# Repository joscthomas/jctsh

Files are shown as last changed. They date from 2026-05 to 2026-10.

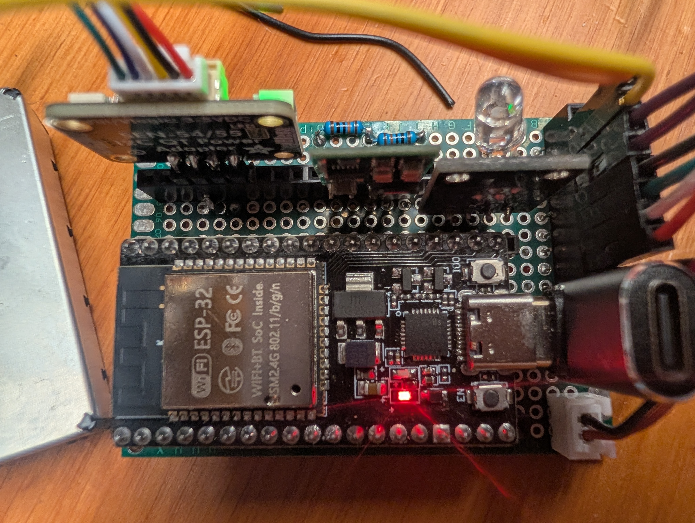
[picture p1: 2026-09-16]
components/air-quality-monitor/perfboard_3.jpg

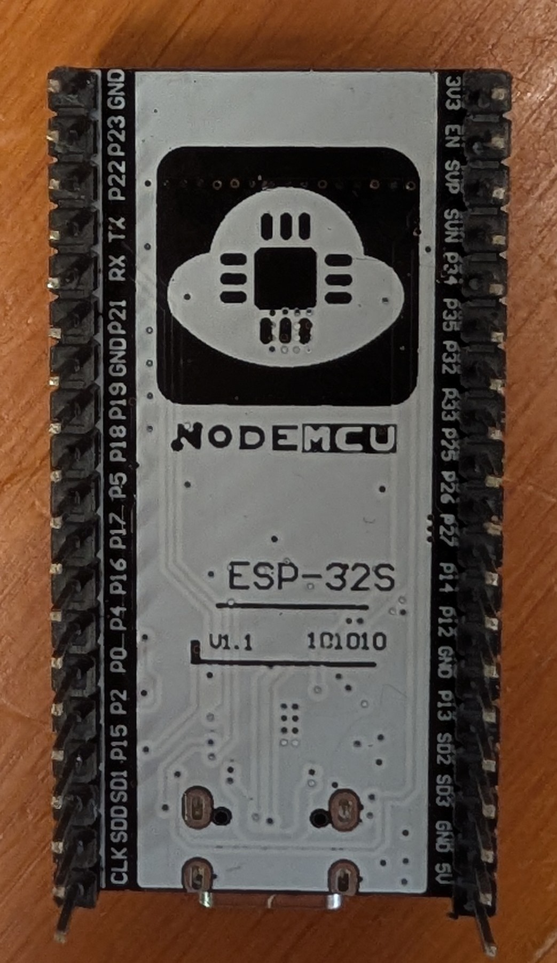
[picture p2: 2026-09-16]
components/back-patio-temp-sensor/esp32-pins-photo.jpg

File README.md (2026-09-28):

# JCTsh — Smart Home Automation
Joseph C Thomas | Tucson, AZ

DIY smart home automation system built on Raspberry Pi, MQTT, Node-RED, and Home
Assistant — connecting ESP32 sensors, garage automation, an RV coach interface, and
environmental monitoring into a single integrated ecosystem.

---

## System Status

| Component | What it does | Status |
|---|---|---|
| [salt-sensor](components/salt-sensor/) | Water softener salt level monitor with SmartThings alerts | Production |
| [garage-radar](components/garage-radar/) | 24GHz mmWave workbench presence sensor | Production |
| [garage-presence](components/garage-presence/) | Garage presence countdown timer and lights automation | Production |
| [traveling](components/traveling/) | Randomized occupancy-simulation lighting + unexpected-TV-activity alert while traveling | Production |
| [outdoor-presence-detection](components/outdoor-presence-detection/) | Ring motion voice announcement (doorbell live video deactivated 2026-08-21, CARD-0187 on hold) | Production |
| [automatic-garage-door-opener-closer](components/automatic-garage-door-opener-closer/) | Voice and auto-close control for LiftMaster opener | Production |
| [equip-shelf](components/equip-shelf/) | Physical shelf housing the Pi, M8, SmartThings hub, garage relay, router, and cooling fans | Production |
| [front-porch-temp-sensor](components/front-porch-temp-sensor/) | Front porch temperature, pressure, and light with push notifications | Production |
| [p-w-firefly](components/p-w-firefly/) | Firefly Integrations RV-C coach interface for Pleasure-Way Lexor FL | Production |
| [photo-server](components/photo-server/) | Self-hosted Immich photo/video library, runs on the M8 (`hosts/m8/`) | Production |
| [photo-quality-review](components/photo-quality-review/) | Finds duplicate/blurry/broken images across Immich libraries, review UI to confirm deletions | Production |
| [photo-tv-display](components/photo-tv-display/) | Ambient photo slideshow + phone controller for Google TV, backed by m8 | In Progress |
| [netalertx](components/netalertx/) | Translates NetAlertX's MQTT firehose into JCTsh-shaped log events + heartbeat | Production |
| [jctsh-menu](components/jctsh-menu/) | Tasker menu task routing to any component's webhook by name, not a running service | Production |
| [hiking-monitor](components/hiking-monitor/) | Portable environmental sensor — logs to flash during hikes, syncs on return | Production |
| [hike-izer](components/hike-izer/) | Turns raw hiking-monitor data into a narrative HTML hike summary | Production |
| [hike-izer-orchestrator](components/hike-izer-orchestrator/) | Webhook receiver/generator that triggers Hike-izer automatically | Production |
| [hike-izer-web](components/hike-izer-web/) | Publishes Hike-izer's generated summaries at `hikes.jctnet.com` | Production |
| [weather-station](components/weather-station/) | Outdoor DIY weather station posting to Weather Underground and Google Sheets | Planned |
| [air-quality-monitor](components/air-quality-monitor/) | Portable PM/VOC/NOx sensor carried on hikes alongside the hiking monitor | In Progress |
| [van-sensors](components/van-sensors/) | Indoor and outdoor environmental nodes for the Pleasure-Way ProMaster van | Planned |
| [remote-temp-sensor-01](components/remote-temp-sensor-01/) | Solar/battery-powered backyard temp, humidity, pressure, light, and UV sensor | Planned |
| [bedside-clock](components/bedside-clock/) | Battery-powered, tap-to-wake bedside clock for the camper van, DS3231-timed with occasional WiFi/NTP timezone correction | Planned |

---

## What It Is

JCTsh is a personal smart home automation system for a single-family home in Tucson,
Arizona, built entirely from off-the-shelf hardware and open-source software. It has no
cloud dependencies except Home Assistant Cloud (Nabu Casa) and SmartThings for phone and
voice integration.

Each component is a self-contained unit with its own firmware, Node-RED flow, and
documentation. All components share a common infrastructure layer — a Raspberry Pi running
Mosquitto, Node-RED, Home Assistant, and a Python log server.

---

## Quick Start — Accessing the System

All services run on the home Raspberry Pi. On the home network:

| Service | URL | Notes |
|---|---|---|
| Log dashboard | http://pi1.local/ | Basic Auth — user: `jctsh` |
| Node-RED | http://pi1.local:1880 | Flow editor |
| Home Assistant | http://pi1.local:8123 | |
| MQTT broker | pi1.local:1883 | Requires auth — credentials in `credentials.local.md` |

Remote access via Tailscale: replace `pi1.local` with `100.70.162.24`.

See [network/jctsh-access.md](network/jctsh-access.md) for the full access reference including RV and Tailscale setup.

---

## Architecture

Every component follows the same message flow:

```
ESP32 sensor
    │  MQTT publish
    ▼
Mosquitto broker  (Raspberry Pi)
    │
    ├──► Node-RED        — logic, thresholds, external HTTP calls
    │        │
    │        ├──► Google Sheets / Weather Underground
    │        └──► Home Assistant REST API
    │                  │
    │                  └──► SmartThings ──► Google Home / Pixel notifications
    │
    └──► Python log server  — http://pi1.local/
```

Each component produces two parallel message streams: a **data stream**
(`jctsh/<type>/<component>/data`) driving automations, and a **log stream**
(`jctsh/<type>/<component>/log`) routed to the dashboard.

For full architecture details, MQTT topic conventions, credentials structure, and
infrastructure configuration, see [CLAUDE.md](CLAUDE.md).

---

## Repository Layout

```
jctsh/
├── components/                    Individual automation components — one subdirectory each
├── core/                          Shared infrastructure running on the Raspberry Pi
├── tos/                           Team Operating System — kanban board, process definition,
│                                       and auto-PR intake/landing tooling (see tos/README.md)
├── CLAUDE.md                      Claude Code context — architecture, conventions, infrastructure
├── DEVLOG.md                      Chronological record of decisions and incidents
├── ENVIRONMENT.md                 Physical device inventory for the home
├── SOFTWARE-ENVIRONMENT.md        What is installed and running on the Pi
├── WORKSTATION-SETUP.md           What the dev/flashing workstation needs installed (Python,
│                                       ESPHome, SSH, filesystem gotchas) — CARD-0357
├── workstation-verify.ps1         Checks the workstation's actual state against
│                                       WORKSTATION-SETUP.md — verify-only — CARD-0360
├── network/jctsh-network.md       IP address and MAC table for all devices
├── network/jctsh-access.md        How to reach all services from any network
├── network/keepconnect.md         KeepConnect router rebooter — config, schedule, rationale
├── jctsh-parts-inventory.md       On-hand electronics parts
├── JCTsh-Build-Standards.md       Standards all components must follow
├── JCTsh-Component-Planning-Pattern.md  How new components are planned and built
├── JCTsh-Perfboard-Build-Template.md    Reusable section skeleton for a component's
│                                             perfboard-layout.md (breadboard → perfboard transfer)
├── core/data-pipeline/JCTsh-Environmental-Data-Architecture.md  Payload schema and pipeline
│                                             for all environmental sensors
├── JCTsh-Property-Sensor-Pattern.md         Standard pattern for all property sensors —
│                                             invariant standard, variable dimensions,
│                                             new-sensor checklist
└── house-lot-coordinates.md               Lat/lon for property corners, house footprint
                                              corners, and named points (e.g. front porch) —
                                              use these when hardcoding coordinates in firmware
```

### components/

One subdirectory per automation component. Each contains a `README.md` — see the
Status table above for the full list.

### core/

Shared infrastructure not specific to any one component.

| Directory | Contents |
|---|---|
| `core/data-pipeline/` | Environmental Data Apps Script + Node-RED flow — GPS/sensor correlation pipeline shared across hiking-monitor, air-quality-monitor, front-porch-temp-sensor, and back-patio-temp-sensor — see [core/data-pipeline/README.md](core/data-pipeline/README.md) |
| `core/homeassistant/` | HA configuration snapshot (version-controlled copy — live copy is on Pi) — see [core/homeassistant/README.md](core/homeassistant/README.md) |
| `core/logging/` | Python MQTT log server — see [core/logging/README.md](core/logging/README.md) |
| `core/mqtt/` | Mosquitto configuration (version-controlled copy) — see [core/mqtt/README.md](core/mqtt/README.md) |
| `core/node-red/` | Shared Node-RED flows and settings (version-controlled copies) |
| `core/offline-logger/` | Reusable offline flash logging template (`sensor_logger.h`) — copy and rename for each intermittently-connected sensor |
| `core/maintenance/` | Scheduled-reboot systemd units and maintenance/update-check scripts, deployed to the Pi and M8 — see [core/maintenance/README.md](core/maintenance/README.md) |
| `core/docker/` | Docker daemon config (DNS pinning, journald log driver, containerd data-root) for hosts running containers — see [core/docker/README.md](core/docker/README.md) |

---

## Document Types

| Document | Purpose | Where to find it |
|---|---|---|
| `README.md` | What a component does, how to run it, doc index | Every component directory |
| `CLAUDE.md` | Context and constraints for Claude Code sessions | Repo root + component directories |
| `kanban-board.md` | Kanban board — all planned and in-progress work | `tos/` |
| `DEVLOG.md` | Why decisions were made; significant incidents | Repo root |
| `*-phase1.md` / `*-planning.md` | Pre-build discovery — decisions, BOM, architecture choices | Component directory |
| `*-claude-code-instructions.md` | Step-by-step build instructions executed with Claude Code | Component directory |
| `JCTsh-*.md` | Monorepo-wide standards all components must conform to | Repo root |
| `wiring.md` | Pin assignments and breadboard wiring reference | Component directory |
| `ESP32-project-pins.md` | Full 38-pin assignment table for the component's ESP32 | Component directory |
| `perfboard-layout.md` | Permanent soldered build layout | Component directory |
| `flashing.md` | First flash and OTA update procedure | Component directory |
| `testing.md` / `end-to-end-test.md` | Test procedures and pass/fail criteria | Component directory |
| `integration.md` | How the component connects to HA, SmartThings, or other systems | Component directory |
| `operations.md` | Day-to-day use and troubleshooting | Component directory |
| `network/jctsh-network.md` | IP, hostname, and MAC for every device | `network/` |
| `network/jctsh-access.md` | How to reach every service from home, remote, or RV | `network/` |
| `credentials.local.md` | All generated passwords — gitignored, never committed | Repo root |

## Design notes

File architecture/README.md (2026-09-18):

# architecture/ — Cross-Cutting Architecture and Operational Decisions

Doc-only directory (no executable code) for cards that are genuinely cross-cutting —
not owned by any single component, core service, or host. Created 2026-09-18 (CARD-0294)
specifically to give the residual bucket of `[infrastructure]`-tagged cards a real home,
once host-specific and component-specific ones were retagged to `[m8]`/`[pi1]`/their
actual component.

**What belongs here:** strategy decisions spanning multiple systems (SmartThings API
strategy, MQTT security posture), standards that apply to a whole class of future
components rather than one existing directory (backyard-device power patterns, battery
build standards before they were harvested into `JCTsh-Build-Standards.md`), and
whole-repo audits (security hardening, disaster recovery, cross-host reboot behavior).

**What doesn't:** anything that fits a real `components/<name>/`, `core/<name>/`, or
`hosts/<name>/` directory once actually checked — see `JCTsh-Operating-System.md`'s
Engineering Discipline section on investigating before assuming a card can't be
reconciled.

## Files

| File | Purpose |
|---|---|
| `CLAUDE.md` | Curated context — currently a stub |
| `card-archive.md` | Archived `[architecture]`-tagged card history (created on first use by `archive_cards.py`) |

## Related

- `kanban-board.md` CARD-0294 — the tag reconciliation that created this directory.
- `JCTsh-Operating-System.md`'s Documentation Structure section — the README-vs-CLAUDE.md
  split this directory follows like any other.

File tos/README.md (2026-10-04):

# tos/ — Team Operating System

CARD-0191: this directory consolidates JCTsh's "Team Operating System" (TOS) —
the kanban board itself, the process governing how work moves through it, and
the tooling that lets ideas/findings get onto the board from outside a
Claude Code session (voice, email, automated maintenance checks). Before
this, these pieces were scattered across the repo by whichever
infrastructure happened to be convenient to host them on, not by any
conceptual grouping — see CARD-0191 on `kanban-board.md` for the full
before/after inventory.

**Start with `JCTsh-Operating-System.md` for the actual process definition**
(board columns, state-transition triggers, the Build → Done Reflection
requirement, the commit/push relationship). This file is the index of what's
here and how the pieces fit together — it doesn't repeat that content.

## What's here

| File | Role |
|---|---|
| `kanban-board.md` | The board itself — every card, its status, and its full history. |
| `kanban-archive.md` | Dated archive of Done/Defer cards moved out of `kanban-board.md` by size, when no single `components/<name>/`/`core/<name>/`/`hosts/<name>/` home fits (CARD-0193). |
| `archive_cards.py` | The archiving tool behind `kanban-archive.md` and every `card-archive.md` below — size-primary trigger, `--force`/`--apply` dry-run-by-default, provenance annotations (CARD-0193). Manual, not on a timer — see `CLAUDE.md`'s periodic Session Start reminder. |
| `CLAUDE.md` | This directory's own curated context stub — archived card history lives in `card-archive.md` instead (CARD-0290). |
| `card-archive.md` | `[tos]`-tagged cards' archived history, split out of `CLAUDE.md` (CARD-0290). On-demand only, never routine reading — same pattern every `components/<name>/`/`core/<name>/`/`hosts/<name>/` directory now follows. |
| `JCTsh-Operating-System.md` | The process definition — columns, triggers, Reflection requirement, Engineering Discipline, Documentation Structure. Read once per session (see `CLAUDE.md`'s Session Start). |
| `JCTsh-Session-Card-Selection.md` | Four ordered factors for which card a session actually picks up next, distinct from the Priority tag (CARD-0288). |
| `JCTsh-Component-Session-Start.md` | Extended startup steps for a persistent component/cluster session, on top of `CLAUDE.md`'s general Session Start (CARD-0284/CARD-0290). |
| `open_kanban_pr.py` | `open_finding_pr()` / `resolve_and_merge()` — opens a placeholder-stub PR against `kanban-board.md` for any finding/idea, and lands a reviewed PR as a real numbered card at merge time. Imported (as a sibling module) by `email-idea-check.py`, `pi-maintenance-check.py`, `maintenance-check.py`, and `hike-izer-orchestrator`'s `/webhook/idea` route. |
| `land_pr_card.py` | Interactive-only script Claude runs (never automated) to land a PR as a fully-interviewed, real card — not just a renumbered stub. See its own docstring for the distinction from `resolve_and_merge()`. |
| `pr-review-checklist.md` | Step-by-step checklist for reviewing/handling a PR from this pipeline — which merge-time path to use, the interview steps, and the confirm-before-landing step. Points at the scripts above for mechanics rather than repeating them. |
| `email-idea-check.py` + `.service`/`.timer` | Polls `joscthomas+kbc@gmail.com` every 30 min for `jctsh-idea` emails (CARD-0151), calls `open_finding_pr()` for each. Deployed to the Pi. |
| `kanban-pr-selftest.py` + `.service`/`.timer` | Daily self-test of the auto-PR intake pipeline itself (CARD-0192) — opens and closes a real PR against a test component so a broken pipeline is caught before a real finding needs it. |
| `tasker-setup.md` | The `Log Idea` Tasker build steps — home-screen voice-capture widget feeding `/webhook/idea` (CARD-0241, moved here from `hike-izer-orchestrator`'s README since it's a TOS feature, not a hiking one). |
| `Log-Idea.tsk.xml` | Exported Tasker Task backing `tasker-setup.md`, committed as diffable ground truth against the prose doc (CARD-0231). |
| `credential-registry.yaml` | Values-free inventory of every credential this project has — where it lives, tier/cadence, exposure/rotation/retirement history (CARD-0372, seeded by CARD-0334 Step 0). Never a value; schema documented at the top of the file. |
| `secret.py` | The real `secret` helper (CARD-0372/CARD-0334), M8-hosted (moved off Windows 2026-10-02) — wraps `keepassxc-cli` against `/home/jct/.jctsh-vault/jctsh-vault.kdbx`. Deployed to `/usr/local/bin/secret.py` on the M8, same convention as `maintenance-check.py`. `init`/`has`/`ls`/`fingerprint`/`new`/`copy`/`set`/`run`/`reach`, plus the rotation primitives `rotate.py` drives: `stage`/`promote`/`unpromote`/`discard-next`/`drop-previous` (a rotation keeps `<name>.next`/`<name>`/`<name>.previous` in the vault) and `envfile` (edits `KEY=VALUE` lines locally or over SSH, values on stdin only, atomic, then an optional restart). Every vault write takes an exclusive lock. |
| `secret.ps1` | Thin Windows-side SSH wrapper around `secret.py` on the M8 — every vault-touching command relays over `ssh jct@m8.local`, a value crossing back lands straight on the clipboard, never printed. `due` is the exception: a fully local, values-free scan of `credential-registry.yaml` (no M8 round-trip), meant to be run from `JCTsh-Session-Start.md`'s step 9. |
| `rotate.py` | The rotation runner (CARD-0372). Runs on the workstation next to the registry and never sees a value: vault work is `secret.py` on the M8 over SSH, and a value a person must paste goes M8 → clipboard via `secret.ps1 copy`. `plan`/`verify`/`start`/`continue`/`status`/`confirm-synced`/`finish`/`abort`. Holders with an `apply:` map are updated and checked automatically; the rest are guided steps that wait for you. Values-free state in `tos/.rotation-state/` (gitignored) lets a rotation pause and resume; writes `roboform_synced`/`last_rotated`/`rotation_requested` back to the registry. |
| `rotate.ps1` | Shim: passes its arguments to `rotate.py`. |

## The auto-PR intake pipeline

Three independent entry points all funnel into the same `open_finding_pr()`,
so a voice-captured idea, an emailed idea, and an automated maintenance
finding all produce identically-shaped placeholder PRs:

```
Tasker "Log Idea" widget ──► /webhook/idea (hike-izer-orchestrator) ──┐
joscthomas+kbc@gmail.com ──► email-idea-check.py ─────────────────────┼──► open_finding_pr()
maintenance-check.py / pi-maintenance-check.py (scheduled findings) ──┘         │
                                                                                  ▼
                                                          Real PR opened against `main`,
                                                          zero file diff (CARD-0190) —
                                                          finding text lives in the PR's
                                                          own title/body only
                                                                                  │
                                                                                  ▼
                                            Claude reviews, then runs resolve_and_merge()
                                            (auto-generated stub) or land_pr_card.py
                                            (real interviewed card) — this is the only
                                            point that actually reads/writes kanban-board.md
```

See `pr-review-checklist.md` for the step-by-step review/handling procedure.

Nothing writes to `kanban-board.md` except at merge time, and only through
one of the two merge-time functions above — see CARD-0190's card text for
why (`kanban-board.md` crossed GitHub's 1MB Contents API content-size limit
in August 2026; every read of it now uses the `application/vnd.github.raw`
media type instead of the size-limited JSON `content` field).

## Auto verify markers

A separate mechanism from the intake pipeline above — this one's about not
forgetting a follow-up on a card that's already on the board, when the thing
being waited on won't happen until later. Two flavors, one literal keyword
kept deliberately distinct per flavor so each reads naturally in its own
card's prose (CARD-0251):

| Flavor | Marker syntax | For a check that depends on... | Checked how |
|---|---|---|---|
| Date-based | `**Auto verify: <date>**` | a known future date/event (a scheduled reboot, a timer firing) | `CLAUDE.md` Session Start step 4 greps `kanban-board.md`, follows through once the date has passed |
| Event-based | `**Watch for:** <description>` | a real-world condition of unknown future timing (typically a specific log message) | `CLAUDE.md` Session Start step 5 greps `kanban-board.md`, then greps the Pi's durable log (`/mnt/jctsh-logs/jctsh.log*`, including rotated backups) for the stated pattern |

Both flavors exist because the board's own 7-day recently-updated Session
Start check (see `CLAUDE.md`) isn't enough — a card can sit untouched far
longer than that while still genuinely waiting on its marker, and would
otherwise never resurface on its own.

Implemented entirely in `core/logging/log_server.py` (not this directory) —
`_parse_kanban_board()` extracts either marker into the card dict
(`auto_verify`/`watch_for`), `cardHtml()` renders it as a badge on the
card's `/kanban` header, and `render()`'s per-column sort pushes any
marker-carrying card to the end of its column, since it's passively waiting
and doesn't need attention right now. See `kanban-board.md` CARD-0251 for
the full build history, and CARD-0249/CARD-0224 for each flavor's origin
case.

## Deploy

`open_kanban_pr.py` has **no single canonical deployed location** — it's a
plain sibling-import module, so a copy has to sit next to every script that
imports it:

| Deployed copy | Host | Alongside | Redeploy command |
|---|---|---|---|
| `/usr/local/bin/open_kanban_pr.py` | Pi | `pi-maintenance-check.py`, `email-idea-check.py` | `scp tos/open_kanban_pr.py pi@pi1.local:/usr/local/bin/` |
| `/usr/local/bin/open_kanban_pr.py` | M8 | `maintenance-check.py` | `scp tos/open_kanban_pr.py jct@m8.local:/usr/local/bin/` |
| `~/hike-izer-web-app/orchestrator/open_kanban_pr.py` | M8 (Docker) | `hike-izer-orchestrator`'s `app.py` | See `components/hike-izer-orchestrator/README.md`'s deploy section — requires a `docker compose up -d --build orchestrator`, not just an `scp`. |

**Any change to `open_kanban_pr.py` needs all three redeployed**, not just
one — CARD-0190's original fix only redeployed the Docker copy and missed
both `/usr/local/bin/` copies, which stayed broken until CARD-0191 caught it.

`land_pr_card.py` is never deployed — it's run locally from this repo
checkout by Claude. GitHub PAT: `secret.ps1 run-local -Name github-pat-maintenance
-EnvVar GITHUB_PAT -- python tos/land_pr_card.py ...` (CARD-0372, 2026-10-03) is the
preferred way to invoke it now — falls back to `credentials.local.md` (gitignored,
repo root) unchanged if `$GITHUB_PAT` isn't set.

`email-idea-check.py` deploys to the Pi as `/usr/local/bin/email-idea-check.py`,
managed by `email-idea-check.service`/`.timer` (`systemctl daemon-reload` after
changing the unit files themselves; a plain code change only needs the script
re-copied and, if `Type=oneshot`, no restart is needed — it just runs fresh on
the timer's next tick).

## Related

- `kanban-board.md` CARD-0191 — the consolidation this directory is the result of, full inventory and reasoning.
- `kanban-board.md` CARD-0190 — the 1MB Contents API bug this whole pipeline had to be redesigned around.
- `kanban-board.md` CARD-0192 — the daily self-test behind `kanban-pr-selftest.py`, built and running.
- `kanban-board.md` CARD-0193 — kanban board scaling/archival strategy, including why a database was considered and ruled out.
- `kanban-board.md` CARD-0251 — Auto verify markers (date-based + event-based), the follow-up-reminder mechanism described above.
- `kanban-board.md` CARD-0231/CARD-0241 — `Log-Idea.tsk.xml`/`tasker-setup.md`'s origin (Tasker export-as-ground-truth pattern; moving Tasker build docs to their conceptual owner, not their hosting container).
- `kanban-board.md` CARD-0284 — persistent per-cluster/component sessions, the origin of `JCTsh-Component-Session-Start.md`.
- `kanban-board.md` CARD-0288 — Session Card Selection, the origin of `JCTsh-Session-Card-Selection.md`.
- `kanban-board.md` CARD-0289 — the documentation-splitting-by-read-frequency principle this directory's own file layout follows.
- `kanban-board.md` CARD-0290 — the `CLAUDE.md`/`card-archive.md` split, applied to this directory's own `CLAUDE.md` among every other component/core/host directory.

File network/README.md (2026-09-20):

# network/ — DNS, Domains, and Network-Level Concerns

Doc-only directory (no executable code) for cards about external network/DNS concerns —
`jctnet.com`/`jctnet.net` DNS records, domain configuration — that don't belong to any
single component, core service, or host. Created 2026-09-19, alongside deprecating the
generic `[personal]` tag (`kanban-board.md` CARD-0316) — DNS cleanup work had been tagged
`[personal]` even though it's genuinely operational/network work, not personal-life
content, once actually looked at.

**What belongs here:** DNS record management, domain-level configuration, and similar
network-layer decisions that span or predate any specific host/component.

**What doesn't:** local/LAN device networking that's actually a specific host or
component's own concern (e.g. a device's own WiFi config) — that stays tagged to the
owning component/host, same as always.

## Files

| File | Purpose |
|---|---|
| `CLAUDE.md` | Curated context — currently a stub |
| `card-archive.md` | Archived `[network]`-tagged card history (created on first use by `archive_cards.py`) |

## Related

- `kanban-board.md` CARD-0316 — deprecating `[personal]`, the reason this directory exists.
- `architecture/README.md` — the same doc-only, no-component-home pattern, for the
  cross-cutting-decisions case instead of the network-specific one.

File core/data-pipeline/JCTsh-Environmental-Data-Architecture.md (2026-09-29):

# JCTsh Environmental Data Architecture
**Author:** Joseph C Thomas (JCT)
**Purpose:** Defines the architecture for JCTsh environmental sensor data — the standard message payload, TimescaleDB archive design, Node-RED data handler pattern, Weather Underground integration, and the planned environmental sensor family. All environmental sensor components must conform to this standard.
**Version:** 1.7
**Version description:** CARD-0366 (2026-09-29) — storage is now TimescaleDB, not Google Sheets (CARD-0349): the Sheets Archive section is rewritten as the Storage section, the Node-RED handler steps and gap handling updated, and the Hiking Observations / Hike Start Forecast sheet schemas marked as tables. Payload standard unchanged. Prior: CARD-0291 (fifth pass) — Sheets Structure table reconciled against `environmental-data.gs`, which it had drifted from: added `GPS Track`, `Wildlife Detections`, `Timeline`, and `Correlation Debug` (all four really written by the script, none previously listed), marked `Lightning Events` as planned/not-yet-created (no code path writes it; `weather-station` isn't built), and labeled `Timeline`/`Correlation Debug` as derived/diagnostic rather than archive sheets so neither is mistaken for a source of record. No change to the payload schema, the handler pattern, or any sheet's own column schema.
**Project:** JCTsh — Smart Home Automation
**Related files:** `README.md`, `CLAUDE.md`, `ENVIRONMENT.md`, `JCTsh-Build-Standards.md`, `JCTsh-Component-Planning-Pattern.md`

---

> **Storage status, 2026-09-29 (CARD-0349, CARD-0366).** Everything below the payload
> standard that says "Sheet" or "Apps Script" describes the retired system unless it says
> otherwise. The archive is a TimescaleDB database behind `data-pipeline-api`; **`init/schema.sql`
> is the authority on columns**, and `README.md` is the operational reference. The payload
> standard, derived fields and handler pattern are unchanged and still binding.

## Purpose and Scope

This document defines the data architecture for JCTsh environmental sensors — any sensor that measures physical conditions (temperature, humidity, pressure, wind, rain, UV, air quality, etc.) at a fixed or mobile location.

The weather station is the first component in this family. All subsequent environmental sensors (porch sensor, hiking monitor, Pleasure-Way node) must conform to the payload standard and data handler pattern defined here. This ensures a single Google Sheets archive captures all environmental data across all devices, and a single Node-RED data handler routes it correctly without per-device changes.

---

## Core Principles

**Lat/lon is a first-class field.** Every environmental data message carries `lat` and `lon` regardless of whether the device is fixed or mobile. Fixed sensors hardcode their coordinates in firmware. Mobile sensors with GPS hardware source them from the GPS module. Mobile devices without GPS hardware send JSON `null` for both fields — this is the correct value, not zero (0,0 is a real location in the Gulf of Guinea). Timestamp correlation with an external GPS track (e.g. GaiaGPS) is used instead. This makes every record self-contained and the null signals clearly that no GPS data is available for that reading.

**Node-RED owns external posting.** ESP32 devices publish to MQTT only. Node-RED handles all HTTP calls to Weather Underground, the data-pipeline gateway, and any other external service. This keeps ESP32 wake cycles fast, retry/error logic centralized, and battery life maximized.

**One archive, many sources.** The TimescaleDB environmental archive receives data from all environmental sensors via a single Node-RED wildcard subscription. Adding a new sensor requires no changes to the archive schema or handler — the `component` field identifies the source in every row.

**Rain accumulation lives in Node-RED.** Raw tip counts from rain gauges are published by ESP32. Node-RED maintains the rolling 60-minute window and daily accumulator. This is more reliable than preserving state across deep sleep cycles in ESP32 RTC memory, and keeps Weather Underground calculations in an always-on process.

**Observations are a separate stream.** Free-text voice observations from hikes are architecturally distinct from numeric sensor readings — different payload, different schema, different Sheets tab. They are correlated to the sensor data stream and GaiaGPS track by timestamp, not by being mixed into the same rows.

---

## Standard Environmental Message Payload

All environmental sensor components publish data to `jctsh/components/<name>/data` using this JSON structure. Fields that a given sensor does not measure are omitted — do not send null or zero for absent sensors. Exception: `lat` and `lon` must always be present — send JSON `null` if no GPS hardware is available.

```json
{
  "component": "weather-station",
  "ts": "2026-05-21T14:32:00Z",
  "lat": 32.2226,
  "lon": -110.9747,
  "temp_f": 98.4,
  "humidity_pct": 12.3,
  "pressure_hpa": 1005.2,
  "uv_index": 9.2,
  "irradiance_wm2": 887.0,
  "wind_speed_mph": 8.1,
  "wind_dir_deg": 225,
  "rain_tips": 3,
  "battery_v": 3.94,
  "rssi_dbm": -67
}
```

### Field Reference

| Field | Type | Unit | Required | Notes |
|---|---|---|---|---|
| `component` | string | — | ✅ Always | Matches the MQTT component name — used as `source` in the archive |
| `ts` | string | ISO 8601 UTC | ✅ Always | From DS3231 RTC or NTP-synced system clock |
| `lat` | number or null | decimal degrees | ✅ Always | Fixed constant for fixed sensors; GPS value for mobile sensors with GPS hardware; JSON `null` for mobile sensors without GPS (e.g. hiking monitor) |
| `lon` | number or null | decimal degrees | ✅ Always | Same as `lat` — never omit, never send 0 |
| `temp_f` | number | °F | if available | Primary temperature reading |
| `humidity_pct` | number | % RH | if available | Relative humidity |
| `pressure_hpa` | number | hPa | if available | Barometric pressure |
| `uv_index` | number | UVI | if available | UV index — LTR-390 sensor (UVA + UV Index); filter `lat IS NOT NULL` in queries when doing location-based analysis |
| `irradiance_wm2` | number | W/m² | if available | Solar irradiance (SI1145) |
| `wind_speed_mph` | number | mph | if available | Anemometer reading |
| `wind_dir_deg` | number | 0–359° | if available | Wind vane reading |
| `rain_tips` | integer | tips since last reading | if available | Raw tip count — Node-RED computes accumulations |
| `battery_v` | number | V | if battery-powered | LiPo voltage from ADC |
| `rssi_dbm` | integer | dBm | ✅ Always | WiFi signal strength — useful for deployment diagnostics |
| `pm1_ug_m3` | number | µg/m³ | if available | PM1.0 particulate matter — air quality monitor (SEN55) |
| `pm25_ug_m3` | number | µg/m³ | if available | PM2.5 particulate matter — air quality monitor (SEN55); primary AQI metric |
| `pm4_ug_m3` | number | µg/m³ | if available | PM4.0 particulate matter — air quality monitor (SEN55) |
| `pm10_ug_m3` | number | µg/m³ | if available | PM10 particulate matter — air quality monitor (SEN55) |
| `voc_index` | number | VOC index (1–500) | if available | VOC index — air quality monitor (SEN55); 100 = typical clean air |
| `nox_index` | number | NOx index (1–500) | if available | NOx index — air quality monitor (SEN55); 1 = typical clean air |
| `illuminance_lx` | number | lux | if available | Ambient light level — BH1750 sensor |
| `solar_v` | number | V | if solar-powered | Solar panel voltage from ADC voltage divider — combined with `battery_v`, distinguishes charging (solar_v > battery_v + ~0.3V) from draining |

### Derived Fields (computed by Node-RED, not sent by ESP32)

| Field | Computed from | Used for |
|---|---|---|
| `dew_point_f` | `temp_f` + `humidity_pct` | the archive, HA entity |
| `heat_index_f` | `temp_f` + `humidity_pct` | the archive, HA entity |
| `rainin` | rolling 60-min `rain_tips` sum | Weather Underground |
| `dailyrainin` | midnight-to-now `rain_tips` sum | Weather Underground |

---

## Storage Archive (TimescaleDB)

*Replaces the Google Sheets archive (CARD-0349, 2026-09-28/29). The workbook and
`environmental-data.gs` are retired; the old sheet design is preserved in git history and
`timescaledb-migration-plan.md`.*

### Purpose

The TimescaleDB environmental archive is the permanent, queryable record of all JCTsh
environmental sensor data. It is the authoritative data store — Weather Underground is a
display window, not an archive.

### Access

Node-RED posts to `data-pipeline-api` (`POST /environmental-data`) — a small HTTP gateway on
the M8 in front of the database. Authentication is a shared secret in the URL (`?key=`), no
OAuth. The gateway URL and key are stored in Node-RED environment variables
(`DATA_PIPELINE_URL`, `DATA_PIPELINE_KEY`), not in source control. Routes, deployment and
backup are in `README.md`.

### Tables

Defined in `init/schema.sql`. Replaces the workbook's sheets one for one, except the two
derived/diagnostic sheets:

| Table | Contents |
|---|---|
| `environmental_data` | One row per sensor reading — all environmental sensor sources. The canonical archive. Hypertable on `ts`; unique on `(ts, source)`. |
| `gps_track` | One row per GPS fix (`ts`, `lat`, `lon`, `accuracy_m`, `altitude_m`, `direction`), sent straight to the gateway by GPSLogger on the phone via `GET /gps` — never through MQTT or Node-RED. Every other table's coordinate back-fill is resolved against this one (`GET /lookup-gps`). |
| `hiking_observations` | One row per voice observation — see Hiking Observations Architecture below. |
| `hike_start_forecast` | One row per detected hike session — a live weather-forecast snapshot captured at that moment; see Hike Start Forecast Architecture below. |
| `wildlife_detections` | One row per species per hike (`ts`, `hike_file_stem`, `common_name`, `scientific_name`, `count`, `best_confidence`, `lat`, `lon`), posted by hike-izer's BirdNET pass and deduplicated on (hike, species). |
| `hike_izer_cost` | One row per hike-izer generation run — generation telemetry, not sensor data. |
| `Lightning Events` *(planned)* | One row per lightning strike event from the weather station's AS3935 detector. **Not yet created**, because `weather-station` isn't built; see MQTT Lightning Topic below. |

The workbook's `Timeline` (a derived view) and `Correlation Debug` (a diagnostic) were not
carried over: the merged timeline is a query away, and correlation diagnostics are the
gateway's own container log (`docker logs data-pipeline-api`).

### Environmental Data Schema

One table, one row per reading, all sources. The `source` column is populated from the
`component` field in the MQTT payload. (Authoritative column list: `init/schema.sql`.)

| Column | Source | Notes |
|---|---|---|
| `ts` | `ts` from payload | `timestamptz`; ISO 8601 UTC on the wire |
| `source` | `component` from payload | e.g. `weather-station`, `porch-sensor`, `hiking-monitor`, `air-quality-monitor` |
| `lat` | `lat` from payload | Decimal degrees, or null for devices without GPS |
| `lon` | `lon` from payload | Decimal degrees, or null for devices without GPS |
| `temp_f` | `temp_f` | °F |
| `humidity_pct` | `humidity_pct` | % RH |
| `pressure_hpa` | `pressure_hpa` | hPa |
| `dew_point_f` | computed by Node-RED | °F |
| `heat_index_f` | computed by Node-RED | °F |
| `uv_index` | `uv_index` | UVI |
| `irradiance_wm2` | `irradiance_wm2` | W/m² |
| `wind_speed_mph` | `wind_speed_mph` | mph |
| `wind_dir_deg` | `wind_dir_deg` | 0–359° |
| `rain_tips` | `rain_tips` | raw tip count |
| `rainin` | computed by Node-RED | inches, rolling 60 min |
| `dailyrainin` | computed by Node-RED | inches, midnight to now |
| `battery_v` | `battery_v` | V |
| `rssi_dbm` | `rssi_dbm` | dBm |
| `pm1_ug_m3` | `pm1_ug_m3` | µg/m³ — NULL for non-AQ devices |
| `pm25_ug_m3` | `pm25_ug_m3` | µg/m³ — NULL for non-AQ devices |
| `pm4_ug_m3` | `pm4_ug_m3` | µg/m³ — NULL for non-AQ devices |
| `pm10_ug_m3` | `pm10_ug_m3` | µg/m³ — NULL for non-AQ devices |
| `voc_index` | `voc_index` | VOC index — NULL for non-AQ devices |
| `nox_index` | `nox_index` | NOx index — NULL for non-AQ devices |
| `illuminance_lx` | `illuminance_lx` | lux — NULL for sensors without BH1750 |
| `solar_v` | `solar_v` | V — NULL for non-solar devices |

Columns for fields a given sensor does not provide are NULL for that row. Do not add per-device columns — all sources use the same schema. The physical range checks on `temp_f`, `humidity_pct`, `pressure_hpa` and `uv_index` are `CHECK` constraints in the database.

### Analysis Capabilities

Because every row is self-contained (timestamp + source + location + readings), plain SQL (DBeaver over an SSH tunnel to the M8, or `GET /export`) covers:

- Filter by `source` to isolate one device
- Filter by date range for seasonal or storm analysis
- Chart any field over time
- Pivot or self-join to compare sources side-by-side (e.g. porch vs. weather station temperature delta)
- Import into Google Maps or GIS tools using `lat`/`lon` columns directly — filter `lat IS NOT NULL` to exclude devices without GPS
- Join hiking monitor rows to GaiaGPS track by matching `timestamp` to GPX trackpoint timestamps
- Correlate air quality monitor PM2.5 with hiking monitor UV index and pressure to characterize hike conditions fully
- Join Environmental Data rows to Hiking Observations rows by matching `timestamp` — nearest sensor reading to any observation reveals conditions at the moment of observation

---

## Node-RED Data Handler

### Subscription

The data handler subscribes to `jctsh/components/+/data` (wildcard). Any environmental sensor publishing on this pattern is automatically captured. No per-device Node-RED changes are needed when a new sensor is added.

### Handler Responsibilities

On each received data message the handler:

1. Parses the JSON payload
2. Splits off diagnostic events (skip/reset/display-refresh) to the component's log topic; everything else is an environmental reading. (Hiking observations no longer pass through Node-RED — Tasker posts them straight to the gateway.)
3. Computes derived fields (`dew_point_f`, `heat_index_f`, `rainin`, `dailyrainin`) for environmental readings
4. Posts to the gateway (`POST /environmental-data`) through a serial queue with retry
5. Posts to Weather Underground (weather station only — filtered by `component === "weather-station"`)
6. Updates Home Assistant entities via REST API
7. Routes SmartThings-exposed values (temperature, rain active, lightning) via HA

### Rain Accumulation State

The handler maintains two in-memory accumulators per rain-gauge-equipped device:

- **Rolling 60-minute buffer** — timestamped list of tip events; sum tips within the last 60 minutes to compute `rainin`
- **Daily accumulator** — running total of tips since midnight (America/Phoenix timezone); reset at 00:00 each day

These are Node-RED flow context variables, persistent across redeploys via the Node-RED context store.

### Offline / Gap Handling

If the Node-RED handler cannot reach the gateway or Weather Underground (network issue, service outage), it logs the failure to `jctsh/core/log-server/log` and continues; gateway writes are queued in memory and retried, and discarded only after 24 hours. SD card logging on the ESP32 provides a local backup for gap recovery. WU does not support backfill — gaps in WU data are permanent. Gaps in the database can be backfilled from SD card logs or a device's own replay if needed.

---

## Hiking Observations Architecture

### Overview

Voice observations recorded during hikes using Google Recorder on the Pixel 10 Pro XL. Observations beginning with the keyword "observation" are automatically identified, transcribed, classified by category, and archived in the Hiking Observations sheet. Correlated to environmental sensor data and GaiaGPS track by timestamp.

No ESP32 or dedicated hardware required. Entirely a phone + Google Apps Script + Sheets pipeline.

### Observation Payload

Observations publish to `jctsh/components/hiking-observations/data` using this structure:

```json
{
  "component": "hiking-observations",
  "ts": "2026-05-27T09:14:33Z",
  "lat": null,
  "lon": null,
  "observation": "saw first saguaro bloom of the season, about halfway up the north slope",
  "categories": ["vegetation"],
  "source": "voice"
}
```

| Field | Notes |
|---|---|
| `component` | Always `hiking-observations` |
| `ts` | Timestamp of the recording — not the time of processing or publishing |
| `lat`, `lon` | Always null — timestamp correlation to GaiaGPS track used for position |
| `observation` | Full transcript text with keyword prefix stripped |
| `categories` | Array of matched categories — computed by Apps Script keyword scan, not entered manually |
| `source` | Always `voice` (Tasker's on-device "Get Voice" transcription); reserved for future observation types |

### Keyword Trigger

No keyword prefix required. The Tasker widget tap is the intent signal — whatever is spoken after tapping the widget is recorded as an observation. The Apps Script stores the full transcript as-is.

### Category Taxonomy

Categories are assigned automatically by keyword scan of the observation text. Multiple categories may apply. Categories are stored as a JSON array in the `categories` column.

| Category | Example keywords |
|---|---|
| `vegetation` | saguaro, bloom, cactus, tree, shrub, flower, plant, grass, palo verde, ocotillo |
| `wildlife` | bird, hawk, coyote, snake, rabbit, deer, javelina, lizard, butterfly, insect |
| `weather` | cloud, rain, wind, storm, thunder, lightning, temperature, hot, cold, warm, cool |
| `visibility` | clear, hazy, smoke, dust, fog, smoggy, murky |
| `sky` | moon, sun, stars, sunrise, sunset, rainbow, shadow |
| `air_quality` | smoky, dusty, smell, odor, particulate, ash |
| `trail` | trail, path, wash, ridge, peak, summit, canyon, rock, boulder, erosion |
| `subjective` | feels, seems, appears, noticed, unusual, different, surprising |

The taxonomy is extensible — add keywords and categories in the Apps Script processor as needed. No schema changes required to add a new category.

### Hiking Observations Sheet Schema

> *Historical — this was the Sheets column layout. It is now the `hiking_observations` table; `init/schema.sql` is authoritative.*

Separate sheet in the same Google Sheets workbook as Environmental Data.

| Column | Source | Notes |
|---|---|---|
| `timestamp` | `ts` from payload | ISO 8601 UTC — join key to Environmental Data and GaiaGPS track |
| `observation` | `observation` from payload | Full transcript text, keyword prefix stripped |
| `categories` | `categories` from payload | JSON array as string, e.g. `["vegetation","wildlife"]` |
| `source` | `source` from payload | `voice` for Google Recorder |

### Timestamp Correlation

The `timestamp` column is the join key across all three data streams:

- **Environmental Data sheet:** `=VLOOKUP(A2, 'Environmental Data'!A:B, 2, TRUE)` finds the nearest sensor reading to the observation timestamp
- **GaiaGPS track:** GPX trackpoint timestamps correlated manually or via export tool
- All three streams together give: where you were + what conditions were + what you observed

### Implementation (as actually built, CARD-0156 — corrected 2026-09-02, CARD-0225)

> *Historical as to the receiving end: since CARD-0349 the POST goes to `data-pipeline-api`'s `/hiking-observations` (not an Apps Script `doPost`), which does the same keyword scan and coordinate back-fill and writes the `hiking_observations` table. The Tasker side and the direct-HTTP reasoning are unchanged.*

The two-path Google Recorder/Drive-folder design below was the original plan; it was never built. What actually shipped is simpler and has no MQTT step at all:

1. Tap the "Log Observation" widget on the Pixel — Tasker's **Get Voice** action transcribes on-device, no manual share step, no Drive folder, no keyword prefix required (the widget tap itself is the intent signal).
2. The transcript is written to a small on-device queue file (resilient to connectivity gaps, CARD-0156) and flushed via a direct **HTTP POST** to the Apps Script endpoint (`doPost`, `component: "hiking-observations"`) — as soon as the phone is online, no polling, no scheduled trigger.
3. `doPost` itself does the keyword-taxonomy category scan, builds the row, and appends directly to the Hiking Observations sheet — there is no separate "Apps Script processor" triggered by a Drive file or an MQTT message; it's one function, one write.
4. Google Apps Script has no MQTT client capability at all (`UrlFetchApp` only, no raw sockets) — this pipeline is direct HTTP end to end, matching GPS Track's own shape. See `CLAUDE.md`'s "MQTT vs. Direct HTTP" section for why that's the correct shape, not a gap.

Full build detail — every real-device quirk, the offline-queue design, the two auto-flush triggers — is `components/hiking-monitor/observations-pipeline.md`, the authoritative current-state reference. (The original "Path A: manual Drive-folder share" / "Path B: Tasker → MQTT" two-phase plan this section used to describe was superseded before either was built — CARD-0156 built the direct-HTTP design above instead.)

---

## Hike Start Forecast Architecture

### Overview

A live snapshot of what the weather forecast *was* at the moment a hike began — captured once, server-side, then frozen. Distinct from a forecast re-checked whenever a Hike-izer summary happens to be generated later, and distinct from actual historical/observed conditions (a separate, still-undecided item — see CARD-0074). Added for CARD-0083.

### Trigger

Captured by the same Apps Script `doPost` handler that already processes every Hiking Observation (see Hiking Observations Architecture above) — no new mobile automation, no new Tasker/Node-RED work. On each incoming observation, the handler computes the Arizona-local calendar date and checks whether a forecast has already been captured for that date. If not, and if the observation resolved a GPS position via the existing `_gpsLookup` correlation, it fetches and stores a forecast. If GPS hasn't resolved yet for this particular observation, capture is skipped for it (not defaulted to a home-area location) — a later observation the same day with a resolved position will retry.

This makes the *first* Hiking Observation of a hike the de facto trigger in practice, though the actual condition checked is "not yet captured today with a resolved GPS position," not literally "observation #1."

### Provider

[Open-Meteo](https://open-meteo.com) (`api.open-meteo.com`) — free, no API key or account required. Its hourly forecast endpoint returns temperature, relative humidity, precipitation probability, wind speed, and UV index in a single call, covering the full content scope Hike-izer needs without a second provider or any credential management.

Open-Meteo has no named "nearest station" concept, unlike NWS/METAR-based sources which snap to an airport or gridpoint office — it's a gridded numerical model interpolated to the exact coordinate requested. The response's own `latitude`/`longitude` fields report the actual grid point used (can differ slightly from the input due to grid resolution); these are what's stored, not the input coordinates, so the record shows precisely what point the forecast was for.

### Hike Start Forecast Sheet Schema

> *Historical — this was the Sheets column layout. It is now the `hike_start_forecast` table; `init/schema.sql` is authoritative.*

Separate sheet in the same Google Sheets workbook as Environmental Data. Self-provisioning — the Apps Script creates the sheet with this header row on first use if it doesn't already exist, so no manual Sheets setup step is required.

| Column | Source | Notes |
|---|---|---|
| `timestamp` | Triggering observation's `ts` | ISO 8601 UTC — join key for `action=export` date-range filtering, same as the other sheets |
| `date_az` | Derived from `timestamp` | Column header name is legacy (pre-CARD-0097) — value is the hike's own local `YYYY-MM-DD` (via Open-Meteo `timezone=auto`), not necessarily Arizona's. The dedup key ("already captured today, at this location?"). Header text itself wasn't renamed since the sheet already existed when CARD-0097 shipped; matching is positional, not by header name. |
| `lat` | Open-Meteo response | The actual grid point used, not the input coordinate |
| `lon` | Open-Meteo response | Same as `lat` |
| `temp_f` | Open-Meteo `hourly.temperature_2m` | °F, nearest hour to the triggering observation |
| `precip_pct` | Open-Meteo `hourly.precipitation_probability` | % chance |
| `wind_mph` | Open-Meteo `hourly.wind_speed_10m` | mph |
| `humidity_pct` | Open-Meteo `hourly.relative_humidity_2m` | % RH |
| `uv_index` | Open-Meteo `hourly.uv_index` | UVI |
| `provider` | Constant | `open-meteo` — future-proofing if the provider ever changes |

### Consumption

`components/hike-izer/fetch_hike_data.py` reads this sheet the same way it reads Environmental Data, Hiking Observations, and GPS Track — via the generic `action=export` endpoint, filtered to the requested day's window — and includes it in its output JSON as `hike_start_forecast`. See `.claude/skills/hike-izer/SKILL.md` for how the narrative-writing step reports it (or reports its absence, never fabricating a value).

---

## Weather Underground Integration

### Account

A free PWS (Personal Weather Station) account at wunderground.com. Upload is free for PWS owners. The Station ID and Station Key are stored in Node-RED environment variables (not in source control).

### Upload Format

Node-RED posts to the WU PWS upload URL:

```
https://weatherstation.wunderground.com/weatherstation/updateweatherstation.php
  ?ID=<STATION_ID>
  &PASSWORD=<STATION_KEY>
  &dateutc=<UTC_DATETIME>
  &tempf=<temp_f>
  &humidity=<humidity_pct>
  &baromin=<pressure_inhg>
  &windspeedmph=<wind_speed_mph>
  &winddir=<wind_dir_deg>
  &rainin=<rainin>
  &dailyrainin=<dailyrainin>
  &UV=<uv_index>
  &solarradiation=<irradiance_wm2>
  &action=updateraw
```

Note: WU expects pressure in inHg (`baromin`), not hPa. Node-RED converts: `inHg = hPa / 33.8639`.

### Upload Interval

Matches the ESP32 wake cycle — one upload per data message received (approximately every 5 minutes). WU accepts updates as fast as every 2.5 seconds; 5 minutes is well within acceptable frequency.

---

## MQTT Lightning Topic

The AS3935 lightning detector publishes strike events on a separate topic to allow independent handling (SmartThings alert, Sheets log entry) without mixing strike events into the regular data stream.

```
topic:   jctsh/components/weather-station/lightning
payload: { "component": "weather-station", "distance_km": 12, "energy": 847 }
```

Node-RED subscribes separately to this topic and:
- Fires a momentary ON to the `switch.weather_station_lightning` virtual switch in HA → SmartThings
- Appends a row to a separate `lightning_events` table (not yet created)

---

## Planned Environmental Sensor Family

| Device | Type | Location | GPS source | Status |
|---|---|---|---|---|
| Weather station | Fixed | Backyard, Tucson | Hardcoded constants | In planning |
| Porch sensor | Fixed | Front porch, Tucson | Hardcoded constants | Planned — next after weather station |
| Hiking monitor | Mobile | Variable | None — `lat`/`lon` sent as null; timestamp correlation with GaiaGPS track used instead | Phase 1 complete — parts ordered — ready for Phase 2 |
| Hiking health monitor | Mobile (wrist) | Variable | None — companion to hiking monitor | Planned — deferred; see note below |
| Air quality monitor | Mobile (carried on hike) | Variable | None — `lat`/`lon` sent as null; timestamp correlation with GaiaGPS track | Planned — deferred; see note below |
| Hiking observations | Phone-based | Variable | None — `lat`/`lon` sent as null; timestamp correlation with GaiaGPS track | Planned — deferred; see Hiking Observations Architecture section |
| Pleasure-Way sensor node | Mobile (RV) | 2018 Ram ProMaster / Pleasure-Way Lexor FL | Dedicated GPS module (NEO-6M or similar) on ESP32 | Planned — deferred |

### Hiking Monitor — GPS Approach

The hiking monitor carries no GPS hardware. During Phase 1 planning the originally proposed approach (real-time GPS injection via Pixel 10 Pro XL hotspot) was replaced with timestamp correlation: the device logs sensor readings with NTP-synced timestamps; GaiaGPS on the Pixel 10 Pro XL logs the GPS track independently; the two datasets are correlated by matching timestamps after the hike. `lat` and `lon` are sent as JSON `null` in all hiking monitor payloads. The phone hotspot is not needed during the hike.

See `components/hiking-monitor/` for full Phase 1 planning document.

### Hiking Health Monitor — LilyGO T-WATCH-S3 Plus

Identified during hiking monitor Phase 1 planning (May 2026) as a natural companion device for health sensing. Health metrics (heart rate, SpO2, skin temperature, step counting/activity) require reliable wrist skin contact, which conflicts with the hiking monitor's clip-on environmental sensor form factor. A dedicated wrist-worn device is the correct solution.

**Planned platform:** LilyGO T-WATCH-S3 Plus (~$60)
- ESP32-S3 — same ecosystem as all JCTsh components
- MAX30102 heart rate and SpO2 sensor — integrated, wrist-mounted
- MPU9250 9-axis IMU — accelerometer, gyroscope, magnetometer
- Wi-Fi and Bluetooth 5.0
- 600mAh LiPo with charging controller
- AMOLED display
- Programmable via Arduino IDE / ESP-IDF

**Planned integration:** Publishes health readings to `jctsh/components/hiking-health/data` on home WiFi reconnect using the standard environmental payload pattern. Health-specific fields (`heart_rate_bpm`, `spo2_pct`, `steps`, `skin_temp_f`) to be added to this document's schema when the project begins. Google Sheets archive receives both environmental and health data streams, joinable by timestamp.

**Status:** Identified and deferred May 2026. Plan as a separate JCTsh component project using the standard planning pattern when ready. No parts ordered.

### Air Quality Monitor — Standalone Hiking Companion

Identified during hiking monitor Phase 1 planning (May 2026) as a natural companion device for particulate matter and VOC/NOx sensing. Air quality sensing was explicitly excluded from the hiking monitor to avoid enclosure size increase, battery life reduction, and airflow port complexity. A separate device carried on-pack or clipped to a strap is the correct solution.

**Recommended platform:** ESP32 (on hand) + Sensirion SEN55
- PM1.0, PM2.5, PM4.0, PM10, VOC index, NOx index — all in one I2C module (43×43×23mm)
- Native ESPHome `sen5x` platform support
- Same onboard flash logging and WiFi replay pattern as the hiking monitor
- Battery sized for higher draw — 2000–3000mAh LiPo or 18650 from inventory
- Duty-cycle the SEN55 fan via GPIO transistor to reduce average draw

**Status:** Identified and deferred May 2026. Build the hiking monitor first. Plan as a separate JCTsh component project when ready. No parts ordered.

### Pleasure-Way Sensor Node

A NEO-6M GPS module on the ESP32 provides coordinates directly. The vehicle's Firefly control network is a separate subsystem (see planned RV component) — the environmental sensor node is independent of Firefly.

### Porch Sensor

The front porch sensor is the next planned environmental component after the weather station. It will use the same ESPHome + MQTT + Node-RED pattern as the weather station with a reduced sensor set (BME280 only — temp, humidity, pressure). It will publish on `jctsh/components/porch-sensor/data` with hardcoded Tucson front-porch coordinates. Node-RED wildcard subscription catches it automatically with no handler changes.

---

## Document Update Policy

Update this document when:
- A new environmental sensor is added to the family (update the planned device table)
- The payload schema is extended (add new fields to the field reference)
- The database schema is extended (a new column needs an `ALTER TABLE` against the live database plus a matching `init/schema.sql` edit)
- The Node-RED handler logic changes materially
- A new external data destination is added
- The hiking observations category taxonomy is extended

Do not update this document for component-specific implementation details — those belong in `components/<name>/README.md`.

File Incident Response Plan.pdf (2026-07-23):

## Incident Response Plan

JCT / Robin household — digital identity incident checklist. Keep a printed copy accessible offline (safe). Work through in order.

1. From another device, use a hardware security key to sign into Google, change the password, and revoke all active sessions immediately.
2. Call carrier to lock/freeze the SIM before anything else.
3. Call banks/brokerages/credit union using the number on the card/statement — never a number that contacted you.
4. File a report at identitytheft.gov (FTC).
5. File a police report and get the report number.
6. Document everything as you go: timestamps, amounts, reference numbers, names of who you spoke to.

Source: digital-identity-protection-checklist.md, Phase 4 — JCTsh repo, generated 2026-07-22.

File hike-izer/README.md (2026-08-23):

# hike-izer/ — Generated Output Staging

This directory holds **generated output only** — not source code. The
`hike-izer` skill (`.claude/skills/hike-izer/SKILL.md`) writes here when
building a hike summary; the actual pipeline code lives separately in
`components/hike-izer/`. Kept apart deliberately: code stays under
`components/hike-izer/`, results land here.

## What's in `summaries/`

For each hike, keyed by start date:
- `<start-date>_hike-summary.html` — the rendered summary page. Tracked in git as a historical record.
- `<start-date>_hike-summary.meta.json` — metadata alongside it. Also tracked.
- `<start-date>_photos/` — processed photos for that hike. **Gitignored** (`hike-izer/summaries/*_photos/`) — bulky and regenerable, not worth tracking.

## How it's used

Per the skill's own documented flow:
1. Fetch and analyze hike data (helper scripts in `components/hike-izer/`).
2. Build the HTML summary, meta.json, and photos here, under `summaries/`.
3. Publish by `scp`-ing the HTML, meta.json, and photos folder up to the M8 (`~/hike-izer-web-app/srv/`) — that's what actually serves the public hike pages, not this directory.

This directory is a local staging area, not a deployed artifact — nothing reads from it directly except the publish step.

## Related

- `components/hike-izer/` — the actual pipeline source and its own README/CLAUDE.md.
- `.claude/skills/hike-izer/SKILL.md` — the full generation/publish workflow this directory is a byproduct of.
- `components/hike-izer-web/`, `components/hike-izer-orchestrator/` — the M8-hosted app this staging output gets published to.

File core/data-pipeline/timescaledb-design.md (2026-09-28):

# Design: Phase 1 (Environmental Data + GPS Track) -- TimescaleDB migration

**Tracking card:** CARD-0349. **Depends on:** `timescaledb-migration-plan.md` (Planning). This document
resolves that plan's "open questions for Design" and is specific enough for Build to execute against.
Scoped to Phase 1 only (Environmental Data + GPS Track) -- Phase 2 (the other three tables) gets its
own Design pass once Phase 1 is live and proven, per this project's own iterative/incremental
discipline (don't design what isn't being built next).

---

## 1. Where it runs

New Docker Compose project on the M8: `~/data-pipeline-app/`, matching the existing
`~/hike-izer-web-app/` naming convention. Two services:

```yaml
# ~/data-pipeline-app/docker-compose.yml
services:
  timescaledb:
    image: timescale/timescaledb:latest-pg16
    restart: unless-stopped
    environment:
      POSTGRES_DB: jctsh
      POSTGRES_USER: jctsh
      POSTGRES_PASSWORD_FILE: /run/secrets/pg_password   # or an env file, matching credentials.local.md's existing pattern
    volumes:
      - ./pgdata:/var/lib/postgresql/data
      - ./init:/docker-entrypoint-initdb.d:ro   # schema.sql runs once, on first container start
    # Not published to the host/LAN -- only the gateway service (below) needs to reach it,
    # over this compose project's own default Docker network, same pattern hike-izer-web-app
    # uses between `web`/`orchestrator`.

  data-pipeline-api:
    build: ./api
    restart: unless-stopped
    depends_on: [timescaledb]
    environment:
      DB_HOST: timescaledb
      DB_NAME: jctsh
      DB_USER: jctsh
      DB_PASSWORD_FILE: /run/secrets/pg_password
      API_KEY: ${API_KEY}          # same shared-secret pattern as today's Apps Script
    ports:
      - "127.0.0.1:8091:8080"      # local-only, matching hike-izer-web's own 127.0.0.1:8090 debug-port pattern
```

**Exposure:** reuse the Cloudflare Tunnel + Caddy already running for `hike-izer-web-app` rather than
provisioning a second tunnel/domain for a personal project with one public-facing host. Add one more
route to that project's existing Caddyfile (`data.jctnet.com` or a path under the existing domain --
Joseph's call in Build, matching whichever is less disruptive to GPSLogger's/Tasker's existing
saved-URL configs) pointing at `data-pipeline-api:8080` over the two compose projects' shared network
(same mechanism `hike-izer-web`'s own `orchestrator` service already uses to be reachable via Caddy's
`/webhook/*` route -- Docker Compose supports one container joining a second project's network by
name).

## 2. Schema (finalized from the Planning doc's sketch)

```sql
-- ~/data-pipeline-app/init/schema.sql -- runs once, automatically, on first container start.

CREATE EXTENSION IF NOT EXISTS timescaledb;

CREATE TABLE environmental_data (
  ts              timestamptz NOT NULL,
  source          text        NOT NULL,
  lat             double precision,
  lon             double precision,
  temp_f          double precision,
  humidity_pct    double precision,
  pressure_hpa    double precision,
  dew_point_f     double precision,
  heat_index_f    double precision,
  uv_index        double precision,
  irradiance_wm2  double precision,
  wind_speed_mph  double precision,
  wind_dir_deg    double precision,
  rain_tips       integer,
  rainin          double precision,
  dailyrainin     double precision,
  battery_v       double precision,
  rssi_dbm        integer,
  pm1_ug_m3       double precision,
  pm25_ug_m3      double precision,
  pm4_ug_m3       double precision,
  pm10_ug_m3      double precision,
  voc_index       double precision,
  nox_index       double precision,
  illuminance_lx  double precision,
  solar_v         double precision,
  PRIMARY KEY (ts, source)
);
SELECT create_hypertable('environmental_data', 'ts');
-- Added beyond the Planning sketch: an index on source alone, for queries scoped to one
-- sensor across a wide date range (e.g. "all hiking-monitor readings this month") that
-- don't want to scan every source's rows in a chunk.
CREATE INDEX idx_environmental_data_source ON environmental_data (source, ts DESC);

-- Ingest guards (CARD-0215's physical range checks), enforced by the database itself now,
-- not application code that has to remember to call them:
ALTER TABLE environmental_data ADD CONSTRAINT chk_temp_f CHECK (temp_f IS NULL OR temp_f BETWEEN -20 AND 130);
ALTER TABLE environmental_data ADD CONSTRAINT chk_humidity CHECK (humidity_pct IS NULL OR humidity_pct BETWEEN 0 AND 100);
ALTER TABLE environmental_data ADD CONSTRAINT chk_pressure CHECK (pressure_hpa IS NULL OR pressure_hpa BETWEEN 800 AND 1100);
ALTER TABLE environmental_data ADD CONSTRAINT chk_uv CHECK (uv_index IS NULL OR uv_index BETWEEN 0 AND 20);

CREATE TABLE gps_track (
  ts          timestamptz PRIMARY KEY,
  lat         double precision NOT NULL,
  lon         double precision NOT NULL,
  accuracy_m  double precision,
  altitude_m  double precision,
  bearing_deg double precision
);
SELECT create_hypertable('gps_track', 'ts');
```

**Why `PRIMARY KEY` alone replaces CARD-0215/CARD-0243's manual dedup scans:** a duplicate `INSERT`
now fails the constraint instead of needing a full-column read-and-compare first; the gateway catches
that specific error and returns the same `{"status": "duplicate"}` shape Node-RED/GPSLogger/Tasker
already expect, so their own retry-tolerant behavior needs no change.

## 3. API (replaces `environmental-data.gs` entirely)

Explicit per-purpose routes instead of one `doPost` keyed on a hidden `component` string -- the one
real redesign choice here, per Joseph's decision to redesign rather than preserve the old shape.
GPS ingest stays a `GET` with query-string parameters: GPSLogger's own "custom URL" logging feature
only supports templated `GET` URLs, a real device/app constraint, not a design choice.

| Method | Path | Replaces | Caller |
|---|---|---|---|
| `POST /environmental-data?key=` | `doPost` (default branch) | Node-RED | Body: today's same JSON payload shape (`component`, `ts`, `lat`, `lon`, sensor fields) -- kept as-is, only the URL and routing change |
| `GET /gps?key=&lat=&lon=&acc=&alt=&direction=&ts=` | `?action=gps` | GPSLogger (phone) | Same query-string shape as today, so the phone's saved custom-URL template only needs its base URL changed |
| `GET /export?key=&table=environmental_data\|gps_track&start=&end=` | `?action=export` | `fetch_hike_data.py` (rewritten in Build) | `table` names an actual table, not a spreadsheet tab; returns a native JSON array, not Sheets' string-typed cell values |
| `GET /lookup-gps?key=&ts=` | `?action=lookup` | Node-RED's GPS correlation | Server does the nearest-neighbor SQL query (section 4) instead of Node-RED throttling calls to protect a spreadsheet |
| `GET /health?key=` | `?action=health` | `sheet_health.py` (rewritten in Build) | A real `SELECT 1` against the DB -- a connection failure or query timeout is the real, meaningful signal now, not "did opening a spreadsheet document hang" |
| `GET /version?key=` | `?action=version` | Manual deploy verification | A `VERSION` constant in the gateway's own source, same fingerprint-on-deploy convention as `SCRIPT_VERSION` |

**Handler shape matches `hike-izer-orchestrator/app.py`'s existing convention** (investigate existing
patterns first, don't invent a new house style for one more Python HTTP service on the same host):
stdlib `http.server.BaseHTTPRequestHandler` / `ThreadingHTTPServer`, a shared `_authorized(parts)`
check against `?key=`, and a `_respond(status, dict)` helper returning JSON -- not a new framework
dependency (Flask/FastAPI) for a single-purpose internal service this small.

**New Python dependency, unavoidable:** `psycopg2-binary`, for Postgres connectivity -- the one real
addition to this host's existing Python stack (`anthropic`/`paho-mqtt` are already pip dependencies
for the sibling `hike-izer-orchestrator` service, so one more well-known, widely-used library matches
the existing bar, not a new category of risk).

## 4. GPS correlation

Replaces both `?action=lookup` (Node-RED's per-reading call) and the derived-field back-fill:

```sql
SELECT lat, lon, accuracy_m
FROM gps_track
ORDER BY abs(extract(epoch from (ts - %(target_ts)s)))
LIMIT 1;
```

The hypertable's own time-partitioned index keeps this fast without the throttling Node-RED currently
needs (CARD-0279) to protect a spreadsheet from bursty replay traffic -- a real Postgres query under
concurrent load doesn't have Apps Script's per-call ceiling. Node-RED's existing throttle node can
likely be removed in Build once this is confirmed live; not assumed here.

## 5. Migration / backfill script

A one-time Python script (`core/data-pipeline/migrate_to_timescale.py`, run by hand during Build, not
part of the deployed gateway):

1. Calls the **current, still-live** `?action=export&full=1` for `Environmental Data` and `GPS Track`.
2. Transforms each row: Sheets' timestamp strings -> `timestamptz`, blank cells -> `NULL`.
3. Bulk-loads via `psycopg2`'s `execute_values` (or `COPY FROM STDIN` if row count makes that
   meaningfully faster -- decide in Build against the real ~33k-row count at migration time).
4. Verification step, mandatory before cutover (Note on Build, `JCTsh-Operating-System.md`: live
   verification beats inferred confidence): row counts match source; a real recent hike's
   `fetch_hike_data.py` output (rewritten against the new `/export`) reproduces the same
   stats/coverage numbers as its current Sheets-backed output for the same date range -- same
   before/after comparison pattern CARD-0311/CARD-0348 already used successfully.

## 6. Cutover sequence (one producer at a time, per the Plan's own decision)

1. Deploy `timescaledb` + `data-pipeline-api` on the M8; run the migration script; verify (section 5).
   No live traffic yet -- old spreadsheet and Apps Script keep running unchanged.
2. Point Node-RED's `environmental-data.flow.json` at the new `/environmental-data` and `/lookup-gps`
   routes. Verify a real sensor's next reading lands correctly (check via `/export` or a direct
   `psql` query), then verify the old Sheet has stopped receiving new rows from this source.
3. Point GPSLogger's custom-URL template at `/gps` on the new host. Verify on the next real hike
   (or a manual test fix) before relying on it for a real hike.
4. Point `fetch_hike_data.py` (both the interactive Skill's manual flow and
   `hike-izer-orchestrator`'s `generate()`) at the new `/export`. Verify against a real hike, same
   before/after comparison as step 1's migration check.
5. Point `sheet_health.py`/`run_daily_refresh_and_log()`'s pre-flight check at `/health`.
6. Once all of the above are live and stable for a real stretch of use (Joseph's own call on how
   long is enough -- not fixed here), retire the old spreadsheet and Apps Script deployment per the
   Plan's "retire once verified" decision. Not deleted immediately on the day everything's pointed at
   the new system.

## 7. Backup

The M8 has no existing general backup story to extend cleanly (photo-server's own backup drives are
specific to Immich's asset library, not a host-wide pattern). For Phase 1: a `pg_dump` to a local
file on a schedule, via a systemd timer matching the existing `hike-izer-daily-refresh.timer`
pattern already proven on this host -- daily, retaining some number of recent dumps (exact retention
a Build detail, not fixed here). **Explicitly an accepted limitation for Phase 1, not a gap silently
left unaddressed:** this covers "the container/data directory got corrupted," not "the M8 itself is
lost" -- true off-host backup (an equivalent to photo-server's own external-drive mirrors) is real
future work, not blocking Phase 1's own goals (this migration's whole point is fixing a
document-level Google-side failure mode, which a local dump already fully addresses).

## 8. `Correlation Debug`

Dropped, not carried forward as a stored table. Its diagnostic value (how closely a reading matched
a GPS fix) is fully covered by the gateway's own container logs (`docker logs data-pipeline-api`) --
one more log line per correlation, same visibility, no extra table to maintain.

## 9. Related

`timescaledb-migration-plan.md` (Planning, the document this resolves), CARD-0349 (tracking card),
`components/hike-izer-orchestrator/app.py` (the HTTP-handler convention this matches),
`core/data-pipeline/environmental-data.gs`/`environmental-data.flow.json` (what's being replaced).

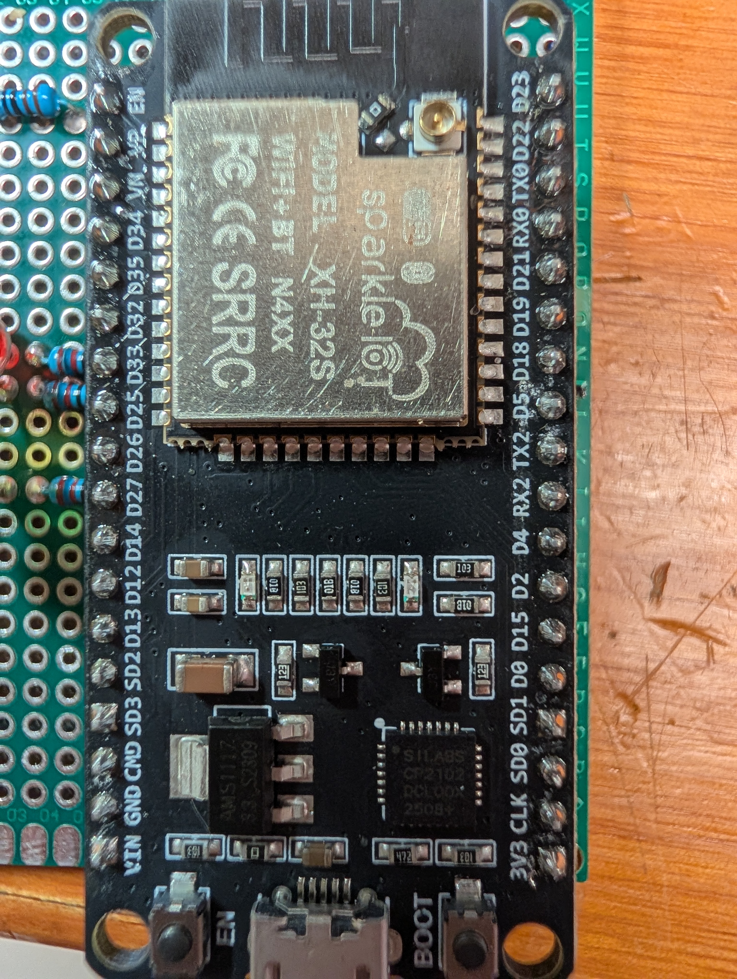
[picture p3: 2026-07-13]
components/salt-sensor/sparkleiot-xh-32s-pinout-photo.jpg

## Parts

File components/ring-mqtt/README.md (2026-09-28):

# ring-mqtt — Ring Doorbell/Camera MQTT + RTSP Gateway

Runs on the M8 (`hosts/m8/`). Bridges Ring devices to Home Assistant via MQTT discovery
and provides an RTSP gateway for live view (`camera.play_stream` / Generic Camera in HA,
CARD-0146).

**Status:** Production.

Pinned to an explicit version (`5.9.3`, CARD-0344) rather than `:latest`, matching this
repo's standing pin-don't-float convention (CARD-0352 did the same for cloudflared) —
now covered by `hosts/m8/container-update-check.py`'s `SERVICES` list like every other
pinned M8 container.

## Deploy

```bash
scp components/ring-mqtt/docker-compose.yml jct@m8.local:/home/jct/ring-mqtt/docker-compose.yml
ssh jct@m8.local "cd /home/jct/ring-mqtt && docker compose up -d"
```

`./config` (device pairing state, tokens) and MQTT credentials are host-local, not
repo-tracked.

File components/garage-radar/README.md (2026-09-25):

# Garage Radar

24GHz mmWave presence sensor for the garage workbench — detects still presence that
PIR-based sensors cannot, feeding into the garage presence automation to prevent the
door closing on someone sitting motionless at the workbench.

**Status:** Production — mounted in garage, running in production (June 2026)
**Hardware:** ESP32 + HLK-LD2412 mmWave radar

---

## What It Solves

PIR sensors detect heat movement — they miss someone sitting still. Arizona summer heat
also causes PIR sensors to stick `on`, making them unreliable as a primary presence
signal. The LD2412 mmWave radar detects both moving and still targets regardless of
ambient temperature, making it the primary input to the garage presence timer and the
safety interlock that prevents the auto-close routine from closing the door with someone
inside.

---

## Hardware

| Component | Details |
|---|---|
| Radar sensor | HLK-LD2412, 24GHz mmWave, UART interface |
| Microcontroller | ESP32 DevKitC-32, 38-pin, CP2102 USB-C |
| Green LED | GPIO33, 330Ω — presence detected |
| Yellow LED | GPIO32, 330Ω — garage lights on (mirrors vswitch) |
| Power | USB-C from garage outlet |
| Firmware | ESPHome ≥ 2025.8.0 (first version with native `ld2412` support) |

See [wiring.md](wiring.md) for full wiring checklist and
[ESP32-project-pins.md](ESP32-project-pins.md) for the complete pin table.

---

## Architecture

```
HLK-LD2412 radar
      │  UART (GPIO16 RX2 / GPIO17 TX2)
      ▼
ESP32 / ESPHome
      │  MQTT: jctsh/components/garage-radar/...
      ▼
Mosquitto broker (Raspberry Pi)
      │
      ├──► Home Assistant
      │      binary_sensor.garage_radar_presence
      │      ├── Garage Presence - Restart timer on activity
      │      ├── Garage Presence - Radar keepalive (every 5 min while present)
      │      └── timer.garage_presence_timer
      │               │ on expire
      │               ▼
      │      switch.garage_presence_vswitch ──► SmartThings ──► lights off / door close
      │
      └──► Log dashboard
```

---

## Quick Start

1. Copy `secrets.yaml.template` → `secrets.yaml` and fill in credentials from
   `credentials.local.md`
2. See [flashing.md](flashing.md) for first flash — note the Windows path requirement
3. See [integration.md](integration.md) for HA automation setup
4. See [end-to-end-test.md](end-to-end-test.md) for full system validation

---

## Configuration

| Setting | Where | Notes |
|---|---|---|
| WiFi / MQTT credentials | `secrets.yaml` | Template: `secrets.yaml.template` |
| Presence timer duration | `input_number.garage_timer_duration` | Set in HA Helpers — 15 min as of 2026-09-25 (helper default 20) |

---

## How It Works

### Presence Detection

The LD2412 reports `has_target` (true when any target — still or moving — is in range).
ESPHome applies a `delayed_off: 30s` filter so momentary detection gaps don't flicker
the state. This drives `binary_sensor.garage_radar_presence` in HA.

### LEDs

The **green LED** mirrors the presence state using a 30-second manual holdoff driven by
`detection_distance` rather than `id(presence).state` — necessary because nested ld2412
binary sensors return unreliable state values in ESPHome 2026.x.

The **yellow LED** mirrors `switch.garage_presence_vswitch` via MQTT subscription to
`jctsh/components/garage-presence-vswitch/state`. On = garage lights on.

### HA Automations

| Automation | Trigger | Action |
|---|---|---|
| Restart timer on activity | `garage_radar_presence` off→on | Start timer (`input_number.garage_timer_duration`, 15 min as of 2026-09-25); turn on vswitch |
| Radar keepalive | Every 5 min while presence on | Restart timer; confirm vswitch on |
| Timer expired | `timer.garage_presence_timer` finished | Turn off vswitch → lights off |

The keepalive prevents timer expiry during extended still presence — the `off→on`
trigger won't re-fire if someone stays motionless for longer than the timer duration.

### Timeouts

| Timeout | Location | Purpose |
|---|---|---|
| 30 seconds | ESPHome `delayed_off` | Smooths momentary detection gaps |
| 5 minutes | HA keepalive | Resets timer during continuous still presence |
| 15 minutes | HA timer (`input_number.garage_timer_duration`, as of 2026-09-25) | Presence decision; turns off vswitch on expiry |

### Heartbeat

Every 30 minutes the device publishes to `.../log` (uptime, RSSI, presence state) and
`.../heartbeat` (JSON). The Node-RED watchdog alerts via push notification if silent for
more than 35 minutes.

---

## MQTT Topics

**Published** (prefix: `jctsh/components/garage-radar`):

| Topic suffix | Payload |
|---|---|
| `.../binary_sensor/presence/state` | `ON` / `OFF` — primary presence signal |
| `.../binary_sensor/moving_target/state` | `ON` / `OFF` |
| `.../binary_sensor/still_target/state` | `ON` / `OFF` |
| `.../sensor/detection_distance/state` | cm |
| `.../log` | JSON log messages |
| `.../heartbeat` | JSON heartbeat |

**Subscribed:** `jctsh/components/garage-presence-vswitch/state` — drives yellow LED.

---

## HA Entities

| Entity | Type | Purpose |
|---|---|---|
| `binary_sensor.garage_radar_presence` | Binary sensor | Primary presence signal |
| `sensor.garage_radar_detection_distance` | Sensor | Detection distance in cm |
| `input_number.garage_timer_duration` | Helper | Timer duration in minutes |
| `timer.garage_presence_timer` | Timer | Countdown timer |
| `switch.garage_presence_vswitch` | Switch | Controls lights via SmartThings |

---

## Known Behaviors and Limitations

- **Door false positive:** Closing the garage door sweeps through the radar cone,
  triggering a brief presence detection. Harmless — the presence timer (15 min as of 2026-09-25) absorbs it.
- **ESPHome 2026.x nested binary sensor:** `id(presence).state` returns unreliable
  values for binary sensors inside the `ld2412:` component. Green LED uses
  `detection_distance` + manual holdoff as a workaround.
- **HA distance display:** HA shows distance in imperial (inches) due to system unit
  settings — values from ESPHome are in cm. Presence detection is unaffected.
- **Antenna orientation:** The LD2412 antenna face is the blank side (no components).
  It must face the detection zone.

---

## Files

| File | Purpose |
|---|---|
| `garage-radar.yaml` | ESPHome firmware config |
| `secrets.yaml` | Credentials — gitignored, never commit |
| `secrets.yaml.template` | Credential template |
| `wiring.md` | Breadboard wiring checklist |
| `ESP32-project-pins.md` | Full 38-pin assignment table |
| `perfboard-layout.md` | Permanent soldered build layout |
| `flashing.md` | First flash and OTA procedure |
| `integration.md` | HA automation setup |
| `integration-notes.md` | HA integration investigation findings |
| `smartthings-integration.md` | SmartThings integration notes |
| `testing.md` | Sensor validation procedure |
| `end-to-end-test.md` | Full system validation test suite |
| `CLAUDE.md` | Claude Code context — constraints and gotchas |
| `jctsh-garage-radar-claude-code-instructions.md` | Full build instructions |

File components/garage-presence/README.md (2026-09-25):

# Garage Presence

HA-only component that tracks presence in the garage using a countdown timer, and
exposes the result to SmartThings to drive lights-off and door-close routines.

**Status:** Production
**Hardware:** None — Home Assistant automations only

---

## What It Solves

PIR and camera motion sensors are unreliable for extended garage presence — they can't
detect someone sitting still at a workbench, and Arizona summer heat causes PIR sensors
to stick `on`. A timer-based approach solves both problems: any garage activity resets a
countdown, and when the countdown expires without new activity, presence is declared over.
The presence signal is decoupled from what it triggers, so the garage door and lights are
controlled by SmartThings independently of this component.

---

## Architecture

```
SmartThings sensors (motion, door, camera)
  binary_sensor.garage_motion_motion
  binary_sensor.back_door_door
  binary_sensor.garage_cam_motion
  binary_sensor.garage_radar_presence  ← primary signal (garage-radar component)
          │
          ▼
  Home Assistant automations
  ├── Restart timer on activity
  ├── Radar keepalive (every 5 min while radar is on)
  ├── Sync timer to vswitch (HA restart recovery)
  └── Timer expired
          │
          ▼
  timer.garage_presence_timer (countdown)
          │ on expire
          ▼
  switch.garage_presence_vswitch
          │
          ▼
  SmartThings
  ├── Lights off
  └── Close garage door (automatic-garage-door-opener-closer component)
```

---

## HA Helpers

Both created via HA UI: Settings → Devices & Services → Helpers.

| Helper | Entity ID | Purpose |
|---|---|---|
| Garage Presence Timer | `timer.garage_presence_timer` | Countdown timer |
| Garage Timer Duration | `input_number.garage_timer_duration` | Duration in minutes (default 20) |

---

## How It Works

Radar presence restarts the countdown timer. The legacy motion, door, camera and acceleration
sensors still trigger the same automation, but a template condition blocks them unless the radar
is `unavailable`/`unknown` — they are a fallback, not peers. The timer duration is read from
`input_number.garage_timer_duration` at the moment each trigger fires. When the timer
expires without a new trigger, `switch.garage_presence_vswitch` is turned off, which
fires a SmartThings routine that turns off the garage lights and closes the door.

The **radar keepalive** automation fires every 5 minutes while
`binary_sensor.garage_radar_presence` is `on`, restarting the timer. This prevents
expiry during extended still presence at the workbench — the `off→on` trigger alone
would not re-fire if the radar stayed continuously on for longer than the timer duration.

### Adjusting the Timer Duration

Change `input_number.garage_timer_duration` in HA: Settings → Devices & Services →
Helpers. Takes effect on the next trigger. To affect a currently running timer: cancel
it first (Developer Tools → Actions → `timer.cancel`), then re-trigger a sensor.

### SmartThings Sensors

| Sensor | Entity ID | Notes |
|---|---|---|
| Garage motion | `binary_sensor.garage_motion_motion` | PIR — may stick `on` in Arizona summer heat |
| Back door | `binary_sensor.back_door_door` | SmartThings → HA sync can be slow |
| Garage camera | `binary_sensor.garage_cam_motion` | PIR — same heat caveat as motion sensor |
| Garage radar | `binary_sensor.garage_radar_presence` | Primary signal — mmWave, unaffected by heat |

---

## Files

| File | Purpose |
|---|---|
| `CLAUDE.md` | Full automation YAML, HA entity details, architecture decisions |

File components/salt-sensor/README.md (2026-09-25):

# Salt Sensor

ESP32-based ultrasonic salt level monitor for a residential water softener — measures
salt percentage and raises low/critical alerts through Home Assistant (alert switches
voice-exposed to Google Assistant).

**Status:** Production
**Hardware:** ESP32 + JSN-SR04T waterproof ultrasonic sensor + three status LEDs

---

## What It Solves

A water softener runs out of salt silently — there's no indicator until the water stops
being softened. This sensor measures the salt level every 12 hours and raises alerts
before the tank runs out, giving time to refill without service interruption.
Calibration is done in Home Assistant with no reflash required.

---

## Hardware

| Component | Details |
|---|---|
| Microcontroller | ESP32 Dev Module |
| Sensor | JSN-SR04T waterproof ultrasonic — mounts at top of salt tank facing down |
| Red LED | GPIO32, 220Ω — critical level |
| Yellow LED | GPIO33, 220Ω — low level |
| Green LED | GPIO27, 220Ω — good level |
| Power | 5V USB wall charger |

### Wiring

| Connection | Notes |
|---|---|
| JSN-SR04T VCC → ESP32 VIN (5V) | Sensor requires 5V |
| JSN-SR04T Trig → GPIO5 | |
| JSN-SR04T Echo → 1kΩ → GPIO18 → 2kΩ → GND | Voltage divider required — sensor outputs 5V, ESP32 GPIO is 3.3V only |
| LEDs → GPIO32/33/27 (red/yellow/green) via 220Ω → GND | |

See [ESP32-project-pins.md](ESP32-project-pins.md) for the full pin table.

---

## Architecture

```
JSN-SR04T ultrasonic sensor
      │  (GPIO5 trig / GPIO18 echo)
      ▼
ESP32 (ESPHome)
      │  MQTT: jctsh/sensors/salt-sensor/...
      ▼
Mosquitto broker (Raspberry Pi)
      │
      ├──► Node-RED
      │      ├── Reads calibration from HA input_number helpers
      │      ├── Calculates salt percentage
      │      ├── Applies alert thresholds
      │      ├── Controls HA-native alert switches → Google Assistant
      │      └── Publishes status back to ESP32 → drives LEDs
      │
      └──► Log dashboard
```

---

## Quick Start

1. Create `secrets.yaml` in this folder — see Configuration below
2. Copy `salt-sensor.yaml` and `secrets.yaml` to `C:\esphome\salt-sensor\` (compiling from
   the repo path breaks — see Known Behaviors and Limitations)
3. Flash via USB (first time): `cd C:\esphome\salt-sensor && esphome run salt-sensor.yaml`
4. All subsequent updates: same command, over OTA once the device is on the network
5. Import `salt-sensor.flow.json` into Node-RED (import `core.flow.json` first)
6. Make sure `HA_TOKEN` is set in `/home/pi/.node-red/environment` on the Pi (systemd-level, CARD-0280) —
   not as a tab-scoped Node-RED Environment Variable
7. Create HA helpers and virtual switches — see Configuration below

---

## Configuration

### Credentials (`secrets.yaml`)

Create `secrets.yaml` in this folder — gitignored, never commit:

```yaml
wifi_ssid: "JCTnet1"
wifi_password: "..."
ap_password: "..."

mqtt_broker: "pi1.local"
mqtt_username: "salt-sensor"
mqtt_password: "..."

ota_password: "..."
```

All values are in `credentials.local.md`.

### Calibration (HA Helpers)

Create via Settings → Helpers → + Create Helper → Number:

| Helper entity | Default | Meaning |
|---|---|---|
| `input_number.salt_full_distance_cm` | 20.4 | Sensor-to-salt distance when tank is 100% full |
| `input_number.salt_empty_distance_cm` | 43.0 | Sensor-to-salt distance when tank is 0% empty |

Changes take effect within 60 seconds — no reflash needed.

To calibrate: mount the sensor at the top of the tank facing down. Fill to normal maximum
and note the distance in the log dashboard. Measure from sensor face to tank floor for
the empty value.

### HA-Native Switches (CARD-0261, 2026-09-12 — replaced SmartThings-synced virtual switches)

Four HA-native Template Switch helpers (backed by hidden `input_boolean` helpers for
persistence), each exposed to Google Assistant via HA's own native integration except
`salt_test_mode` (deliberately HA-only — a diagnostic action, not something Robin needs;
see `JCTsh-Build-Standards.md` §6.5's exposure test).

| Entity | Purpose | Exposed to Google Home? |
|---|---|---|
| `switch.salt_low_alert` | ON at warning level (< 33%) | Yes |
| `switch.salt_critical_alert` | ON at critical level (< 15%) | Yes |
| `switch.salt_test_mode` | Turn ON in HA to run test sequence | No — HA-only |
| `switch.salt_full_reset` | Turn ON after refilling to clear alerts | Yes |

### Live Salt Level (percent), added 2026-09-12

Two entities, since Google Assistant can't voice-expose an arbitrary numeric percent:

| Entity | Purpose |
|---|---|
| `input_number.salt_level_percent` | Written by Node-RED every reading — the real value, HA-only, not exposed |
| `sensor.softener_salt_level` | Template Sensor mirroring the above, `device_class: humidity` set deliberately (the closest Google-supported class) purely to make it voice-exposable — genuinely mislabeled, not a real humidity reading |

Google's Smart Home API only supports voice-query for a fixed list of sensor `device_class`es
(temperature, humidity, CO2, AQI, PM2.5, VOCs) — a generic percent has no supported class,
so this mislabel is the only way to get the live value voice-accessible at all. Ask
"what's the humidity of Softener Salt Level" to hear it.

**A single combined voice answer ("salt is 26%, no alert") is not achievable** — Google
Home's automation builder cannot insert a live sensor value into a spoken "Assistant says"
response (confirmed 2026-09-12, current platform limitation), and there's no supported way
to route a Google Home speaker's voice query into HA's own Assist pipeline (which *can* do
this natively via a templated custom-sentence response, but only through the HA Companion
app/voice hardware, not a Google Home speaker). Practical options: ask the humidity-labeled
sensor for the percent and a separate custom Google Home automation for alert status
(static text per branch), or use HA Assist for the full combined sentence via the phone app.

### Alert Thresholds

Set in the Node-RED `fn_threshold` function node:

```js
const WARNING_PERCENT  = 33.0;
const CRITICAL_PERCENT = 15.0;
```

---

## How It Works

### LED States

| LED state | Meaning |
|---|---|
| Green solid | Salt level good (> 33%) |
| Yellow blinking | Low (15–33%) — warning alert active |
| Red blinking | Critical (< 15%) — critical alert active |
| All three × 3 rapid flashes | Normal boot |
| All three blinking together | Sensor hardware error |

### Test Mode

Turn ON `switch.salt_test_mode` in Home Assistant. Node-RED simulates two readings:
- Step 1: ~27% — yellow LED, `switch.salt_low_alert` on
- Step 2: 0% — red LED, `switch.salt_critical_alert` on

Turn OFF the switch to clear all alerts and return to `ok`.

### Reset After Refilling

Turn ON `switch.salt_full_reset` (HA, or by voice via Google Home). Node-RED clears both alert switches, publishes
`ok` to the ESP32 (green LED goes solid), and turns the reset switch back OFF
automatically.

### OTA Updates

After first USB flash, use OTA — same command as the initial flash:
```
cd C:\esphome\salt-sensor
esphome run salt-sensor.yaml
```
ESPHome auto-detects the device on the network and offers OTA as an upload option.
Three rapid LED flashes at boot confirm a successful reboot.

---

## MQTT Topics

| Topic | Direction | Payload |
|---|---|---|
| `jctsh/sensors/salt-sensor/data` | ESP32 → Node-RED | `{"distance_cm":25.3}` retained |
| `jctsh/sensors/salt-sensor/status` | Node-RED → ESP32 | `ok` / `warning` / `critical` / `error` |
| `jctsh/sensors/salt-sensor/log` | both → log server | Standard JSON log message |
| `jctsh/sensors/salt-sensor/heartbeat` | ESP32 → watchdog | JSON heartbeat, every 30 min |

---

## Files

| File | Purpose |
|---|---|
| `salt-sensor.yaml` | ESPHome configuration — firmware source of truth |
| `secrets.yaml` | Credentials — gitignored, never commit |
| `salt-sensor.flow.json` | Node-RED flow |
| `ESP32-project-pins.md` | Full pin assignment table for the actual board in hand (SparkleIoT XH-32S), organized by printed label — corrected 2026-07-13, see file header |
| `sparkleiot-xh-32s-pinout-photo.jpg` | Reference photo of the actual board's silkscreen (SparkleIoT XH-32S) — ground truth for pin labels, since `ESP32-project-pins.md`'s position numbering doesn't match this board |
| `perfboard-layout.md` | Permanent build layout, bus planning, assembly sequence, pre-power checks, power-cycle verification (CARD-0049) |
| `CLAUDE.md` | Claude Code context — constraints and gotchas |
| `archive/salt-sensor-v3-arduino/` | Previous Arduino C++ firmware (reference only — do not use) |
| `archive/water_softener_salt_sensor_v2.ino` | Older version using direct SmartThings API (reference only — do not use) |

---

## Known Behaviors and Limitations

- **GPIO5 (ultrasonic Trig) is a strapping pin:** ESPHome logs a boot-time warning about
  it, but the device boots and runs correctly. The LEDs were moved off the GPIO2/GPIO15
  strapping pins onto GPIO32/33/27 for the perfboard build (CARD-0049).
- **Compile from `C:\esphome\salt-sensor\`, not the repo path:** spaces in
  `JCT Documents` break the ESP-IDF compiler. Copy `salt-sensor.yaml` and `secrets.yaml`
  there after any edit.

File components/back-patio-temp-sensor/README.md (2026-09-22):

# Back Patio Temp Sensor

ESP32 environmental sensor for the back patio — monitors temperature, pressure, and
light level. Duplicate of `front-porch-temp-sensor`'s design (CARD-0219), same hardware
and firmware pattern, different location.

**Status:** Build — perfboard assembled, bench-tested, and flashed (2026-09-21). WiFi, MQTT, and the BH1750 (light sensor) all confirmed live. Blocked on one part: the installed BME280 is a counterfeit BMP280 and is rejected by the firmware; genuine replacement ordered, swap is drop-in.
**Hardware:** ESP32 + BME280 + BH1750

---

## What It Solves

Same purpose as front-porch-temp-sensor: Tucson summers are dangerously hot, and this
sensor gives visibility into back patio conditions. Custom automation (e.g. door
open/close notifications) is deliberately undecided for now — see `integration.md`.

---

## Hardware

| Component | Details |
|---|---|
| Microcontroller | ESP32 DevKitC-32, 38-pin, CP2102, USB-C — silkscreened `NODEMCU` / `ESP-32S` / `V1.1` on the underside (same board batch as air-quality-monitor's). All 38 silkscreen labels verified against `ESP32-project-pins.md` on 2026-09-21 — **against a photo of a same-batch board, not this unit's own** (corrected 2026-09-22: `esp32-pins-photo.jpg` is byte-identical to `air-quality-monitor/esp32_pins.jpg` and originates from CARD-0012). Valid for the batch; this specific board's silkscreen has not been photographed. See that file's pin 18 note for the one conflict found, unused by this build. |
| Temp / humidity / pressure | BME280 (genuine GY-BME280), I2C at GPIO21/22 |
| Light | BH1750 (GY-302), I2C at GPIO21/22, ADDR pin → GND (address 0x23) |
| Power | USB-C from back patio outlet |
| Firmware | ESPHome |

Both sensors share the I2C bus. See [wiring.md](wiring.md) for full wiring checklist
and [ESP32-project-pins.md](ESP32-project-pins.md) for the complete pin table.

---

## Architecture

```
BME280 (temp/humidity/pressure)  +  BH1750 (light)
                  │  I2C
                  ▼
        ESP32 / ESPHome
                  │  MQTT: jctsh/components/back-patio-temp-sensor/...
                  ▼
        Mosquitto broker (Raspberry Pi)
                  │
          ┌───────┼───────────────┐
          ▼       ▼               ▼
   Home      Node-RED          Node-RED
   Assistant log router +      env data handler
   sensor    watchdog          (wildcard .../data)
   entities                         │
                               Google Sheets
                               (Environmental Data)
```

**Location:** Back patio, at the outlet mount point — point P2 in
[house-lot-coordinates.md](../../house-lot-coordinates.md) (32.4614183, -111.1184405).

---

## Quick Start

1. Copy `secrets.yaml.template` → `secrets.yaml` and fill in credentials from
   `credentials.local.md` (after `mqtt-account-setup.md`'s account is created)
2. See [flashing.md](flashing.md) for flash procedure
3. See [integration.md](integration.md) for HA entity setup
4. See [testing.md](testing.md) to verify end-to-end operation

---

## How It Works

Temperature, pressure, and illuminance are published to MQTT every 60 seconds.
HA auto-discovers all entities via MQTT discovery.

Every 5 minutes the device publishes a JSON payload to
`jctsh/components/back-patio-temp-sensor/data`. The Node-RED environmental data handler
(wildcard `jctsh/components/+/data`) routes this to Google Sheets via Apps Script —
no Node-RED changes needed.

Every 30 minutes the device publishes a heartbeat to
`jctsh/components/back-patio-temp-sensor/heartbeat`. The Node-RED watchdog monitors
this and sends a push notification if silent for more than 35 minutes.

No custom threshold/notification automation exists yet — deliberately deferred, see
`integration.md`.

---

## Files

| File | Purpose |
|---|---|
| `back-patio-temp-sensor.yaml` | ESPHome firmware config |
| `parts-list.md` | Consolidated bill of materials |
| `secrets.yaml` | Credentials — gitignored, never commit |
| `secrets.yaml.template` | Credential template |
| `wiring.md` | Perfboard wiring checklist |
| `ESP32-project-pins.md` | Full 38-pin assignment table |
| `ESP32pins.png` | Generic 38-pin ESP32 reference pinout — **top view**, the orientation every pin number in this component is stated in |
| `esp32-pins-photo.jpg` | Board silkscreen photo, **underside** (so left/right are mirrored against the table and reference above). **A same-batch board, not this unit's own** — byte-identical copy of `air-quality-monitor/esp32_pins.jpg`. |
| `perfboard-layout.md` | Perfboard build layout |
| `flashing.md` | Flash procedure |
| `integration.md` | HA entity setup; custom automation deferral notes |
| `bench-test-plan.md` | Pre-flash bench worksheet — continuity, isolation, and power-on smoke test, derived from `wiring.md` |
| `testing.md` | End-to-end test procedure (post-flash) |
| `mounting.md` | Physical mounting instructions |
| `mqtt-account-setup.md` | Dedicated Mosquitto account creation |
| `CLAUDE.md` | Claude Code context — constraints and gotchas |

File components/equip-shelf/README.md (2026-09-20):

# Equipment Shelf

Physical shelf housing the home's core networking and automation infrastructure hardware.

**Status:** Production
**Hardware:** No microcontroller, no firmware — a physical mounting/organization location plus 3D-printed cooling-fan brackets.

---

## What It Houses

| Item | Role |
|---|---|
| Raspberry Pi (`pi1`) | Runs Mosquitto, Node-RED, the Python log server, Home Assistant (Docker) — see root `CLAUDE.md` |
| M8 | Docker host for hike-izer-orchestrator, NetAlertX, Immich, photo-server, and other containerized apps |
| Samsung SmartThings hub | SmartThings integration bridge (see root `CLAUDE.md`'s SmartThings Integration section) |
| Garage door relay switch / opener hardware | See `components/automatic-garage-door-opener-closer/` |
| Router | Home network (JCTnet1) |
| Router power reset device | Remote power-cycle capability for the router |
| Cooling fan(s) | Active cooling for the shelf's equipment — see Cooling below |

This directory documents the shelf itself and its cooling hardware; each hosted device/service has its own component directory or root-level doc for its actual function.

---

## Cooling

Two fan-bracket designs live in this directory's STL files:

| File | Notes |
|---|---|
| `fan_bracket_ACInfinity_S7.stl` | Original bracket, for an AC Infinity S7 fan |
| `Fan bracket.stl` | Newer bracket design, added 2026-09-16 |

No further build documentation exists yet for these — added here as a real, if minimal, home for a component that previously had STL files in the repo with no README at all.

---

## Related

`automatic-garage-door-opener-closer` (the garage relay hardware hosted here), root `CLAUDE.md` (Pi/M8 infrastructure and services), `network/jctsh-network.md` (network topology).

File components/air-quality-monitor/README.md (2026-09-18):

# Air Quality Monitor

Portable clip-mounted sensor measuring PM1.0, PM2.5, PM4.0, PM10, VOC index,
and NOx index — carried on hikes alongside the hiking monitor to capture personal air
quality exposure on the trail.

**Status:** Bench phase complete (CARD-0291 audit found this line stale — see [air-quality-monitor-claude-code-instructions.md](air-quality-monitor-claude-code-instructions.md)'s "Bench Phase Complete" section for full step tracking). Perfboard-built and wired (SEN55/adapter, power-gate transistor, RGB LED, both dividers), validated on USB and battery power, running field-mode duty-cycle logging and home-mode WiFi replay, integrated with the log dashboard/watchdog/Sheets. Install phase (enclosure/carry-case) not yet started.

---

## What It Solves

Fixed AQI stations miles away don't capture actual trail exposure to wildfire smoke,
haboobs, trail dust (silica), and summer ozone in the Tucson area. This device provides
a timestamped personal exposure record for every hike, correlated to GPS track and
hiking monitor environmental data in Google Sheets for post-hike analysis. A single RGB
LED gives immediate field awareness of PM2.5 level without a display.

---

## Planning

Phase 1 (discovery and feature decisions) is complete. Sensor selection, power system,
carry/enclosure approach, firmware pattern (follows hiking monitor exactly — do not
re-derive), and JCTsh integration are all decided. SEN55, Adafruit #5964 adapter, and
JST GH cable are all received and confirmed on hand.

See [JCTsh-air-quality-monitor-phase1.md](JCTsh-air-quality-monitor-phase1.md) for the
full Phase 1 planning document.

Build begins after the hiking monitor is complete.

---

## Planned Hardware

| Component | Details |
|---|---|
| Microcontroller | ESP32 DevKitC-32 (on hand) |
| Air quality | Sensirion SEN55 (PM1.0/2.5/4.0/10, VOC, NOx) via Adafruit #5964 adapter |
| Field indicator | RGB LED — see [LED Status Guide](#led-status-guide) below |
| Battery | EEMB LiPo pouch 603449, 1100mAh (on hand) |
| Power module | TP4056 + boost combined module (on hand) |
| Enclosure | 3D-printed with air intake/exhaust ports for SEN55 fan |

---

## LED Status Guide

The single RGB LED (GPIO18/19/23) communicates device state through color and blink
pattern, not just a static PM2.5 color. On power-up it runs a fixed self-test sequence,
then hands off to an ongoing operational pattern:

| Phase | Behavior | Meaning |
|---|---|---|
| 1. Self-test | Two blinks each, in order: **Blue → Red → Yellow → Green** (300ms on/off) | Confirms all three color channels (and their combinations) drive correctly — a bad solder joint or dead channel shows up here as a missing color |
| 2. Waiting for data | **Green blinks** steadily, 400ms on/off, **no timeout** | SEN55 hasn't produced a valid PM2.5 reading yet. Deliberately unbounded — a "looks connected" wiring fault can silently produce zero valid readings for minutes (seen during Step 4 bench debugging), so a timeout here would let the device falsely claim "all is well" while actually broken. If this runs more than ~30s, suspect a physical connection issue (see `wiring.md`'s SEN55 wiring section — the SEN55 power-gate transistor was dropped in Step 6, so this is no longer a gate-circuit issue, just the direct GND/VIN/I2C wiring). |
| 3. Ready | **Solid green, 2 seconds**, then off | One-time confirmation: boot finished, first valid reading received, handing off to normal operation |
| 4. Threshold-color check | **Solid Yellow (3s), then solid Red (3s)** | Confirms the Yellow and Red threshold colors themselves display correctly, on every boot — not just Green, and without needing a real particulate source in range. Permanent, not a one-off test. |
| 5. Operational (ongoing) | Brief ~1s flash on every new reading (~every 10s): **Green** (<12 µg/m³, Good), **Yellow** (12–35, Moderate), **Red** (>35, Unhealthy) | Current air quality. Flashes rather than stays lit to save power on battery — same information, most of the continuous-LED power draw eliminated |

**Design note:** this color/blink vocabulary (self-test sequence, unbounded "still waiting" blink vs. bounded confirmation, brief operational flash) is generic enough to reuse for other status conditions if this device or a future one needs to communicate more than PM2.5 alone — e.g. low battery, WiFi/MQTT connection trouble. Not implemented yet; noted here as a pattern worth extending rather than re-deriving if that need comes up.

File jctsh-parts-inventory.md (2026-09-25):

# JCTsh Parts Inventory
**Author:** Joseph C Thomas (JCT)
**Purpose:** On-hand parts inventory for JCTsh smart home component projects. Update quantities after each project build.
**Version:** 2.39
**Version description:** 503450 1000mAh LiPo swap plan dropped 2026-09-25 — hiking-monitor and air-quality-monitor stay on the EEMB 603449; the 503450s are unassigned stock.
**Project:** JCTsh — Smart Home Automation
**Related files:** README.md, JCTsh-Component-Planning-Pattern.md

---

## Location Key

| Location | Description |
|---|---|
| Box Label | Plastic storage box with a label (like "Arduino") — houses Pi Zero W kit, other computing devices, and associated accessories |
| Bag N | Numbered zip-lock or parts bag; label bag with number to match this inventory |
| Shelf | Workshop shelf — larger or allocated items not yet deployed |
| Bench | Primary work surface / soldering station area |
| Music Response bin | Plastic storage bin labeled "Music Response" — houses discrete components and supplies for the music response project |
| Deployed | Installed in a live JCTsh component; not on hand |
| Soldering Tools | Container/kit labeled "Soldering Tools" — houses soldering iron tips, heat-set insert tooling, and related accessories |
| Bin [A-D][1-6] | Plastic bin storage box, organized as a grid — rows A-D, columns 1-6 (e.g., Bin A1) — added 2026-08-20 as select bags are consolidated out of individual numbered zip-lock bags |

---

## Enclosure Convention

Open standoff mount is the default first option for ESP32 and small PCB projects. No enclosure panels. The perfboard (or dev board) is mounted vertically using M3 brass male-female standoffs, which space the board away from the mounting surface for cable clearance and serve as the attachment points. This approach suits the workshop environment, is inexpensive, reusable across projects, and keeps components accessible.

An acrylic lid panel (cut to perfboard footprint, held by the same standoffs) may be added as a future enhancement if dust accumulation becomes an issue. A full enclosure box (e.g., project box) is reserved for components that require weather resistance or a finished appearance outside the workshop.

---

## Servers & Mini PCs

| Component | Description | Qty | Location | Notes |
|---|---|---|---|---|
| GMKtec NucBox M8 | AMD Ryzen 5 PRO 6650H (6C/12T, 4.5GHz), 16GB LPDDR5, Netac 512GB NVMe SSD, dual Realtek 2.5GbE, RZ616 Wi-Fi 6E, USB4, OCuLink. Model: M8-5-33S. Serial: MB261801199. Windows 11 Pro OEM (BIOS-embedded key: QXNC8-CBB7V-2FMDW-FVXX7-XD8GG). Purchased 2026-07 Amazon Prime Day. | 1 | Deployed | Deployed as photo-server. OS replaced with Ubuntu 26.04 LTS (Windows 11 no longer running). |

---

## Storage

| Component | Description | Qty | Location | Notes |
|---|---|---|---|---|
| Seagate Backup Plus 1TB | USB HDD, P/N 1KAAP1-501, bus-powered, ext4 | 1 | Deployed | Deployed as photo-server primary Immich library (`/mnt/photo-library`) |
| Seagate Momentus 640GB | In Insignia enclosure, P/N 9RN134-030, bus-powered, ext4 | 1 | Deployed | Deployed as photo-server local backup (`/mnt/photo-library-backup`) |
| Seagate 1TB | USB HDD, model `ST31000528AS`, serial `5VP1HJ2P`, requires external power (this is the drive previously listed as "Seagate Expansion 1TB, P/N 9SF2A4-500" — confirmed identity via `lsblk` 2026-07-10, not blank when connected, had a leftover vfat+ext3+swap partition layout, reformatted ext4) | 1 | Deployed | Deployed 2026-07-10 as photo-server's dedicated backup drive for Joseph's account (`/mnt/photo-library-backup-joseph`) — Momentus alone could no longer hold the full primary library. See `components/m8/backup.md`. |
| WD 750GB | USB HDD, P/N WD7500H1U-00, model WDC WD7500AAVS-00D7B0, serial WD-WCAU41533297 (confirmed via `lsblk` 2026-07-10) | 1 | Shelf | Spare — too small to replace either deployed drive. **Not blank** — has existing partitions (698.4G vfat + 117.7M ext3 + 117.7M swap, suggesting a prior Linux system/boot disk use). Do not format without first checking what's on it. Mistakenly connected to photo-server 2026-07-10 in place of the intended Seagate Expansion 1TB — the two spares look similar enough to grab the wrong one; check the P/N label before connecting either. |

---

## Microcontrollers

| Component | Description | Qty | Location | Notes |
|---|---|-----|---|---|
| ESP32 DevKitC-32 | hiBCTR 6-pack, 38-pin, CP2102 USB-C, WiFi+BT; supplemented with a second 6-pack (ESP-32D, CP2102, 38-pin, STA/AP/STA+AP, WiFi+BT dual-core, Type-C), ASIN B0DSZBH9N9. https://www.amazon.com/dp/B0DSZBH9N9 | 7 | Bag 1 | 1 used: garage radar. 1 used: front-porch-temp-sensor. 1 used: hiking-monitor. 6 received 2026-07-13 (second 6-pack, merged into this row). **1 discarded 2026-07-14 (CARD-0026)** — confirmed defective, bad flash chip communication (`esptool`: "Failed to communicate with the flash chip"), ruled out as a cable/port/bootloader-entry issue by successfully flashing a second spare board on the same setup; thrown away rather than returned to stock. Qty 8 → 7. 1 currently allocated: CARD-0026 sleep-current test rig (temporary, not a permanent deployment). 1 allocated: back-patio-temp-sensor (CARD-0219). |
| ESP32 (salt sensor) | Separate board, not from 6-pack | 1 | Deployed | Deployed on salt sensor project. |

---

## Single-Board Computers

| Component | Description | Qty | Location | Notes |
|---|---|---|---|---|
| Raspberry Pi 3B+ |  | 1 | Shelf | Allocated as home based server for MQTT, Node-RED, and other JCTsh software components. |
| Raspberry Pi 3B+ | Element14 | 1 | Shelf | Allocated to upcoming RV project. |
| Raspberry Pi Zero W | Vilros Basic Starter Kit, ASIN B0748MPQT4. BCM2835, single-core 1GHz, 512MB RAM, 802.11b/g/n WiFi, BT 4.1, CSI camera connector. Kit includes: board, 2.5A PSU w/ inline switch, black case (3 covers), mini-HDMI adapter, micro-USB OTG adapter, 40-pin header (unsoldered), heatsink, camera module adapter cable. No SD card. | 1 | Arduino box | No project assigned. Suitable for: sensor logging (MQTT/Python), Pi-hole, lightweight single-purpose Linux tasks. Not suitable for: OpenCV/camera processing, Node-RED as primary host. Header requires soldering before GPIO use. Included PSU reported unreliable — use a known-good 5V/2.5A supply if instability occurs. |

---

## Sensors

| Component | Description | Qty | Location | Notes |
|---|---|---|---|---|
| HLK-LD2412 | EC Buying, 24GHz mmWave radar, UART, ±75°, 9m range | 0 | Discarded | 1 used: garage radar project. Bag 18 confirmed empty and discarded during the 2026-08-20 bag-to-bin reorg. |
| BH1750 (GY-302) | hiBCTR 3-pack, illumination/light sensor, I2C. https://www.amazon.com/dp/B0FDLDG2TD | 5 | Bin C3 (was Bag 19) | 1 used: front-porch-temp-sensor. 1 allocated: back-patio-temp-sensor (CARD-0219). |
| BMP280 (sold as BME280) | Podazz 3-pack, counterfeit — pressure/temp only, no humidity, I2C, 5V. **Do not reorder — this listing is what shipped the counterfeits.** https://www.amazon.com/dp/B0DCFXRZ1F | 2 | Bin B3 (was Bag 2) | 3 returned 2026-05-26. 2 spares removed from front-porch-temp-sensor. |
| BME280 (GY-BME280) | 2PCS packs, genuine — temp/humidity/pressure, I2C/SPI, 5V breakout. **No purchase link on file** — the only sensor row still missing one (2026-09-21). | ? ⚠️ | **Bag 3 — NOT FOUND 2026-09-21** | 1 deployed: front-porch-temp-sensor (2026-05-26). 1 used: hiking-monitor. 2 spares. 1 allocated: back-patio-temp-sensor (CARD-0219). **⚠️ Bag 3 could not be located, 2026-09-21 (Joseph, looking for the part for CARD-0219) — quantity now genuinely unknown, not merely unreconciled.** He installed a counterfeit from Bin B3 instead, which the firmware caught, and has ordered replacements. Until Bag 3 turns up, treat on-hand genuine stock as **0**. The Update Log's own arithmetic gives **2** on hand (×4 received 2026-05-26, ×1 deployed to front-porch same day, ×1 used by hiking-monitor 2026-06-04), and this row's own "2 spares" agrees — but the Qty cell says 3, and `components/weather-station/jctsh-weather-station-planning.md`'s Phase 3 notes claim ×6. Four sources, three different numbers. Whichever is right, 1 of them is allocated to back-patio-temp-sensor. |
| BME280 (GY-BME280, 4-pack) | 4 PCS, 3.3V, temp/humidity/barometric pressure, I2C/SPI breakout. https://www.amazon.com/dp/B0F6L8G7G3 | 4 | Bin A6 | No project assigned. Genuineness not yet verified — the Podazz BMP280-as-BME280 counterfeits (see row above) passed as this same part name, so check the chip ID on first boot (ESPHome's `bme280_i2c` rejects a BMP280). Separate purchase from the Bag 3 row. |
| LTR390 UV Light Sensor | Adafruit #4831, STEMMA QT / Qwiic I2C, UV and ambient light, 3.3V/5V. https://www.amazon.com/dp/B0BPR31P59 | 1 | Bin B2 (was Bag 22) | 1 used: hiking-monitor. 1 spare. |
| SparkFun SEN-23715 | Sensirion **SEN55** (corrected 2026-07-09 — was mislabeled SEN54; part number SEN-23715 is the genuine SEN55 per SparkFun's own product listing), particle (PM1/2.5/4/10), VOC, NOx, humidity, temperature, I2C/UART. | 1 | Plastic Box | Allocated: air-quality-monitor project. Matches the air-quality-monitor plan's SEN55 requirement (NOx included) — no substitution occurred. **Caveat:** this correction trusts that the physical item on hand actually carries part number SEN-23715, which hasn't been checked against the item's own label/silkscreen — worth a quick physical glance next time the box is open. |
| Adafruit SEN54/SEN55 Adapter Breakout | STEMMA QT / Qwiic, I2C adapter breakout for Sensirion SEN54/SEN55. | 1 | Bag 25 | Allocated: air-quality-monitor project. |
| DS3231 RTC Module | HiLetgo 5pcs, high precision real time clock, I2C, 3.3V/5V, CR2032 battery backup. https://www.amazon.com/dp/B01N1LZSK3 | 5 | Bin A5 (was Bag 28) | 1 allocated: bedside-clock. |
| JSN-SR04T-V3.0 | 2pcs, waterproof ultrasonic distance measuring sensor transducer module, integrated. https://www.amazon.com/dp/B0CP5YQF43 | 2 | Bag 30 | No project assigned. |
| DS18B20 Waterproof Temperature Probe | BOJACK, 1M cable, stainless steel probe, digital 1-Wire. https://www.amazon.com/dp/B09NVFJYPS | 2 | Bag 37 | No project assigned. |
| Greekcreit Sensor Module Kit for Arduino | Kit of 37 modules including: active/passive buzzer, LED modules (common cathode red/green, two-color, RGB, colorful auto flash), knock/shock/tilt/magnet-ring/hall/analogy hall/magnetic spring sensors, photo resistor, push button, infrared TX/RX, rotate encoder, light break sensor, finger pulse sensor, obstacle avoidance, tracking, microphone, laser TX, relay, analog/digital/18b20 temperature, flame, voice, humidity, joystick PS2, touch sensor | — | Plastic Box | |

---

## Power Components

| Component | Description | Qty | Location | Notes |
|---|---|---|---|---|
| 18650 Battery Charger Module + Holder | AEDIKO 5-pack (charger + holder pairs), fast charge boost, PCB protection | 10 | Bag 4 | No project assigned. |
| EVE INR18650/33V Cell | 18650BatteryStore.com, standard Li-ion (INR/NMC chemistry, corrected 2026-09-09 — was mislabeled "3.3V", confirmed via manufacturer specs 3.6V nominal/4.2V peak, not LiFePO4; "33V" is a model-code suffix, not the actual voltage), 3200mAh, 10A, flat top. https://www.18650batterystore.com/products/eve-18650-33v | 5 | Bag 5 | No project assigned. Candidate cell for CARD-0256 (robust solar+swappable-battery pattern) — standard TP4056 charging applies, no LiFePO4-specific charger needed. |
| Mini Solar Panel | SUNYIMA, 5.5V 80mA, 2.36"×2.36", DIY photovoltaic | 10 | Bag 6 | No project assigned. |
| LI-ION Polymer Battery | EEMB, 3.7V 1100mAh 603449, JST connector. https://www.amazon.com/dp/B08VRYS8FT — confirm polarity before use. | 3 | Bag 7 | 1 in service: hiking-monitor. Hiking-monitor's original cell failed in the field (2026-07-03) and was replaced from this stock — physical recount confirmed 2 still remaining in Bag 7 afterward; trust this physical count over prior used/remaining math. |
| LiPo Battery 503035 | AKZYTUE, 3.7V 500mAh 503035, JST PH2.0mm 2-pin connector, PCM-protected. https://www.amazon.com/dp/B07S84SBV3 — confirm polarity before use. | 1 | Unknown | Allocated: shower-temp-sensor (CARD-0188, decided 2026-08-20). Never entered in this inventory until backfilled 2026-09-25; location not yet given. |
| LiPo Battery 503450 | 3.7V 1000mAh 503450, JST PH2.0mm 2-pin connector. https://www.amazon.com/dp/B0GHR5J34D — confirm polarity before use. | 2 | Not yet located | No project assigned. Bought 2026-09-25 as a possible replacement for the EEMB 1100mAh 603449 cells in hiking-monitor/air-quality-monitor; that swap was dropped the same day (these are 1000mAh, lower than the 1100mAh they'd replace, and a different package). |
| TP4056 Battery Charger Modules | USB TP4056, 3.7V–4.2V to 9V/5V, 2A, charge/discharge integrated step-up. https://www.amazon.com/dp/B098989NRZ | 5 | Bin A4 (was Bag 8) | 1 used: hiking-monitor. |
| DC Buck Converter 12V→5V 3A | 2pcs, 15W, USB-C output, compatible with Raspberry Pi 4. https://www.amazon.com/dp/B0CMZWN7WS | 2 | Bag 21 | No project assigned. |
| Power Supply Module 3.3V/5V | HiLetgo, dual output 3.3V and 5V, breadboard-compatible. | 5 | Music Response bin | No project assigned. |
| 9V Battery Clips I-Type DC Plug | HiLetgo, I-type DC barrel connector. | 10 | Music Response bin | No project assigned. |
| LiPo Fireproof Charging Bag | Silicone-coated fiberglass, for safe LiPo charging/storage per JCTsh-Build-Standards.md §2.14. | 1 | Bench | Required practice for all LiPo charging going forward — not project-specific. Received 2026-07-09. |

---
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

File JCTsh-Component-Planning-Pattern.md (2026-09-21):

# JCT Smart Home (JCTsh) Component Planning Pattern
**Author:** Joseph C Thomas (JCT)
**Purpose:** Defines the five-phase process for planning and building JCTsh smart home components, from discovery through execution.
**Version:** 2.5
**Version description:** Added "Cloning an Existing Component — Planning Shortcut" section (CARD-0219) — for a component that duplicates an already-built design, create its directory and write findings straight into real docs during Planning, rather than accumulating everything in the kanban card and migrating later.

---

## Core Principle

Preliminary thinking happens in Claude chat, informally — feasibility questions, initial ideas, whether to build something at all. This stage produces no planning documents. Once that thinking is done and there's a decision to build, move to Claude Code: create a card (per `JCTsh-Operating-System.md`) and work Phases 1–5 there, start to finish. Chat doesn't re-enter the process once the card exists — research, planning, design, and execution all happen in the same continuous Claude Code session (or a resumed one), not split across tools.

---

## Context Files — Phased Loading

Files are loaded when they become necessary, not all at once before anything begins. Loading files before they are needed adds friction without adding value. The tables below define what is needed at each phase and why.

### Phase 1 — Load before beginning Phase 1

Phase 1 is about feasibility and approach. Only two files are needed: the planning pattern itself (this document) and the environmental architecture doc. The environmental architecture doc is required early because it defines the payload schema and data pipeline that all environmental sensor components must conform to — these constraints shape the feasibility discussion from the start.

| File | Location | Purpose |
|---|---|---|
| `JCTsh-Component-Planning-Pattern.md` | repo root | This document — the planning process itself |
| `core/data-pipeline/JCTsh-Environmental-Data-Architecture.md` | core/data-pipeline/ | Standard environmental sensor payload schema, Google Sheets archive design, Node-RED wildcard handler pattern, Weather Underground integration, and the planned environmental sensor family. Shapes feasibility and approach from the start — all environmental sensor components must conform to decisions already made here. |
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

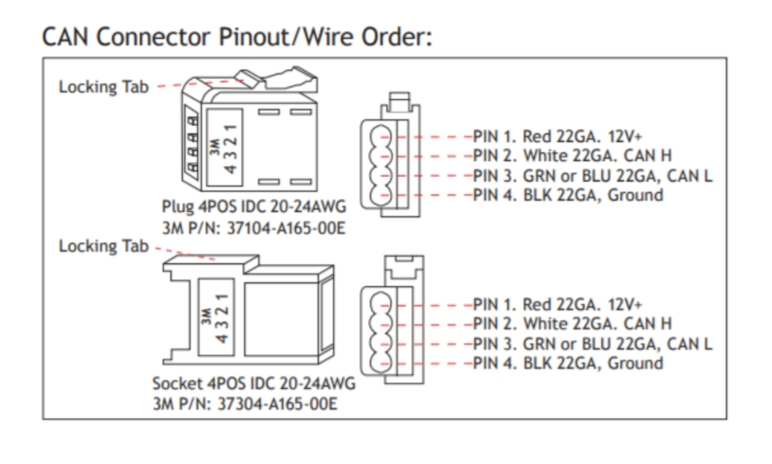
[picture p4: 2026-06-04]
components/p-w-firefly/CAN Connector Pin Out.png

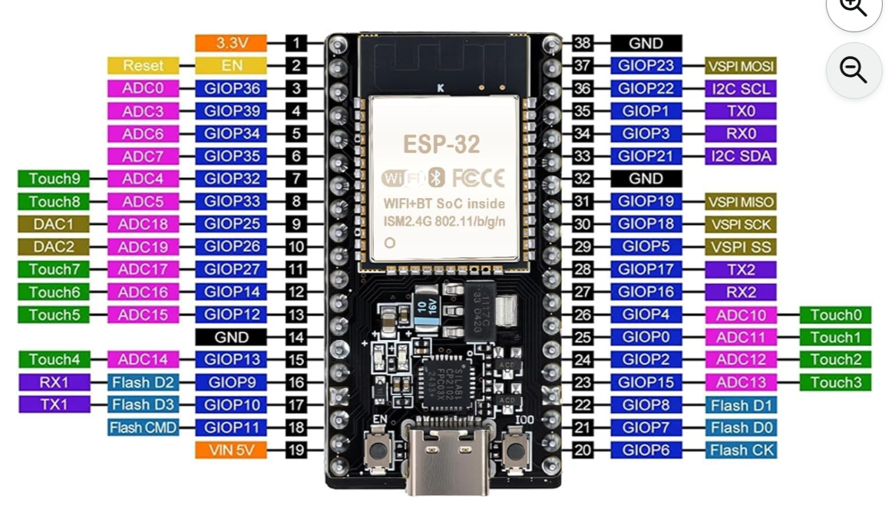
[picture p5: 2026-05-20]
components/back-patio-temp-sensor/ESP32pins.png

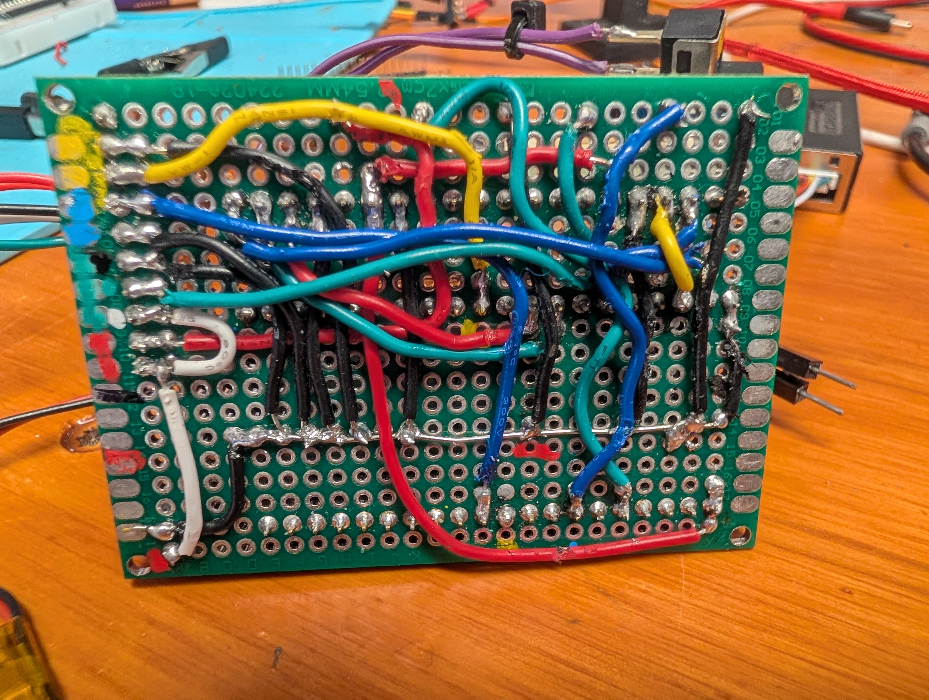
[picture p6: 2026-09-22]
components/air-quality-monitor/perfboard_4.jpg

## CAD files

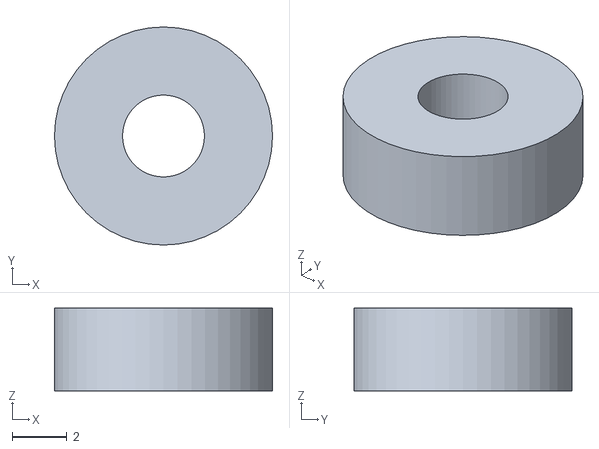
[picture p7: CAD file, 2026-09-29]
components/air-quality-monitor/enclosure/aqm spacer.stl
8.00 x 8.00 x 3.03

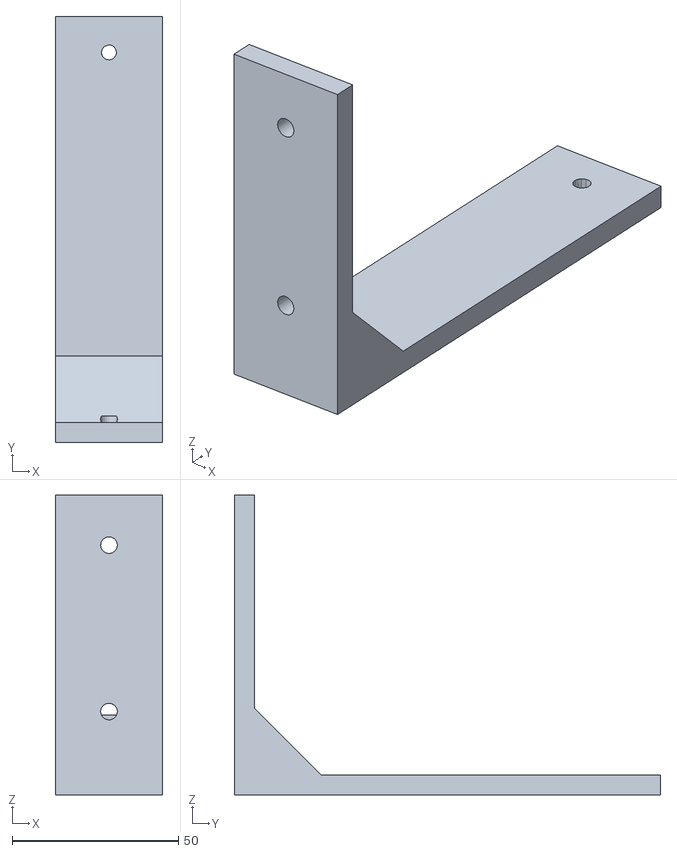
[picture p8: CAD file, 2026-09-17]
components/equip-shelf/Fan bracket.stl
32.0 x 128.0 x 90.0

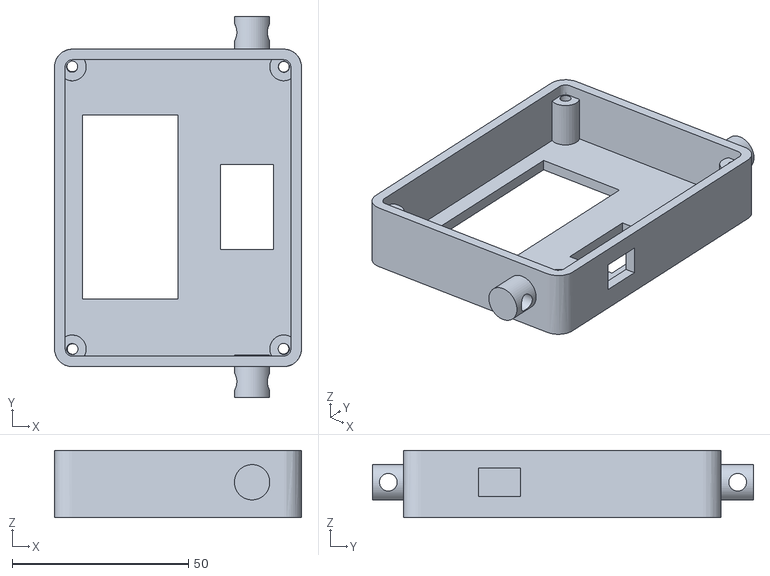
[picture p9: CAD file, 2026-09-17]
components/hiking-monitor/enclosure/hiking-monitor upper shell 3.stl
70.0 x 108.0 x 19.0

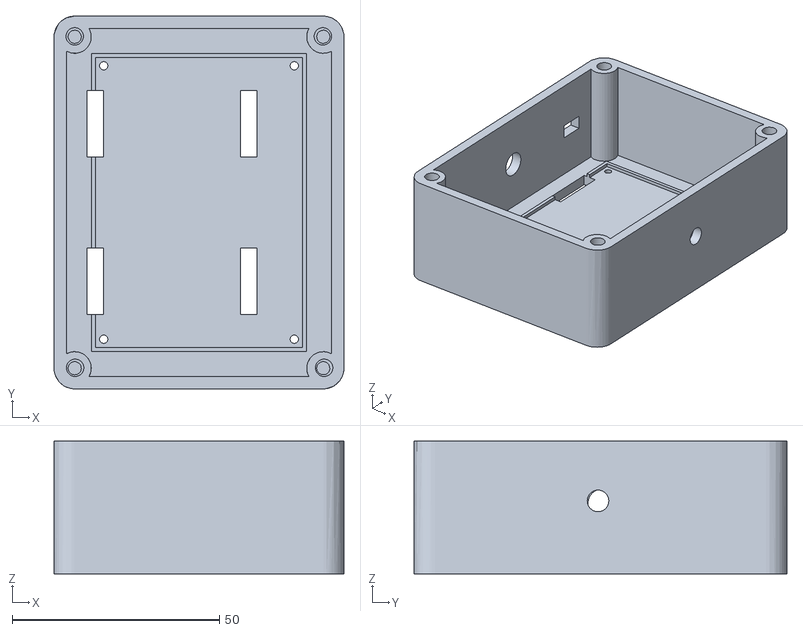
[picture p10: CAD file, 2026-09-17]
components/air-quality-monitor/enclosure/air quality monitor bottom shell.stl
70.0 x 90.0 x 32.0

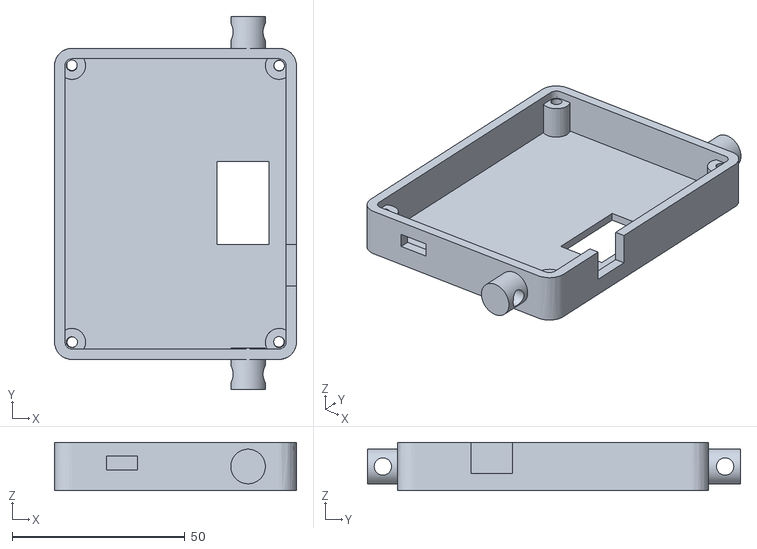
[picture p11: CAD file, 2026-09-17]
components/air-quality-monitor/enclosure/air quality monitor upper shell.stl
70.0 x 108.0 x 14.0

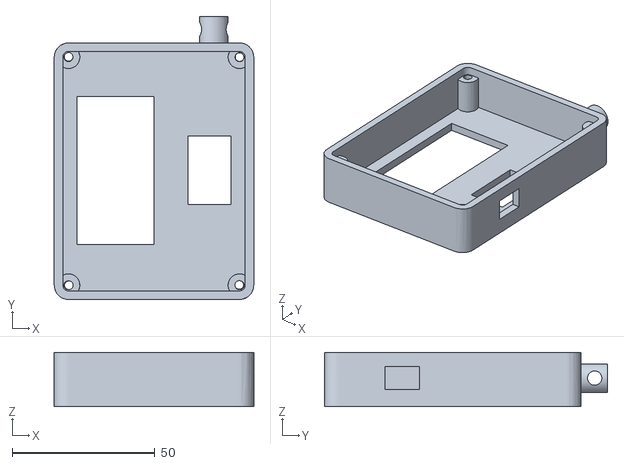
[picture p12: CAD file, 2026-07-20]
components/hiking-monitor/enclosure/upper-shell-2-final.stl
70.0 x 99.3 x 19.0

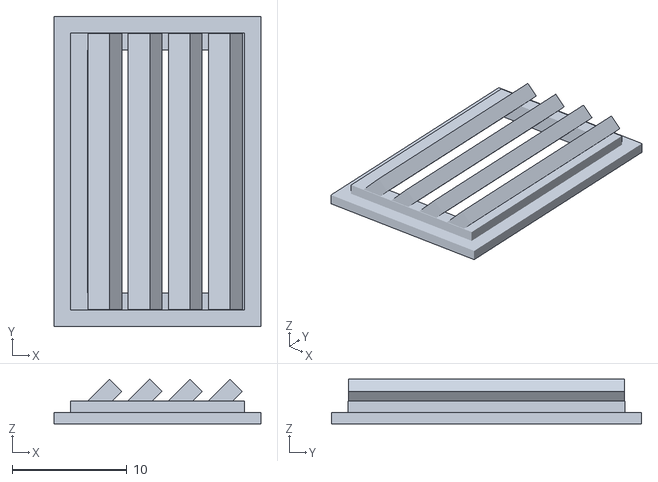
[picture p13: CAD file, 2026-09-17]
components/air-quality-monitor/enclosure/vent insert (1).stl
18.0 x 27.0 x 3.89

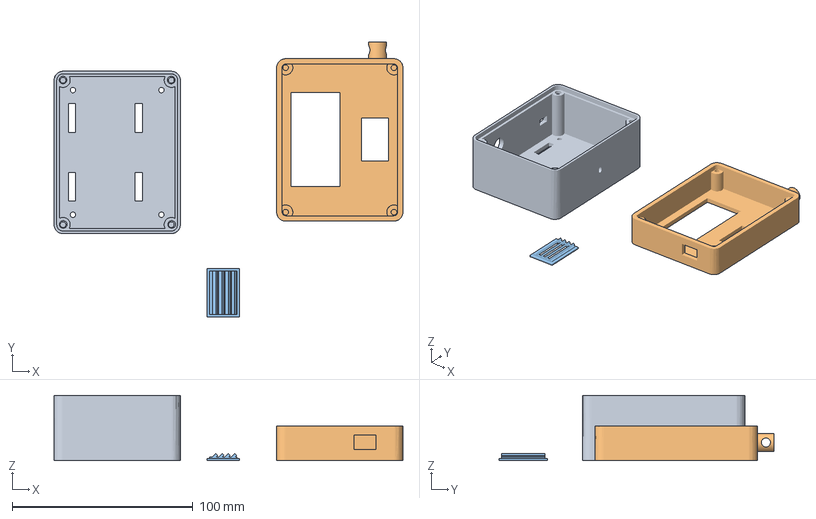
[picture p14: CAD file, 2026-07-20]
components/hiking-monitor/enclosure/all sensors-11.3mf
193.3 x 152.4 x 36.0 mm
bottom shell.stl
hiking-monitor upper shell.stl
vent insert.stl

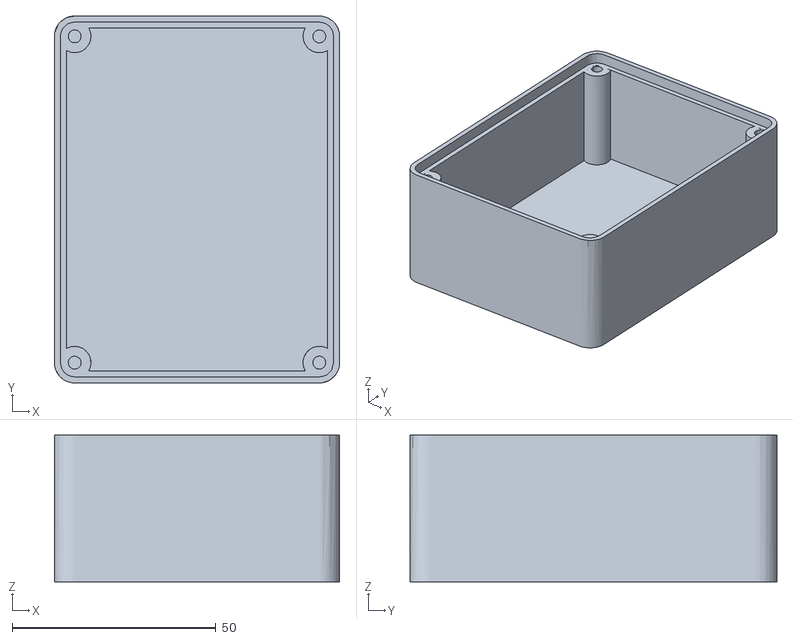
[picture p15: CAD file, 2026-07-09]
components/hiking-monitor/enclosure/bottom-shell-final.stl
70.0 x 90.0 x 36.0

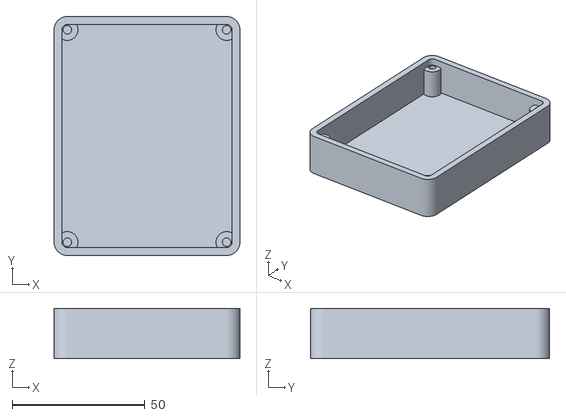
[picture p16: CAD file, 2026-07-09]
components/hiking-monitor/enclosure/top-shell-raw.stl
70.0 x 90.0 x 19.0

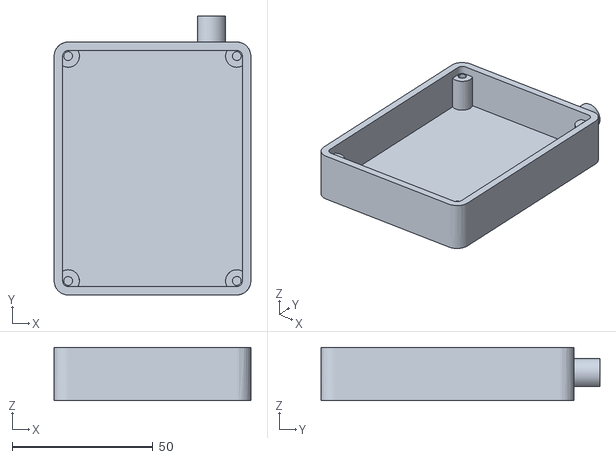
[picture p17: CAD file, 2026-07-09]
components/hiking-monitor/enclosure/top-shell-final.stl
70.0 x 99.3 x 19.0

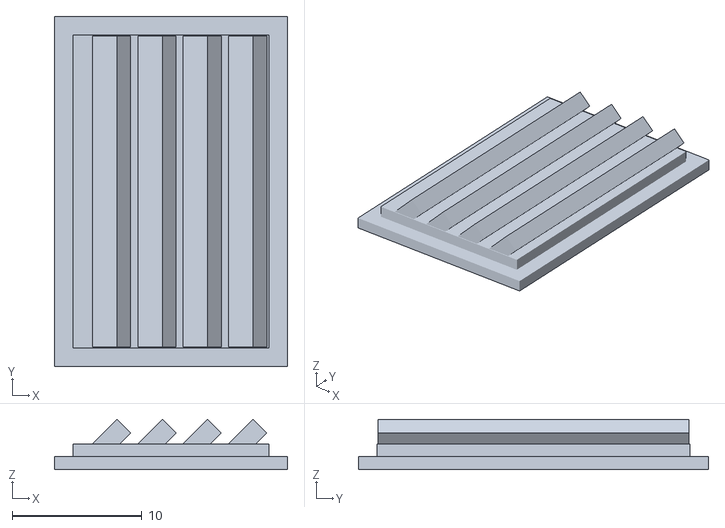
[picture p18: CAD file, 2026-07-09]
components/hiking-monitor/enclosure/vent-insert-final.stl
18.0 x 27.0 x 3.89

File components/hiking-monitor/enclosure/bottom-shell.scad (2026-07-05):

/*******************************************************************************
TITLE:
Easy box for electronic projects by pbtec

LICENSE:
Licensed under the Creative Commons - Attribution - Non-Commercial - Share Alike

DESCRIPTION:
Use Openscad customizer (Menu Window/unselect "hide customizer") to customize this box
I am aware that sometimes, when using too big or too small parameters, there are some rendering issues.
To prevent such issues, change only one parameter at once and check the result.

Customize:
- Use the first 4 modules to add objects or to cut out holes (there are already a few examples, uncomment them to use)
- Export the stl file from Openscad (F6 then F7). Then Import the stl file into your best known 3d program to make holes.
- You can also make the holes afterwards with the drilling machine.

Hope you can use it for you projects
Let me see your prints, and remakes and pls do not forget to press the like button

use https://paypal.me/pbtec if you want to spend me a coold beer. Thanks in advance :-)

AUTHOR:
pbtec / pb-tec.ch

VERSION:
V   KZZ DATE     COMMENT
1.0 pb  31.08.22 First Version to share
2.0 pb  08.07.23 Optimized Version with more customizations
2.1 pb  11.12.23 Some updates
2.2 pb  27.04.24 Final Version to share
2.3 pb  10.06.24 Size more granular possible
2.4 pb  01.07.25 Removed Array for size and for NormalScrewhead
                 and add a variable for each array element instead,
                 to make it more user friendly
*******************************************************************************/

/* [View settings] */
// Quality variable (40 fast / 150 for creating printable stl files)
$fn                       =            100 ; // [10:1:400]
// Quality variable interior parts (due to performance matter I would not go over 50)
$fnInterior               =            100 ; // [10:1:200]
Show                      =              1 ; // [0:Body and lid, 1:Body only, 2:lid only]
// Distance between Body and lid 10mm or more
Dist                      =             10 ;
// unselected=Body centered, selected=lid centered
Position                  =          false ;
/* [Box size settings] */
// Depth
SizeX                     = 70;
// Width
SizeY                     = 90;
// Height
SizeZ                     = 36;
// Corner rounding --> !!! Rounding must be same or bigger than WallThick, and not bigger than the half of the smaler side -1. Otherwise there are some rendering issues
Rounding                  =            5.0 ; //[1:1:100]
// Wall and bottom thickness
WallThick                 =            3.0 ; //[1:0.1:10]
// Lid thickness (only lid)
LidThick                  =            3.0 ; //[1:0.1:10]
// Gap between base and lid to make the lid a bit smaler to fit better (depends on your 3d printer quality) default 0.2mm
Gap                       =            0.2 ; //[0.01:0.01:1]
// Hole diameter in lid for Screw
/* [Screw / hot melt copper nut settings] */
// Size for the hole in the lid
HoleDiaLid                =            3.2 ; //[1:0.1:10]
// Hole diameter for thread or hot melt copper nut (thread 2.2 for 2.9mm / 2.8 for 3.5mm / 3.2 for 3.9mm Screw)
HoleDiaThread             =            4.2 ; //[1:0.1:10]
// Screw or hot melt nut Hole deepness (deepness in the Body/Cylinder). If too big, through hole possible
HoleDeepness              =           12.0 ; //[1:0.1:200]
// Cylinder dia for the Screw
ScrewCylinderDia          =           8.0 ; //[4:0.1:20]
// Add additional holes on x side
AddXScrew                 =           false ;
// Add additional holes on y side
AddYScrew                 =           false ;
// For stability you can connect the cylinder to the wall
ConnectCylinder           =           true ;
// Add chamfer to the bottom of the cylinder (depends on the HoleDeepness parameter). Use only when the cylinder is connected with the wall or when ConnectCylinder is activated
AddChamfer                =           false ;
//  Chamfer cut angle. Default 22. I would not go bigger than 45 to prevent printing issues, besides you use support
ChamferAngle              =             35 ;
// Select the using screw head
HoleType                  =              1 ; // [0:Hole only, 1:Countersink, 2:Normal screw head]
// CounterSink screw head diameter (use measured value) --> 5.5 for M3
CSHeadDia                 =            5.5 ; //[1:0.1:20]
// NormalScrew: Head diameter (The hole will be the size you enter)
NSHeadSizeHeadDia         = 6 ; //[1:0.1:20]
// NormalScrew: Screw head high (The hole will be the size you enter)
NSHeadSizeHeadHigh        = 2.5; //[1:0.1:10]
// Side hole distance from the outside of the body. Check the holes position on the lid
HolePos                   =            5.0 ; //[3:0.1:20]
/* [PCB body mounting cylinders 1] */
// Activate PCB mount cylinders on body
PCB_BodyMountCylActive    =          false ;
// Cylinder high
PCB_BodyCylHigh           =           14.0 ;  //[1:0.1:30]
// Cylinder diameter
PCB_BodyCylDia            =           12.0 ;  //[1:1:20]
// Cylinder thread hole (for screws or hot melt copper nut)
PCB_BodyCylHoleDia        =            3.8 ; //[1:0.1:15]
// X distance beteween the holes
PCB_BodyX_Dist            =           30.0 ;  //[1:0.1:1000]
// Y distance beteween the holes
PCB_BodyY_Dist            =           50.0 ;  //[1:0.1:1000]
// PCB X direction offset (+/-)
PCB_BodyX_offset          =          -30.0 ;  //[-1000:0.1:1000]
// PCB Y direction offset (+/-)
PCB_BodyY_offset          =            0.0 ;  //[-1000:0.1:1000]

/* [PCB body mounting cylinders 2] */
// Activate PCB mount cylinders on body
PCB_Body2MountCylActive   =          false ;
// Cylinder high
PCB_Body2CylHigh          =            8.0 ;  //[1:0.1:30]
// Cylinder diameter
PCB_Body2CylDia           =            8.0 ;  //[1:1:20]
// Cylinder thread hole (for screws or hot melt copper nut)
PCB_Body2CylHoleDia       =            3.8 ; //[1:0.1:15]

// X distance beteween the holes
PCB_Body2X_Dist           =           25.0 ; //[1:0.1:1000]
// Y distance beteween the holes
PCB_Body2Y_Dist           =           30.0 ; //[1:0.1:1000]
// PCB X direction offset (+/-)
PCB_Body2X_offset         =           30.0 ; //[-1000:0.1:1000]
// PCB Y direction offset (+/-)
PCB_Body2Y_offset         =           18.0 ; //[-1000:0.1:1000]

/* [PCB Lid mounting cylinders 1. Turn object upside down to see it ;-)] */
// Activate PCB mount cylinders on Lid
PCB_LidMountCylActive     =          false ;
// Cylinder high
PCB_LidCylHigh            =            8.0 ;  //[1:0.1:30]
// Cylinder diameter
PCB_LidCylDia             =            7.0 ;  //[1:1:20]
// Cylinder thread hole (for screws or hot melt copper nut)
PCB_LidCylHoleDia         =            3.8 ; //[1:0.1:15]

// X distance beteween the holes
PCB_LidX_Dist             =           30.0 ; //[1:0.1:1000]
// Y distance beteween the holes
PCB_LidY_Dist             =           50.0 ; //[1:0.1:1000]
// PCB X direction offset (+/-)
PCB_LidX_offset           =           30.0 ; //[-1000:0.1:1000]
// PCB Y direction offset (+/-)
PCB_LidY_offset           =            0.0 ; //[-1000:0.1:1000]

/* [PCB Lid mounting cylinders 2. Turn object upside down to see it ;-)] */
// Activate PCB mount cylinders on Lid
PCB_Lid2MountCylActive     =         false ;
// Cylinder high
PCB_Lid2CylHigh            =          12.0 ;  //[1:0.1:30]
// Cylinder diameter
PCB_Lid2CylDia             =          10.0 ;  //[1:1:20]
// Cylinder thread hole (for screws or hot melt copper nut)
PCB_Lid2CylHoleDia         =           4.6 ; //[1:0.1:15]

// X distance beteween the holes
PCB_Lid2X_Dist             =          40.0 ; //[1:0.1:1000]
// Y distance beteween the holes
PCB_Lid2Y_Dist             =          30.0 ; //[1:0.1:1000]
// PCB X direction offset (+/-)
PCB_Lid2X_offset           =         -30.0 ; //[-1000:0.1:1000]
// PCB Y direction offset (+/-)
PCB_Lid2Y_offset           =          20.0 ; //[-1000:0.1:1000]

/* [Control cuts] */
HorizontalCut             =          false ;
VerticalCut               =          false ;
DiagonalCut               =          false ;

/* [Project] */
Buy_PBTEC_a_Beer          =          false ;
// M A I N

if (Buy_PBTEC_a_Beer) {color("gold") translate([0,-SizeY/2,SizeZ*2+35]) rotate([90,0,90]) linear_extrude(10) text(str("Thanks, highly appreciated!"),halign = "center", size= 22,font="Liberation Sans:style=Bold");
color("gold") translate([0,-SizeY/2,SizeZ*2]) rotate([90,0,90]) linear_extrude(10) text(str("paypal.me/pbtec"),halign = "center", size= 22,font="Liberation Sans:style=Bold");}
//paypal.me/pbtec  Thanks!
color("SkyBlue") EasyProjectBox ();
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

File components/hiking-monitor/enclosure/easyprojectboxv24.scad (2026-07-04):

/*******************************************************************************
TITLE:
Easy box for electronic projects by pbtec

LICENSE:
Licensed under the Creative Commons - Attribution - Non-Commercial - Share Alike

DESCRIPTION:
Use Openscad customizer (Menu Window/unselect "hide customizer") to customize this box
I am aware that sometimes, when using too big or too small parameters, there are some rendering issues.
To prevent such issues, change only one parameter at once and check the result.

Customize:
- Use the first 4 modules to add objects or to cut out holes (there are already a few examples, uncomment them to use)
- Export the stl file from Openscad (F6 then F7). Then Import the stl file into your best known 3d program to make holes.
- You can also make the holes afterwards with the drilling machine.

Hope you can use it for you projects
Let me see your prints, and remakes and pls do not forget to press the like button

use https://paypal.me/pbtec if you want to spend me a coold beer. Thanks in advance :-)

AUTHOR:
pbtec / pb-tec.ch

VERSION:
V   KZZ DATE     COMMENT
1.0 pb  31.08.22 First Version to share
2.0 pb  08.07.23 Optimized Version with more customizations
2.1 pb  11.12.23 Some updates
2.2 pb  27.04.24 Final Version to share
2.3 pb  10.06.24 Size more granular possible
2.4 pb  01.07.25 Removed Array for size and for NormalScrewhead
                 and add a variable for each array element instead,
                 to make it more user friendly
*******************************************************************************/

/* [View settings] */
// Quality variable (40 fast / 150 for creating printable stl files)
$fn                       =            100 ; // [10:1:400]
// Quality variable interior parts (due to performance matter I would not go over 50)
$fnInterior               =            100 ; // [10:1:200]
Show                      =              0 ; // [0:Body and lid, 1:Body only, 2:lid only]
// Distance between Body and lid 10mm or more
Dist                      =             10 ;
// unselected=Body centered, selected=lid centered
Position                  =          false ;
/* [Box size settings] */
// Depth
SizeX                     = 140;
// Width
SizeY                     = 110;
// Height
SizeZ                     = 45;
// Corner rounding --> !!! Rounding must be same or bigger than WallThick, and not bigger than the half of the smaler side -1. Otherwise there are some rendering issues
Rounding                  =            5.0 ; //[1:1:100]
// Wall and bottom thickness
WallThick                 =            3.0 ; //[1:0.1:10]
// Lid thickness (only lid)
LidThick                  =            3.0 ; //[1:0.1:10]
// Gap between base and lid to make the lid a bit smaler to fit better (depends on your 3d printer quality) default 0.2mm
Gap                       =            0.2 ; //[0.01:0.01:1]
// Hole diameter in lid for Screw
/* [Screw / hot melt copper nut settings] */
// Size for the hole in the lid
HoleDiaLid                =            3.2 ; //[1:0.1:10]
// Hole diameter for thread or hot melt copper nut (thread 2.2 for 2.9mm / 2.8 for 3.5mm / 3.2 for 3.9mm Screw)
HoleDiaThread             =            3.2 ; //[1:0.1:10]
// Screw or hot melt nut Hole deepness (deepness in the Body/Cylinder). If too big, through hole possible
HoleDeepness              =           12.0 ; //[1:0.1:200]
// Cylinder dia for the Screw
ScrewCylinderDia          =           12.0 ; //[4:0.1:20]
// Add additional holes on x side
AddXScrew                 =           true ;
// Add additional holes on y side
AddYScrew                 =           true ;
// For stability you can connect the cylinder to the wall
ConnectCylinder           =           true ;
// Add chamfer to the bottom of the cylinder (depends on the HoleDeepness parameter). Use only when the cylinder is connected with the wall or when ConnectCylinder is activated
AddChamfer                =           true ;
//  Chamfer cut angle. Default 22. I would not go bigger than 45 to prevent printing issues, besides you use support
ChamferAngle              =             35 ;
// Select the using screw head
HoleType                  =              1 ; // [0:Hole only, 1:Countersink, 2:Normal screw head]
// CounterSink screw head diameter (use measured value) --> 5.5 for M3
CSHeadDia                 =            5.5 ; //[1:0.1:20]
// NormalScrew: Head diameter (The hole will be the size you enter)
NSHeadSizeHeadDia         = 6 ; //[1:0.1:20]
// NormalScrew: Screw head high (The hole will be the size you enter)
NSHeadSizeHeadHigh        = 2.5; //[1:0.1:10]
// Side hole distance from the outside of the body. Check the holes position on the lid
HolePos                   =            7.0 ; //[3:0.1:20]
/* [PCB body mounting cylinders 1] */
// Activate PCB mount cylinders on body
PCB_BodyMountCylActive    =          false ;
// Cylinder high
PCB_BodyCylHigh           =           14.0 ;  //[1:0.1:30]
// Cylinder diameter
PCB_BodyCylDia            =           12.0 ;  //[1:1:20]
// Cylinder thread hole (for screws or hot melt copper nut)
PCB_BodyCylHoleDia        =            3.8 ; //[1:0.1:15]
// X distance beteween the holes
PCB_BodyX_Dist            =           30.0 ;  //[1:0.1:1000]
// Y distance beteween the holes
PCB_BodyY_Dist            =           50.0 ;  //[1:0.1:1000]
// PCB X direction offset (+/-)
PCB_BodyX_offset          =          -30.0 ;  //[-1000:0.1:1000]
// PCB Y direction offset (+/-)
PCB_BodyY_offset          =            0.0 ;  //[-1000:0.1:1000]

/* [PCB body mounting cylinders 2] */
// Activate PCB mount cylinders on body
PCB_Body2MountCylActive   =          false ;
// Cylinder high
PCB_Body2CylHigh          =            8.0 ;  //[1:0.1:30]
// Cylinder diameter
PCB_Body2CylDia           =            8.0 ;  //[1:1:20]
// Cylinder thread hole (for screws or hot melt copper nut)
PCB_Body2CylHoleDia       =            3.8 ; //[1:0.1:15]

// X distance beteween the holes
PCB_Body2X_Dist           =           25.0 ; //[1:0.1:1000]
// Y distance beteween the holes
PCB_Body2Y_Dist           =           30.0 ; //[1:0.1:1000]
// PCB X direction offset (+/-)
PCB_Body2X_offset         =           30.0 ; //[-1000:0.1:1000]
// PCB Y direction offset (+/-)
PCB_Body2Y_offset         =           18.0 ; //[-1000:0.1:1000]

/* [PCB Lid mounting cylinders 1. Turn object upside down to see it ;-)] */
// Activate PCB mount cylinders on Lid
PCB_LidMountCylActive     =          false ;
// Cylinder high
PCB_LidCylHigh            =            8.0 ;  //[1:0.1:30]
// Cylinder diameter
PCB_LidCylDia             =            7.0 ;  //[1:1:20]
// Cylinder thread hole (for screws or hot melt copper nut)
PCB_LidCylHoleDia         =            3.8 ; //[1:0.1:15]

// X distance beteween the holes
PCB_LidX_Dist             =           30.0 ; //[1:0.1:1000]
// Y distance beteween the holes
PCB_LidY_Dist             =           50.0 ; //[1:0.1:1000]
// PCB X direction offset (+/-)
PCB_LidX_offset           =           30.0 ; //[-1000:0.1:1000]
// PCB Y direction offset (+/-)
PCB_LidY_offset           =            0.0 ; //[-1000:0.1:1000]

/* [PCB Lid mounting cylinders 2. Turn object upside down to see it ;-)] */
// Activate PCB mount cylinders on Lid
PCB_Lid2MountCylActive     =         false ;
// Cylinder high
PCB_Lid2CylHigh            =          12.0 ;  //[1:0.1:30]
// Cylinder diameter
PCB_Lid2CylDia             =          10.0 ;  //[1:1:20]
// Cylinder thread hole (for screws or hot melt copper nut)
PCB_Lid2CylHoleDia         =           4.6 ; //[1:0.1:15]

// X distance beteween the holes
PCB_Lid2X_Dist             =          40.0 ; //[1:0.1:1000]
// Y distance beteween the holes
PCB_Lid2Y_Dist             =          30.0 ; //[1:0.1:1000]
// PCB X direction offset (+/-)
PCB_Lid2X_offset           =         -30.0 ; //[-1000:0.1:1000]
// PCB Y direction offset (+/-)
PCB_Lid2Y_offset           =          20.0 ; //[-1000:0.1:1000]

/* [Control cuts] */
HorizontalCut             =          false ;
VerticalCut               =          false ;
DiagonalCut               =          false ;

/* [Project] */
Buy_PBTEC_a_Beer          =          false ;
// M A I N

if (Buy_PBTEC_a_Beer) {color("gold") translate([0,-SizeY/2,SizeZ*2+35]) rotate([90,0,90]) linear_extrude(10) text(str("Thanks, highly appreciated!"),halign = "center", size= 22,font="Liberation Sans:style=Bold");
color("gold") translate([0,-SizeY/2,SizeZ*2]) rotate([90,0,90]) linear_extrude(10) text(str("paypal.me/pbtec"),halign = "center", size= 22,font="Liberation Sans:style=Bold");}
//paypal.me/pbtec  Thanks!
color("SkyBlue") EasyProjectBox ();
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

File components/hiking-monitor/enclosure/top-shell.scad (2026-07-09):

/*******************************************************************************
TITLE:
Easy box for electronic projects by pbtec

LICENSE:
Licensed under the Creative Commons - Attribution - Non-Commercial - Share Alike

DESCRIPTION:
Use Openscad customizer (Menu Window/unselect "hide customizer") to customize this box
I am aware that sometimes, when using too big or too small parameters, there are some rendering issues.
To prevent such issues, change only one parameter at once and check the result.

Customize:
- Use the first 4 modules to add objects or to cut out holes (there are already a few examples, uncomment them to use)
- Export the stl file from Openscad (F6 then F7). Then Import the stl file into your best known 3d program to make holes.
- You can also make the holes afterwards with the drilling machine.

Hope you can use it for you projects
Let me see your prints, and remakes and pls do not forget to press the like button

use https://paypal.me/pbtec if you want to spend me a coold beer. Thanks in advance :-)

AUTHOR:
pbtec / pb-tec.ch

VERSION:
V   KZZ DATE     COMMENT
1.0 pb  31.08.22 First Version to share
2.0 pb  08.07.23 Optimized Version with more customizations
2.1 pb  11.12.23 Some updates
2.2 pb  27.04.24 Final Version to share
2.3 pb  10.06.24 Size more granular possible
2.4 pb  01.07.25 Removed Array for size and for NormalScrewhead
                 and add a variable for each array element instead,
                 to make it more user friendly
*******************************************************************************/

/* [View settings] */
// Quality variable (40 fast / 150 for creating printable stl files)
$fn                       =            100 ; // [10:1:400]
// Quality variable interior parts (due to performance matter I would not go over 50)
$fnInterior               =            100 ; // [10:1:200]
Show                      =              1 ; // [0:Body and lid, 1:Body only, 2:lid only]
// Distance between Body and lid 10mm or more
Dist                      =             10 ;
// unselected=Body centered, selected=lid centered
Position                  =          false ;
/* [Box size settings] */
// Depth
SizeX                     = 70;
// Width
SizeY                     = 90;
// Height
SizeZ                     = 19;
// Corner rounding --> !!! Rounding must be same or bigger than WallThick, and not bigger than the half of the smaler side -1. Otherwise there are some rendering issues
Rounding                  =            5.0 ; //[1:1:100]
// Wall and bottom thickness
WallThick                 =            3.0 ; //[1:0.1:10]
// Lid thickness (only lid)
LidThick                  =            3.0 ; //[1:0.1:10]
// Gap between base and lid to make the lid a bit smaler to fit better (depends on your 3d printer quality) default 0.2mm
Gap                       =            0.2 ; //[0.01:0.01:1]
// Hole diameter in lid for Screw
/* [Screw / hot melt copper nut settings] */
// Size for the hole in the lid
HoleDiaLid                =            3.2 ; //[1:0.1:10]
// Hole diameter for thread or hot melt copper nut (thread 2.2 for 2.9mm / 2.8 for 3.5mm / 3.2 for 3.9mm Screw)
HoleDiaThread             =            3.2 ; //[1:0.1:10]
// Screw or hot melt nut Hole deepness (deepness in the Body/Cylinder). If too big, through hole possible
HoleDeepness              =           12.0 ; //[1:0.1:200]
// Cylinder dia for the Screw
ScrewCylinderDia          =           8.0 ; //[4:0.1:20]
// Add additional holes on x side
AddXScrew                 =           false ;
// Add additional holes on y side
AddYScrew                 =           false ;
// For stability you can connect the cylinder to the wall
ConnectCylinder           =           true ;
// Add chamfer to the bottom of the cylinder (depends on the HoleDeepness parameter). Use only when the cylinder is connected with the wall or when ConnectCylinder is activated
AddChamfer                =           false ;
//  Chamfer cut angle. Default 22. I would not go bigger than 45 to prevent printing issues, besides you use support
ChamferAngle              =             35 ;
// Select the using screw head
HoleType                  =              1 ; // [0:Hole only, 1:Countersink, 2:Normal screw head]
// CounterSink screw head diameter (use measured value) --> 5.5 for M3
CSHeadDia                 =            5.5 ; //[1:0.1:20]
// NormalScrew: Head diameter (The hole will be the size you enter)
NSHeadSizeHeadDia         = 6 ; //[1:0.1:20]
// NormalScrew: Screw head high (The hole will be the size you enter)
NSHeadSizeHeadHigh        = 2.5; //[1:0.1:10]
// Side hole distance from the outside of the body. Check the holes position on the lid
HolePos                   =            5.0 ; //[3:0.1:20]
/* [PCB body mounting cylinders 1] */
// Activate PCB mount cylinders on body
PCB_BodyMountCylActive    =          false ;
// Cylinder high
PCB_BodyCylHigh           =           14.0 ;  //[1:0.1:30]
// Cylinder diameter
PCB_BodyCylDia            =           12.0 ;  //[1:1:20]
// Cylinder thread hole (for screws or hot melt copper nut)
PCB_BodyCylHoleDia        =            3.8 ; //[1:0.1:15]
// X distance beteween the holes
PCB_BodyX_Dist            =           30.0 ;  //[1:0.1:1000]
// Y distance beteween the holes
PCB_BodyY_Dist            =           50.0 ;  //[1:0.1:1000]
// PCB X direction offset (+/-)
PCB_BodyX_offset          =          -30.0 ;  //[-1000:0.1:1000]
// PCB Y direction offset (+/-)
PCB_BodyY_offset          =            0.0 ;  //[-1000:0.1:1000]
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

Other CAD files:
components/equip-shelf/fan_bracket_ACInfinity_S7.stl
components/hiking-monitor/enclosure/hiking-monitor bottom shell 2.stl
components/hiking-monitor/enclosure/bottom-shell-2-final.stl
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

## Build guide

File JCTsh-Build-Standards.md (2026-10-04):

# JCTsh Build Standards
**Author:** Joseph C Thomas (JCT)
**Purpose:** Defines the required build, integration, and documentation standards for all JCTsh smart home components. Claude Code consults this file before beginning any component build.
**Version:** 1.41
**Version description:** CARD-0335 — §4.1's boot-time heartbeat rule now states its applicability instead of saying "every component": the false watchdog alert needs the worst-case gap (2 × the heartbeat interval plus the reboot's downtime) to exceed the 35-minute timeout, i.e. an interval above roughly 15 minutes. 30-minute heartbeats must send a boot heartbeat; the 5-minute heartbeats (`hiking-monitor`, `air-quality-monitor`) cannot hit it and are exempt; systemd-timer heartbeats already do it with `OnBootSec=2min` (`photo-server`, `p-w-firefly`).
**Version history:** `JCTsh-Build-Standards-History.md`
**Project:** JCTsh — Smart Home Automation
**Related files:** README.md, CLAUDE.md, JCTsh-Component-Planning-Pattern.md, JCTsh-Parts-Inventory.md, `JCTsh-Build-Standards-History.md` (full version-change history), `tos/JCTsh-Operating-System.md` (process/policy/workflow — see the reconciliation note below for how the two relate)

---

## How to Use This Document

These standards apply to every JCTsh component build. Claude Code must read this file at the start of every project and apply all relevant standards before producing any documentation, configuration, or code. Standards are not optional and are not subject to deferral unless explicitly overridden by the Claude Code instruction set for a specific project.

When a standard says "examine the existing pattern," Claude Code must locate and read the relevant existing component files before writing anything. Never invent a new convention when an existing one can be matched.

**Scope boundary, reconciled with `tos/JCTsh-Operating-System.md`:** this document is technology/build conventions — how to wire, name, and configure things. Process, policy, and workflow — how work moves through the board, how a session decides what to pick up, documentation-structure principles — live in `tos/JCTsh-Operating-System.md` instead. A standard that would still make sense in a repo with no hardware or code at all belongs there, not here.

---

## 1. Physical Build Standards

### 1.1 Enclosure Convention

Open standoff mount is the **default first option** for ESP32 and small PCB projects. No enclosure panels. The perfboard is mounted using M3 brass male-female standoffs that space the board away from the mounting surface for cable clearance and serve as the attachment points.

Escalate to a more enclosed option only when:
- The component is installed outdoors or in a weather-exposed location → use a weatherproof project box
- The component requires a finished appearance outside the workshop → use a project box
- Dust accumulation becomes a documented problem → add an acrylic lid panel (cut to perfboard footprint, held by the same standoffs)

Never purchase or specify an enclosure without first confirming the open standoff mount is unsuitable for the specific installation context.

**Any component moving to an enclosed option (project box or 3D-printed enclosure) must satisfy §1.7 (Accessible Power Control for Enclosed Devices) as part of the design, before the enclosure is finalized/sealed in assembly** — not discovered afterward. See §1.7 for what "satisfy" requires and why it has to be decided this early.

### 1.2 Breadboard vs. Perfboard

- **Breadboard:** prototyping and validation only. Never the final install.
- **Perfboard:** all permanent builds. Validate the full circuit on the breadboard before transferring to perfboard. Nothing gets soldered until breadboard validation is complete.
- **Perfboard size:** 5×7cm Chanzon FR4 boards are the standard for ESP32 DevKit projects.
- **Component socketing:** ESP32 DevKit plugs into two 19-pin female header strips soldered to the perfboard — not soldered directly. This keeps the ESP32 removable for replacement or reuse. Other modules use female header strips sized to their pin count.
- **Identify pins by their printed silkscreen label, not a documented reference table's position numbers.** Different ESP32 board brands/clones (e.g. a generic "38-pin ESP32 DevKitC-32" vs. a SparkleIoT XH-32S) can have completely different physical pin *order* despite the same GPIO count and nominal form factor. A documented per-component pin table (like an `ESP32-project-pins.md`) is only as good as the specific physical board it was written against — verify against the actual board's printed labels before soldering or probing, every time, even if a table already exists. Established after `salt-sensor`'s CARD-0049 perfboard build found its documented pin table didn't match the actual board in hand.
- **Add isolation checks between visually-adjacent pin labels to Pre-Power Checks**, not just intentional-net continuity checks. Dense silkscreens put unrelated pins (e.g. `D5`/`TX2`/`RX2`) right next to each other, and it's easy to solder to the wrong one while reading quickly — this is exactly what happened on `salt-sensor`'s build (Trig landed on `RX2` instead of `D5`), caught only because Pre-Power Checks were done by reading labels rather than trusting the (wrong) documented position. For any pin sitting near a similarly-named or visually-adjacent label, add an explicit "should be OL/open, not beep" check between the two, alongside the normal intended-net checks.
- **Use `JCTsh-Perfboard-Build-Template.md`** (repo root) as the section skeleton for a new component's `perfboard-layout.md` — Board Note, Bus Planning, Assembly Sequence, Pre-Power Checks, and Reboot/Power-Cycle Verification are all proven-out structure, not a from-scratch design each time.

### 1.3 Standoffs

M3 brass male-female standoffs are the standard mounting hardware. Check JCTsh-Parts-Inventory.md for available sizes before specifying. Default length: 10mm for perfboard-to-surface clearance.

### 1.4 Parts Inventory

Consult JCTsh-Parts-Inventory.md before adding any item to the BOM. Use on-hand parts before purchasing. Update the inventory update log at the end of every project.

### 1.5 3D-Printed Enclosure Build Pattern

A further escalation beyond §1.1's project-box option, for components needing integrated apertures, mounting features, or a cavity shape no off-the-shelf box provides. Use `JCTsh-3D-Enclosure-Instructions-Template.md` (repo root) as the instruction-set skeleton for any new printed-enclosure build — generalized from the hiking-monitor enclosure build (CARD-0009), the first component to go through this process end-to-end.

- **Two-tool workflow:** OpenSCAD generates the parametric two-piece shell (a downloaded parametric template, not built from scratch); Tinkercad adds all cutouts, apertures, and mounting features on top of the OpenSCAD export.
- **File naming:** `-raw` = initial OpenSCAD export, before any Tinkercad edits; `-final` = after Tinkercad finalizes cutouts/features. Applies to every shell/insert STL in a component's `enclosure/` folder.
- **Print orientation:** shells print open-face down on the bed — clean result, no supports needed.
- **Test print before final print, always:** validate fit and dimensions in a cheap material (PLA) first; never print the final material on the first attempt. Iterate print → real-hardware test-fit → Tinkercad correction until every fit check passes, before scheduling the final-material print session.
- **Fastening:** hex-nut capture in printed corner bosses (pressed in with needle-nose pliers) is the preferred first-choice method — no extra tooling beyond what's already on hand, unlike heat-set threaded inserts.
- **Final material:** ASA by default for any outdoor/sun-exposed install; PETG as the fallback if ASA isn't available. If falling back, confirm the actual printer/bed can reach the fallback material's required temps — don't assume a backup printer can substitute without checking (see hiking-monitor's Elegoo Centauri Carbon vs. PLA-only-backup situation).
- **Press-fit insert tolerance:** size the insert 0.2mm tighter than its cutout, on both width and height, for a snug press fit without forcing.
- **Slot sizing patterns:** strap slot = strap width + 1mm wide (established at 4mm tall); connector slot (e.g. USB-C) = socket width/height + 0.5mm each dimension.
- **Bail/loop sizing:** a carabiner or similar loop feature's inner diameter = the mating hardware's spine/body thickness + 3mm minimum clearance.
- **Design-record discipline:** live Tinkercad edits made during a physical test-fit session are easy to make and easy to forget to record. If the plan doc reserves a section for reproducing the design (exact dimensions, hole positions), update it in the same session the edit happens — not as a deferred cleanup step. A plan doc that drifts out of sync with the live Tinkercad project can only be caught by re-opening Tinkercad or re-measuring by hand; treat that drift as a real, observed risk on this build type, not a hypothetical one.
- **Run the pattern-harvest step for real.** It's easy to consider a build "done" once the hardware works and skip reviewing it for new reusable patterns — the harvest is what makes the next enclosure build faster than the last. Confirm explicitly, every time, whether anything new applies to this section.

### 1.6 Sensor Cable Relocation for Mounting-Orientation Flexibility

When a sensor is rigid-socket-mounted (soldered pin headers) directly to the main perfboard, but final assembly needs it to face a different direction than the board's own orientation dictates (e.g. a sky-facing UV/light sensor on a board that mounts flat), replace the rigid header connection with a flexible cable between the sensor and the board — STEMMA QT/Qwiic for I2C sensors that support it, or extended Dupont leads otherwise — so the sensor can be positioned and oriented independently of the main board inside the enclosure.

- **Verify pinout empirically, don't assume color-to-color continuity from breadboard jumpers.** Cable color conventions can differ between a breadboard prototype and a purpose-made cable — STEMMA QT cables are SDA/SCL-swapped from typical breadboard jumper coloring. Confirm against the sensor's datasheet, not by matching wire colors to the old breadboard wiring.
- **Document the change with a dated addendum, not an overwrite.** Update the wiring and perfboard-layout docs to reflect the new cable/pinout, but keep the original build history intact rather than rewriting over it — the original prototype wiring remains useful reference even after the change.
- Only the sensor-side segment changes; traces from the main board to the microcontroller stay as they were.

### 1.7 Accessible Power Control for Enclosed Devices

**Any component going into a project box or 3D-printed enclosure must have both of the following reachable from outside the sealed enclosure, without disassembly:**

1. **A true hard power-off** — a mechanism that actually breaks the power path from the battery/power source to the rest of the circuit, reducing draw to zero (or as close as the hardware allows).
2. **A reboot/reset trigger** — a way to force the device to restart without opening the enclosure, either physically (an exposed reset button) or remotely (a software-triggered restart reachable over the network/MQTT/HA).

**This must be decided and designed in before the enclosure is finalized and sealed in final assembly — not discovered afterward.** Once a device is sealed into its permanent enclosure, adding either of these requires full disassembly, which defeats the purpose. Include this explicitly in the enclosure planning doc's design checklist, alongside apertures and mounting features.

**The concrete failure this standard exists to prevent:** hiking-monitor's final assembly (CARD-0009) surfaced both gaps only after the enclosure was already sealed — CARD-0181 (no accessible true off-state; the only hard-off is unplugging the LiPo's internal JST connector, unreachable once assembled) and CARD-0180 (no reboot mechanism, physical or remote). A contributing root cause worth calling out on its own: the device's slide switch *looks* like a power switch (an externally accessible toggle on the case) but isn't one — it only sets a GPIO-read mode flag; the actual power path (`VOUT+` → ESP32 `VIN`) runs through it untouched, so flipping it doesn't cut power at all, only changes firmware behavior. **Don't assume an externally accessible switch satisfies this standard just because it looks like a power switch — verify it actually sits in the power path, not just a GPIO input,** before relying on it to meet requirement 1 above.

Acceptable approaches for requirement 1 include (not exhaustive): an inline switch wired directly into the battery path (not a mode-select switch tapped off a GPIO) with its actuator reachable through the enclosure wall; or a battery connector (e.g. JST) pigtailed out to an externally accessible cutout so it can be unplugged without opening the case. For requirement 2: a firmware-level restart routine triggered over MQTT/HA (see `JCTsh-Build-Standards.md` §3 for the MQTT conventions this would use) is generally preferable to a physical reset button on a battery-powered field device, since it doesn't need an extra enclosure penetration — but either satisfies the standard.

---

## 2. ESP32 / ESPHome Standards

### 2.1 Platform

ESPHome is the required platform for all new ESP32 components. Arduino C++ is not used for new builds. Existing components built in Arduino C++ (e.g. salt sensor) are not required to migrate.

### 2.2 ESPHome Version

Verify ESPHome version before flashing. The native LD2412 component requires 2025.8.0 or later. Document the minimum required version in the component instruction set when a version dependency exists.

### 2.3 UART

Hardware UART only. Never use software UART (SoftwareSerial). On ESP32 DevKitC-32:
- UART0 (GPIO1/GPIO3) — used for USB, do not use for peripherals
- UART1 — may conflict with flash on some boards, avoid unless confirmed safe
- UART2 (GPIO16 RX / GPIO17 TX) — recommended for peripheral use

**Design provision for a secondary debug UART, required for any component that will lose convenient use of its onboard USB-C port for live debugging once built/deployed.** The onboard port stops being a reliable debug console whenever any of the following holds, not just the battery case:
- **Battery-powered with a separate regulator** — USB and the battery/regulator path can't safely be powered simultaneously (backfeed risk between the two regulators), so the onboard port can only show logs while running on USB power, never on the actual battery path a real boot-time or field issue happens on.
- **Going into an enclosure** — once sealed, the onboard port is no longer conveniently reachable without disassembly, regardless of power source.
- **Deployed somewhere physically inconvenient** — mounted, outdoor, or otherwise not sitting on a bench next to a PC when the behavior worth watching actually happens.
- **Debugging a WiFi/MQTT problem specifically** — OTA-based log visibility depends on the very transport that may be what's failing, so it can't be trusted as the only debug channel for that class of issue.

Reserve GPIO17 (UART2 TX) for this at design time on any component meeting one or more of the above — free of other duty, not claimed by a sensor or switch — so a debug adapter can be added later with a two-wire jumper addition, not a rework. TX-only is sufficient (`logger:` only ever transmits); RX/GPIO16 doesn't need to be reserved.

**A real ESPHome gap, not a wiring mistake, if UART2 produces zero bytes despite correct wiring:** `logger: hardware_uart: UART2` configures and starts the peripheral but never calls `uart_set_pin()` to actually route it through the GPIO matrix to GPIO17 — confirmed directly in ESPHome's own `logger_esp32.cpp`. Fix with a manual call in `esphome.on_boot`, as early as possible so it captures as much of the boot sequence as it can:
```yaml
- lambda: |-
    uart_set_pin(UART_NUM_2, GPIO_NUM_17, UART_PIN_NO_CHANGE, UART_PIN_NO_CHANGE, UART_PIN_NO_CHANGE);
```

**Adapter wiring:** `GPIO17 → adapter RXD`, `ESP32 GND → adapter GND` only. Leave the adapter's own VCC/3V3 output disconnected — connecting it would introduce a second, unisolated power source onto the board at the exact moment the whole point is testing the board's real battery/regulator path in isolation.

**The single most time-consuming failure mode: a disconnected GND wire produces total silence, not an error.** No garbled bytes, no exception, nothing — UART has no way to decode a signal with no shared ground reference, so it just looks identical to "nothing is being sent." This is a genuine, silent single point of failure on any breadboard build using a jumper for this connection — worth a continuity check first, before assuming a firmware regression, any time capture that previously worked suddenly stops.

**Isolation order when troubleshooting a non-working capture**, cheapest and most conclusive first:
1. **Loopback the adapter to itself** (its own TX jumpered to its own RX, disconnected from the board) and confirm known bytes sent to the COM port read back correctly — rules out the adapter, its driver, and the COM port as a group before touching the board at all.
2. **Confirm the actual GPIO is toggling** with a multimeter (a temporary plain digital-output test, since a UART pin can't share duty with `logger:` at the same time) before trusting anything about the signal's content.
3. Only then suspect the firmware/library layer itself.

### 2.4 Credentials

All WiFi credentials and MQTT broker addresses must use `!secret` references in ESPHome YAML. Never hardcode credentials. Secrets stored in `components/<name>/secrets.yaml` (gitignored).

### 2.5 Firmware Updates

First flash via USB. All subsequent updates via ESPHome OTA. Document the OTA update command in the component flashing.md.

**Do not reboot within ~60 s of an OTA flash, and verify what is actually running (CARD-0333, 2026-09-24).** ESP32 OTA has automatic rollback: if the new image reboots before it is marked valid (~60 s — the `safe_mode` log line `Boot seems successful; resetting boot loop counter`), the bootloader silently reverts to the previous firmware while every tool still reports success. A restart-button press, power cycle, or second flash inside that window undoes the update. After flashing, wait past 60 s, then confirm the device's *reported* config hash — the `sw` field of its retained discovery message (`homeassistant/sensor/<name>/<entity>/config`, e.g. `2026.4.5 (config hash 0x…)`) — equals the build's `config_hash` before concluding anything from the device's behavior. Found live: two front-porch flashes were rolled back by restart presses 12 s and 19 s after upload, and the "new" firmware was diagnosed for half an hour while the old one was running.

### 2.6 GPIO Assignment

**Reconciled 2026-09-18, CARD-0303 — this list and root `CLAUDE.md`'s separate list had genuinely diverged, not just restated each other.** `CLAUDE.md` excluded GPIO25/26 (DAC) and the strapping pins GPIO2/12/15, none of which this section mentioned; this section excluded GPIO1/3 (UART0/USB), which `CLAUDE.md` didn't mention. Someone consulting only one list had no warning from the other's findings. Merged into one complete, correct exclusion list — this section is now the single source; `CLAUDE.md` points here.

Before assigning GPIOs, exclude the following on ESP32 DevKitC-32 38-pin:
- **GPIO0, GPIO2, GPIO12, GPIO15** — strapping pins, affect boot mode if driven at reset
- **GPIO1, GPIO3** — UART0 / USB
- **GPIO6–11** — internal flash, never use
- **GPIO25, GPIO26** — DAC1/DAC2. GPIO25 confirmed broken for digital output in the ESPHome/Arduino framework (post-boot DAC init reconfigures the pin) — avoid both as a precaution.
- **GPIO34, GPIO35, GPIO36, GPIO39** — input only, cannot drive output

**Known-safe for digital output** (from real use across this project's components): GPIO18, GPIO19, GPIO21, GPIO22, GPIO23, GPIO27, GPIO32, GPIO33.

Document all GPIO assignments in the Hardware Context table of the instruction set. Note the pin label orientation issue: ESP32 DevKit pin labels face down when inserted in a breadboard. Mark key GPIO rows with masking tape before wiring. A pinout PNG should be placed in the component directory for reference.

### 2.7 ESPHome MQTT Publishing Patterns

These patterns are derived from garage-radar and front-porch-temp-sensor — the two reference implementations. Always diff one of those YAMLs before writing MQTT publish code in a new component.

**Rule: never use `id(mqtt_client).publish()` inside a raw lambda for anything other than the SPIFFS replay loop (see §2.10).** Use native `mqtt.publish` actions instead. Raw lambda publishes in `on_connect` are silently dropped before the broker session is fully ready. Native actions are queued correctly by ESPHome.

**`on_connect` pattern:**
```yaml
on_connect:
  - delay: 500ms
  - mqtt.publish:
      topic: jctsh/<type>/<component>/log
      payload: !lambda |-
        char buf[256];
        snprintf(buf, sizeof(buf),
          "{\"component\":\"<name>\",\"category\":\"System\","
          "\"message\":\"<Name> online - ESPHome " ESPHOME_VERSION ", IP: %s\"}",
          id(wifi_ip).state.c_str());
        return std::string(buf);
  - mqtt.publish:
      topic: jctsh/<type>/<component>/log
      payload: '{"component":"<name>","category":"MQTT","message":"MQTT connected"}'
```

The `delay: 500ms` gives the broker session time to fully settle before publishing. The `wifi_info` text sensor (`id: wifi_ip`, `internal: true`) must be declared for the IP lambda.

**Heartbeat pattern (home-mode-only guard):**

For components that have a field mode (no WiFi), wrap heartbeat publishes in a `condition` so they are suppressed when MQTT is not connected:
```yaml
- interval: 30min
  then:
    - if:
        condition:
          lambda: 'return id(mqtt_client).is_connected();'
        then:
          - mqtt.publish:
              topic: jctsh/<type>/<component>/log
              payload: !lambda |-
                # ... build heartbeat log message ...
                return std::string(buf);
          - mqtt.publish:
              topic: jctsh/<type>/<component>/heartbeat
              payload: !lambda |-
                # ... build heartbeat payload ...
                return std::string(buf);
```

For components that are always home (garage-radar, front-porch), the `if` guard is not needed — the interval fires without a condition check. The `mqtt_client` `id:` must be declared on the `mqtt:` component block for `is_connected()` to be callable.

**Reference implementations:** `components/garage-radar/garage-radar.yaml`, `components/front-porch-temp-sensor/front-porch-temp-sensor.yaml`

---

### 2.8 ESPHome Component Boilerplate

Every new ESPHome component uses this exact boilerplate. Do not deviate without a documented reason.

**Board and framework:**
```yaml
esp32:
  board: esp32dev
  framework:
    type: arduino
```

**Logger:** Always `INFO`. Debug and verbose levels produce excessive serial output that obscures real issues.
```yaml
logger:
  level: INFO
```

**captive_portal:** Always include. Allows browser-based recovery when WiFi credentials are wrong.
```yaml
captive_portal:
```

**Exception — deep sleep components:** Do NOT include `captive_portal:` when the component uses `deep_sleep:`. ESPHome's captive portal calls `App.prevent_deep_sleep()` internally, which permanently blocks sleep entry for the entire boot cycle. Omit `captive_portal:` and add a YAML comment documenting why:
```yaml
# captive_portal removed — calls App.prevent_deep_sleep() and blocks deep sleep entry
```

**WiFi AP fallback:** Name the fallback AP `<component-name>-fallback`. Makes it identifiable on the network if the device can't reach JCTnet1.

**Single-network (home-only components):**
```yaml
wifi:
  ssid: !secret wifi_ssid
  password: !secret wifi_password
  ap:
    ssid: "<component-name>-fallback"
    password: !secret ap_password
```

**Multi-network variant (portable components — home WiFi + cellular hotspot):** Use the `networks:` list syntax. ESPHome tries networks in list order at boot — put home WiFi first so it takes priority when at home:
```yaml
wifi:
  networks:
    - ssid: !secret wifi_ssid
      password: !secret wifi_password
    - ssid: !secret hotspot_ssid
      password: !secret hotspot_password
  ap:
    ssid: "<component-name>-fallback"
    password: !secret ap_password
```

Add `hotspot_ssid` and `hotspot_password` to `secrets.yaml` and `secrets.yaml.template` when using this variant. The hotspot SSID and password are fixed at flash time — changing them after flashing requires a re-flash.

**Hotspot SSID naming:** Use a device-independent name (e.g., `JCT Hotspot`) rather than a phone model name (e.g., `JCT Pixel 10 Pro XL`). A device-independent name means any phone can serve as the hotspot by matching the SSID and password — no re-flash needed to switch devices.

**Component naming:** The ESPHome `name:` field determines the device hostname (`<name>.local`) and the ESPHome auto-generated MQTT sub-topics. It must match the component name used in the MQTT topic prefix. All three must be consistent:
- `esphome: name: hiking-monitor` → hostname `hiking-monitor.local`
- `mqtt: topic_prefix: jctsh/components/hiking-monitor`
- Log messages: `"component": "hiking-monitor"`

**Flash path:** ESPHome must be run from `C:\esphome\<component-name>\`. Spaces in `JCT Documents` break the ESP-IDF compiler mid-build with no useful error. Copy `<name>.yaml`, `secrets.yaml`, and any custom headers to that directory before every flash. Do not run `esphome` from inside the repo path.

---

### 2.9 Sensor Coding Standards

**NaN guards:** Always check `isnan()` before using sensor values in lambdas. BME280, LTR-390, and other I2C sensors return NaN on the first read cycle while they initialize. Publishing NaN produces malformed JSON and can crash the log server parser.

```cpp
float temp = id(bme_temp).state;
if (isnan(temp)) {
  // skip or use fallback
}
```

**Standard I2C pins:** Use GPIO21 (SDA) and GPIO22 (SCL) for all I2C buses. This is the consistent choice across all JCTsh I2C components. Only deviate if a GPIO conflict forces it, and document the reason.

**Internal sensors:** Mark housekeeping sensors `internal: true` to suppress automatic MQTT publishing. These sensors are used in lambdas only — their values should not appear as independent MQTT topics.

```yaml
- platform: uptime
  id: uptime_sec
  internal: true

- platform: wifi_signal
  id: wifi_rssi
  internal: true
  update_interval: 60s

# Required for IP address in on_connect message:
text_sensor:
  - platform: wifi_info
    ip_address:
      id: wifi_ip
      internal: true
```

All three of these sensors are required in every component that publishes a heartbeat or an on_connect log message.

---

### 2.10 Onboard Flash Logging (Field Mode)

For components that log sensor readings to flash when WiFi is unavailable, use **ESP-IDF native SPIFFS VFS** (`esp_spiffs.h`), not the Arduino LittleFS library (`LittleFS.h`).

**Why SPIFFS, not LittleFS:**
- SPIFFS is bundled with the ESP-IDF — no external library declaration or download needed
- LittleFS offers better wear-leveling and directory support, but neither matters for this use case (sequential append and read of a single `.jsonl` file)
- SPIFFS mounts reliably under the ESPHome Arduino framework and supports standard POSIX file I/O (`fopen`, `fprintf`, `fgets`, `remove`)

**Implementation pattern** (`hiking_logger.h` is the reference):
```cpp
#include <esp_spiffs.h>

esp_vfs_spiffs_conf_t conf = {
  .base_path              = "/spiffs",
  .partition_label        = NULL,   // first SPIFFS partition
  .max_files              = 5,
  .format_if_mount_failed = true,   // auto-format on first use
};
esp_vfs_spiffs_register(&conf);
```

Log file path: `/spiffs/<component>_log.jsonl` (JSON Lines — one payload object per line).

**Capacity:** The default ESPHome ESP32 partition table allocates ~1.47 MB to SPIFFS. At ~200 bytes per reading and a 2-minute interval, a 6-hour hike produces ~180 readings (~36 KB) — well within limits.

**Naming:** Name the custom header and documentation files by their function, not by the library. Use `<component>_logger.h` and `<component>-logger.md`, not `littlefs_logger.h` or `spiffs_logger.h`. The library choice is an implementation detail.

**Reference implementation:** `components/hiking-monitor/hiking_logger.h` — see `components/hiking-monitor/hiking-logger.md` for a complete description of the API, operating modes, replay flow, capacity, and troubleshooting.

---

### 2.11 MQTT Account Creation

Every new ESP32 component requires its own dedicated Mosquitto account. Create it before first flash:

```bash
sudo mosquitto_passwd -b /etc/mosquitto/passwd <component-name> <password>
sudo chown root:mosquitto /etc/mosquitto/passwd
sudo systemctl restart mosquitto
```

**Critical:** `sudo mosquitto_passwd` resets `/etc/mosquitto/passwd` group to `root`. Always run the `chown` command immediately after any password change or Mosquitto will fail to read the file.

Store the password in `components/<name>/secrets.yaml` (gitignored). Add the account name to the credentials table in CLAUDE.md.

---

### 2.12 E-ink Display Pattern

For components with an e-ink display, three rules apply:

**1. Set `update_interval: never`.** E-ink full refresh takes ~2 seconds. Letting it fire on every sensor update cycle produces constant flicker and wear. Drive it explicitly instead:
```yaml
display:
  - platform: waveshare_epaper
    update_interval: never
    full_update_every: 1
```

**2. Use a `deep_sleep_pending` global to render a shutdown screen before sleep.** The display retains its last image with power off — make it show the right thing. Set the flag, update the display, then sleep:
```yaml
globals:
  - id: deep_sleep_pending
    type: bool
    restore_value: false
    initial_value: 'false'
```
Pre-sleep sequence (in `on_connect`, `on_state`, etc.):
```yaml
- lambda: 'id(deep_sleep_pending) = true;'
- component.update: <display_id>
- deep_sleep.allow: <sleep_id>
- deep_sleep.enter: <sleep_id>
```
The display lambda checks `id(deep_sleep_pending)` first and renders a shutdown layout if true.

**3. The display lambda must handle NaN during the first read cycle.** I2C sensors return NaN while they initialize. Render an "initializing" fallback rather than printing garbage or crashing:
```cpp
if (isnan(temp) || isnan(hum) || isnan(uv)) {
  it.print(5, 10, id(font_data), "<Component name>");
  it.print(5, 72, id(font_data), "initializing");
} else {
  // normal display
}
```

**Reference implementation:** `components/hiking-monitor/hiking-monitor.yaml` display block.

---

### 2.13 Multi-priority `on_boot` Sequencing

When boot requires ordered phases with dependencies, use multiple `on_boot:` blocks with different priority values. ESPHome runs higher priorities first:

| Priority | Use |
|---|---|
| `600.0` | Early hardware setup — fires before component initialization. Use for SPIFFS mount, hardware reset, or anything that must happen before sensors start. |
| `-100.0` | First sensor reads and display update — sensors are initialized and ready. |
| `-200.0` | Conditional sleep entry — must run last so all other boot actions complete first. |

```yaml
on_boot:
  - priority: 600.0
    then:
      - lambda: 'hike_log_begin();'   # SPIFFS must mount before any sensor cycle
  - priority: -100.0
    then:
      - component.update: my_sensor   # first read on boot
      - component.update: my_display
  - priority: -200.0
    then:
      - if:
          condition:
            and:
              - binary_sensor.is_off: mode_switch
              - binary_sensor.is_off: dock_detect
          then:
            - deep_sleep.allow: deep_sleep_control
            - deep_sleep.enter: deep_sleep_control
```

Negative priorities run after all components are initialized. Any `on_boot` action that reads sensor values, updates a display, or enters sleep must use a negative priority.

**Reference implementation:** `components/hiking-monitor/hiking-monitor.yaml` `on_boot:` block (priorities 600.0, -100.0, -200.0).

---

### 2.14 Battery-Powered Component Safety Standards

Required for every component powered by a rechargeable LiPo/Li-ion cell — applied during initial build, never deferred as a future enhancement. Established after the hiking-monitor's original battery failed on its first field trip (2026-07-03) with no advance warning.

**1. Cell selection — built-in PCM protection required.** Only use cells with a Protection Circuit Module (PCM) covering overcharge, over-discharge, overcurrent, and short-circuit. Confirm this from the listing/datasheet before purchase and note it in `JCTsh-Parts-Inventory.md`. Reject bare/unprotected cells. Reference: the EEMB 603449 line in stock is PCM-protected and UN 38.3 compliant — confirmed via manufacturer documentation, not assumed.

**2. Firmware low-battery cutoff required — and it must cover every high-current WiFi-burst operation, not just continuous field/logging operation.** Watch the battery voltage sensor. Below a safe threshold (3.4V for single-cell LiPo — leaves margin above the cell's own PCM trip point and above boost-converter end-of-charge instability), force deep sleep regardless of any mode switch, and render a persistent on-screen warning if a display is present (e-ink holds the frame with zero power). Also check at boot, so waking a critically-low device shows the warning and safely re-sleeps instead of attempting normal operation. This layer exists to act *before* the cell's PCM has to trip — it gives an early, visible warning instead of a silent hard stop. **A cutoff scoped only to the continuous logging/sensing loop is not sufficient** — any discrete, high-current burst operation (a buffered-data replay over MQTT, an OTA check, anything that drives WiFi TX for more than a moment) needs the same gate, checked immediately before the burst starts, not just periodically during idle operation. Found the hard way, 2026-08-25 (CARD-0211/CARD-0212): hiking-monitor's existing cutoff protected the hike-logging loop but was deliberately skipped while docked/charging (correctly, so charging isn't interrupted) — but the docked-mode data-replay burst had no gate of its own, so a device that came home from a hot, long hike already battery-warned went straight into repeatedly attempting (and brownout-resetting through) a multi-second WiFi replay burst before the battery had recovered any headroom. Reference: `components/hiking-monitor/hiking-monitor.yaml` (`low_battery_shutdown` script).

**3. Charging safety.**
- Charge inside a fireproof LiPo charging bag (silicone-coated fiberglass, ~$10-15) — required, not optional, regardless of cell quality or PCM protection.
- Set the bag on a heat-insulating, non-combustible surface — concrete/masonry floor, ceramic tile, cement board, or a metal tray lined with sand/kitty litter. Never place it on bare sheet metal on a wooden workbench: metal conducts heat rather than blocking it, and a thermal runaway event (600°C+, sustained for several minutes) will carry straight through thin metal and scorch or ignite the wood underneath.
- Never charge unattended for extended periods (e.g. leaving to charge overnight unsupervised).
- Never charge a cell that reads 0V, shows swelling/puffiness, feels hot, or has any chemical smell. Treat as damaged and retire it — do not attempt to revive it. (This is exactly what happened with the original hiking-monitor cell.)

**4. Storage.** Cells not in active use should be stored at 40–60% charge, not full or empty. Recheck/recharge to that range roughly every 3 months during long storage — fully depleted long-term storage degrades cells even with PCM protection.

**5. Disposal.** Tape over the JST terminals before discarding a retired cell (prevents short-circuit in a bin/drawer). Recycle at a battery drop-off (Home Depot, Lowe's, Batteries Plus, etc.) — never in household trash.

**6. Connector polarity.** Verify polarity with a multimeter before the first connection of any new battery/module pairing — do not assume color convention (red = positive is common but not guaranteed on every module).

**7. Power architecture — prefer direct LiPo-to-LDO over boost-then-buck (recommended default for new builds, not a retrofit requirement).** A boost converter that steps the LiPo's native 3.0–4.2V up to ~5V, followed by the microcontroller's onboard regulator stepping it back down to 3.3V, is two conversions in opposite directions — wasted efficiency, and each stage draws its own idle current even while "asleep." Since the ESP32 and most peripherals (BME280, LTR-390, e-ink, etc.) run natively on 3.3V, default new battery-powered builds to a single low-quiescent-current LDO taking the LiPo directly to 3.3V (Adafruit Feather-style), skipping the boost stage entirely. This also removes the boost converter's end-of-charge "voltage cliff" instability — a contributing factor in the hiking-monitor's original battery incident. Only use a boost converter when a specific peripheral requires 5V. Not applied retroactively to hiking-monitor's existing perfboard — apply to the next new battery-powered component.

**8. [CANDIDATE — not yet required, pending validation] GPIO-controlled power gating for I2C/SPI peripherals during sleep.** Observed 2026-07-03: ESP32 deep sleep only stops the CPU from executing — it does not cut power to anything downstream. With no gating in place, I2C/SPI peripherals (BME280, LTR-390, etc.) stay fully powered and drawing their own operating current for the entire "sleep" duration, on top of any boost-converter quiescent draw (see point 7). Confirmed visually on hiking-monitor: the ESP32's and LTR-390's power-indicator LEDs stayed lit after the device entered deep sleep. Candidate fix: a P-FET (or similar high-side load switch) in-line on the 3.3V rail between the microcontroller's own 3.3V output and the peripherals — not between the boost module and the microcontroller's `VIN`, since the microcontroller must stay powered to control the gate signal — gated by a spare GPIO, cutting peripheral power during sleep and re-enabling it on wake. **Not promoted to a required standard yet.** CARD-0070 (which absorbed CARD-0027) partially validated this on a rig prototype — the LDO half of that card is confirmed working, but the gating half hit a persistent parts-quality issue (likely-counterfeit BS250 stock) and was **deferred 2026-08-14** without full end-to-end validation or being applied to the real field device. Real, useful findings from that work either way: the correct wiring topology (P-FET between the microcontroller's own 3.3V rail and the peripherals, not between the boost/LDO output and the microcontroller itself), and a hard-learned requirement — a gate pull-up resistor, or a floating gate can stay conductive through sleep even with the GPIO correctly driven high beforehand. Revisit this entry if a future build actually completes and measures the gating half.

**9. Regulator peak-current headroom and bulk capacitance at the point of load — required, with quantified numbers, not just a qualitative preference.** Added 2026-08-25 after the same underlying physics caused two separate same-night incidents on two different devices (CARD-0198 air-quality-monitor, CARD-0211 hiking-monitor): a WiFi TX/association current spike lands on a battery+regulator chain that only has enough headroom for the *average* draw, sagging the rail below the ESP32's brownout threshold and forcing a reset — sometimes before any code has run far enough to log what happened.

- **Why this keeps happening — the actual physics, not a design mistake:** WiFi association/TX draws current in sharp, millisecond-scale spikes, not a smooth average. This project's own real measurements: hiking-monitor's active-boot/WiFi current bounced **109-154mA continuously** on the CARD-0026 test rig (never settling), consistent with the general **100-250mA burst range** that rig's brownout-reset-loop diagnosis was built on; air-quality-monitor's SEN55 sensor draws **~63mA** in active Measurement mode, on top of whatever the ESP32/WiFi radio itself needs concurrently. A battery's own internal resistance also rises as it depletes, heats up, or ages — the *identical* hardware configuration can pass repeatedly on a fresh, cool cell and fail repeatedly on a partially-depleted or hot one (hiking-monitor's CARD-0211 incident: a battery that started the day at 4.28V, after a ~6.5 hour hike in 108-111°F heat, couldn't sustain a WiFi replay burst it would normally handle fine).
- **Size the regulator for the peak coincident load, not the average.** Sum every current-hungry thing that could plausibly be active at the same moment (WiFi TX/association + any actively-powered peripheral + baseline MCU draw), then pick a regulator (LDO or switching buck/boost) rated for **at least 2-3x that sum** — not a part that's only just barely rated for the theoretical peak. air-quality-monitor's MCP1700 (250mA rated) against a WiFi spike stacked on SEN55's ~63mA is exactly the marginal case this rule is meant to prevent; a regulator with real headroom turns "sometimes works, sometimes doesn't" into "just works."
- **Bulk capacitance at the point of load is a real, required complement — not a substitute for headroom.** A capacitor can only buffer millisecond-scale transients (a 1000µF cap holding up ~100mA from 3.3V down to the ESP32's ~2.4V brownout threshold lasts under 10ms by simple C×ΔV/I math) — it cannot manufacture sustained current a regulator can't supply, and testing this project did in 2026-08-24 confirmed a bulk cap alone did not reliably fix a case where the regulator itself was genuinely undersized. But for genuinely short WiFi-TX-scale spikes, it's real and effective. Place a few hundred µF electrolytic in parallel with a small (1-10µF) ceramic directly at the microcontroller's 3.3V/GND pins — as close to the point of load as physically possible, not just somewhere on the same rail.
- **Not a substitute for point 2's low-battery cutoff.** Even a well-headroomed regulator has limits — the firmware-side cutoff (point 2, now scoped to cover WiFi-burst operations specifically) is what protects a deeply-depleted cell regardless of how generous the regulator's rating is.

**10. Sequence current-hungry startup operations in firmware — don't let them coincide.** WiFi association and a peripheral's own power-up/active-mode current are each individually manageable; stacked on top of each other during the same boot window, they're what actually blows past the regulator's peak rating. Where firmware has control over the timing (most peripheral power-up does), hold a hungry peripheral in its lowest-current state until WiFi/MQTT has actually connected (not just "probably done by now" on a fixed delay — check the real connection state, bounded by a timeout so a device with no reachable network doesn't wait forever), then bring it to full power. Reference: `components/air-quality-monitor/air-quality-monitor.yaml`'s `on_boot` sequence — SEN55 is forced into ~2.6mA Idle mode as the first `on_boot` action, before the reset-reason LED check even runs, and only resumes full ~63mA Measurement mode once `mqtt_client.is_connected()` is confirmed (bounded to 30s). This pattern alone wasn't sufficient to fully solve CARD-0198 (point 9's regulator-headroom rule is what closes the remaining gap), but it's still a real, required piece of the overall mitigation, not optional once a peripheral's active-mode draw is non-trivial.

**11. A field device that buffers data for later upload must never attempt WiFi while actively collecting — only once its own session-over signal says so, never just because a charging/dock signal went high.** Added 2026-08-27 after hiking-monitor's real reset storm (CARD-0217) and the closely-related CARD-0045 finding, both traced to the same root design mistake: nothing was ever telling the WiFi radio to stay off during field/collection mode, so it kept retrying continuously — burning current for zero benefit (nothing reachable out in the field) and, once battery voltage got low enough under heat, triggering repeated brownout resets. A charging/dock signal (`dock_detect`-style, USB or solar sharing the same pads) is **not** a valid proxy for "safe or useful to try networking now" — solar in particular is used specifically for extended time away from any network, so it correlates with *worse* connectivity, not better. The correct, simple rule: WiFi only re-enables once the device's own explicit "this collection session is over" signal fires (a mode switch turned off, an equivalent state transition) — never merely because power got connected while still actively collecting. This is deliberately simpler than an earlier-considered alternative (a bounded WiFi attempt window with periodic retry while charging) — that design still tries to guess at "maybe a network is reachable now," when the honest answer during active collection is that trying is never justified, so there's nothing to bound or retry. **Applying this to a device without a readable mode signal isn't automatic — check first, don't assume one exists.** Confirmed while checking this against air-quality-monitor's own not-yet-built Step 8 (CARD-0218): that device was deliberately designed "dock-detect-only for firmware mode-switching... no GPIO-based manual mode switch" (its inline power switch is wired directly into the battery path, unreadable by firmware) — meaning it had *no* signal to distinguish a genuine end-of-session from solar connecting mid-session. **Resolved the same day, same card** — see point 12 below for the fix (a repurposed switch now serves as a real Intent signal). Reference: `components/hiking-monitor/hiking-monitor.yaml` (`dock_detect`'s `on_state` handler, gated on `binary_sensor.is_off: slide_switch`), `components/hiking-monitor/operations.md` (the corrected operational rule), CARD-0045, CARD-0217, CARD-0218.

**12. Three independent signals are required for any battery-powered field device that collects data now and syncs later — Intent, Power Connected, Power Switch — never let one stand in for another.** Added 2026-08-27, the hardware-design framework underneath point 11's firmware rule. Defined:

- **Intent** — is the device actively collecting field data right now, or is it idle/ready-to-upload? A deliberate, user-set declaration (a physical switch position, an explicit mode command) — never inferred from anything else. Point 11's whole rule depends on this signal existing and being independently trustworthy.
- **Power Connected** — is external charging current present right now (USB or solar)? A pure power-supply fact. Says nothing about intent, and nothing about whether the device is done collecting.
- **Power Switch** — can the device reach a genuine zero-draw off state (for storage/transport/shipping), not just its lowest *operating* power mode?

These three are orthogonal by nature — real, independent facts that vary in any combination (actively collecting *and* charging via solar mid-hike; done collecting *and* not yet charging, waiting to be docked later). Conflating any two of them — using one as a stand-in for another because it usually happens to correlate — is the exact root cause behind every bug this session found: hiking-monitor's real reset storm (CARD-0217) and CARD-0045 both came from inferring "safe to try WiFi" (an Intent-gated decision) from Power Connected instead of a real Intent signal.

**A real audit of both existing field devices, 2026-08-27 — neither has all three, independently, and each is missing a different one:**
- **hiking-monitor** has Intent (slide switch, GPIO27) and Power Connected (`dock_detect`, GPIO32) cleanly separated — correctly designed, which is exactly why CARD-0045/CARD-0217's firmware fix could be applied cleanly once found. But it has **no real Power Switch** — per `operations.md`, "VOUT+ runs directly to ESP32 VIN — the switch is not in the power path"; the slide switch is pure Intent, and the only true off state is physically disconnecting the LiPo's JST connector, which requires opening the sealed enclosure. Tracked as **CARD-0181** (Defer).
- **air-quality-monitor** had a real Power Switch (an inline cutoff wired directly into the battery path — genuine true-off, unlike hiking-monitor) and Power Connected (`dock_detect`), but **no Intent signal at all** — its 2026-08-19 design decision built mode-switching entirely around `dock_detect`, conflating Power Connected with Intent from the start. Surfaced and resolved same-day, 2026-08-27 (**CARD-0218**), while correcting Step 8's design to match point 11: since this device's existing switch (Gebildet SS12D10, slide type) was already occupying the Power Switch role, the fix is the mirror image of hiking-monitor's — that switch is repurposed as the real, GPIO-readable **Intent** signal (GPIO27, same pin/pattern as hiking-monitor's own), and Power Switch gets a new, genuinely distinct part instead (a BK-1208 latching push button, the same part chosen for hiking-monitor's own CARD-0181 gap — one order covers both devices). Design decided and documented (`air-quality-monitor-claude-code-instructions.md`), not yet physically rewired on the breadboard or ordered.

**Required for every new field-and-later-upload device going forward:** design and wire all three signals independently and explicitly from the start, even when two of them seem to move together in the common case during early bring-up. The failure mode only shows up once they genuinely diverge (solar connecting mid-session, a device left disconnected a while) — easy to miss in initial testing, expensive to find later (a real multi-hour field incident, not a bench test).

**13. The complete data-flow model for a field-and-later-upload device is three distinct steps, not one — collecting, attempting, and succeeding are separate states with separate gates.** Added 2026-08-29, clarifying the full picture behind point 11's rule.

- **Step 1 — the attempt gate is an AND, not either signal alone: Intent off *and* Power Connected both required.** Power Connected is the literal trigger — nothing is attempted until it goes HIGH — but it is not *sufficient* by itself (that was the point 11 bug). Intent-off is the second, independently-required condition added on top of it. Neither replaces the other; both must hold.
- **"Power Connected" is deliberately broader than the word "docked" suggests — don't let the word narrow the mental model.** The signal is defined purely electrically (voltage present on the charging input) and fires identically whether that power came from the home charging dock, a solar panel, or a field USB power bank. This breadth is intentional, not incidental — it's what lets a device reach WiFi from a solar-charged trailside stop, not just at home. Referring to this condition as "docked" in design discussion risks quietly reintroducing the assumption it only applies at home, which is the exact class of mistake point 11 exists to prevent.
- **Step 2 — meeting the attempt gate starts a bounded attempt, not a guaranteed upload.** The device tries for a bounded window, then backs off and retries periodically for as long as both gate conditions still hold, rather than either trying indefinitely or giving up permanently on one failure. (Reference implementation: `air-quality-monitor.yaml`'s Timeout policy — ~2 minute attempt window, ~15-20 minute retry interval; treat the *pattern* as the requirement, not these exact numbers for every device.)
- **Step 3 — the actual upload/replay only begins once WiFi *and* MQTT both succeed** — a separate, later condition from "the attempt gate was met." A device can be Intent-off and Power-Connected for a long stretch with no network in range and never upload anything, which is expected, not a fault. Once connected, this is also when a periodic heartbeat (5 min, both current field devices) starts publishing alongside the actual data replay.
- **Whether field-mode logging itself keeps running while Power Connected is HIGH is a separate design choice, not dictated by this point.** hiking-monitor stops field logging the instant Power Connected goes HIGH; air-quality-monitor runs it unconditionally regardless of Power Connected state, specifically because solar/field-USB made "connected" no longer synonymous with "session is over." Either is valid — decide deliberately per device rather than copying the other's choice by default.

---

## 3. MQTT Standards

### 3.1 Topic Naming Convention

```
jctsh/<type>/<component>/<message-type>
```

Examples:
- `jctsh/components/garage-radar/state` — primary state
- `jctsh/components/garage-radar/log` — log messages (routed to Python log server by Node-RED)
- `jctsh/components/garage-radar/heartbeat` — 30-minute heartbeat (monitored by Node-RED watchdog)
- `jctsh/sensors/salt-sensor/data` — sensor readings

### 3.2 Standard Sub-Topics

For ESP32 components, the following sub-topics are standard:
- `/state` — primary on/off or presence state
- `/log` — all log messages in standard JSON format (see Section 4.2)
- `/heartbeat` — 30-minute heartbeat in standard JSON format (see Section 4.1)
- Additional sub-topics named for the specific sensor value (e.g. `/still`, `/moving`, `/distance`, `/level`)

### 3.3 Broker

Mosquitto broker on `pi1.local`, port 1883. Fixed IP: `192.168.1.117` (use if `.local` resolution fails). Tailscale IP: `100.70.162.24` (use for remote access). Reference by hostname in configuration files.

**For components that connect from outside the home network** (e.g., via a cellular hotspot): use `jctsh.duckdns.org` as `mqtt_broker` in `secrets.yaml`. `pi1.local` is mDNS link-local and unreachable from cellular; `192.168.1.117` and `100.70.162.24` are likewise unreachable from cellular. DuckDNS + router port forward (port 1883 → 192.168.1.117) is the only path. See `core/mqtt/monitoring.md` for the full infrastructure setup and layer-by-layer monitoring commands.

### 3.4 Will Message

Every ESP32 component configures an MQTT Last Will and Testament (LWT). The broker publishes it automatically when the device disconnects unexpectedly. This is how `"MQTT disconnected"` appears in the log dashboard without the device sending it.

Required pattern — no deviations:
```yaml
will_message:
  topic: jctsh/<type>/<component>/log
  payload: '{"component":"<name>","category":"MQTT","message":"MQTT disconnected"}'
  retain: false
  qos: 0
```

`retain: false` is critical. A retained will message would re-appear in the log every time a new subscriber connects to the broker, producing phantom "disconnected" entries long after the device is back online.

### 3.5 MQTT Discovery

Set `discovery:` based on whether the component has Home Assistant integration:

| HA integration? | Setting |
|---|---|
| Yes (entities visible in HA) | `discovery: true` + `discovery_prefix: homeassistant` |
| No (MQTT only, no HA entities) | `discovery: false` |

Do not leave `discovery:` at its ESPHome default (`true`) for components that have no HA integration. Auto-discovery would create unwanted HA entities for every sensor value the device publishes.

**Cross-device unique_id collisions — check this before naming any discovered entity.** ESPHome's default `discovery_unique_id_generator: legacy` derives an entity's MQTT discovery `unique_id` from its type and *display name alone* (e.g. a button named "Restart" becomes `ESPbuttonrestart` on every device that has one) — not from the device's own identity. Two devices with an identically-named entity silently collide: HA keeps whichever one registered first and drops the other with no visible error to the user (only a `logger.error` line: `"ID ... already exists - ignoring ..."`). This is exactly how hiking-monitor's, front-porch-temp-sensor's, and salt-sensor's restart buttons collided with each other (CARD-0180/CARD-0186) — salt-sensor's had never worked in HA at all, unnoticed until directly investigated.

Before adding any discovered entity, grep the other components' YAML for the same generic entity name (`"Restart"`, `"Status"`, etc.) to check for a collision. Two fix patterns, pick based on blast radius:
- **Device exposes only that one entity to HA** (everything else `internal: true`) — set `discovery_unique_id_generator: mac` on the device's `mqtt:` block. Safe because it's the only entity whose id changes.
- **Device exposes multiple live entities to HA** — do *not* flip the generator; it regenerates every entity's unique_id on that device at once, orphaning existing HA registrations (history, dashboard references, automations) for entities that were never part of the problem. Instead give just the colliding entity a device-specific `name:` so the existing legacy generator naturally produces a distinct id.

Either fix path leaves a stale retained discovery topic behind (the old topic keeps publishing the old, collided config). Clear it explicitly — `mosquitto_pub -t '<old discovery topic>' -n -r` — or HA will show a duplicate/orphaned entity alongside the fixed one. Also avoid baking the device's own name into an entity's `name:` as the "device-specific" fix (e.g. naming a button "Salt Sensor Restart" on the salt-sensor device) — HA concatenates device name + entity name for the default entity_id/friendly name, so this produces a doubled, awkward result (`button.salt_sensor_salt_sensor_restart`). Prefer a name that's distinct without repeating the device name, or accept the cosmetic duplication and rename the entity_id manually in HA afterward.

### 3.6 Field-mode Sentinel — `rssi_dbm: 0`

For portable environmental sensors that log readings to SPIFFS when WiFi is unavailable, include `rssi_dbm` in every data payload:

- When MQTT-connected: set to the actual WiFi RSSI (negative integer, e.g. `-45`)
- When logging to SPIFFS in field mode (no WiFi): set to `0`

```cpp
int rssi = id(mqtt_client).is_connected() ? (int)id(wifi_rssi).state : 0;
// include rssi in the JSON payload
```

This convention lets downstream processors distinguish reading types:
- `rssi_dbm == 0` → field-mode reading; `ts` is the actual hike timestamp
- `rssi_dbm != 0` → home-mode reading; `ts` is live capture or replay-upload time

Node-RED can detect field session boundaries using the `rssi_dbm` transition: nonzero → zero = field session started; zero → nonzero = field session ended. The `lastTs` at the transition is the precise start/end timestamp from the sensor payload.

**Reference implementation:** `components/hiking-monitor/hiking-hike-events.flow.json` (`Detect field session start / end` function node).

---

## 4. Observability Standards

Observability is **not optional**. Every ESP32 component implements message logging and heartbeat, and is registered with the Node-RED watchdog flow. These are required in the initial build — not features to be added later.

### 4.1 Heartbeat

All ESP32 components publish a heartbeat every **30 minutes** to two topics:

> **Rationale:** The Node-RED watchdog timeout is 35 minutes (30-minute interval + 5-minute buffer). 30 minutes is the standard because it is derived from the watchdog — not arbitrary. Battery-powered components may use a longer interval; document the reason and accept that the watchdog may not catch them reliably.

**Log topic** (visible in dashboard):
```
topic: jctsh/<type>/<component>/log
payload: { "component": "<name>", "category": "System", "message": "Heartbeat - uptime: Xh Xm, RSSI: -XXdBm, <state-key>: <value>" }
```

**Heartbeat topic** (monitored by Node-RED watchdog):
```
topic: jctsh/<type>/<component>/heartbeat
payload: { "component": "<name>", "uptime": "Xh Xm", "rssi": -XX, "<state-key>": "<value>" }
```

Both are published on the same 30-minute interval. The log topic entry makes the heartbeat visible in the dashboard. The heartbeat topic is what the Node-RED watchdog monitors.

**Boot-time heartbeat (required — CARD-0333, 2026-09-24).** The 30-minute interval counts from *boot*, so on its own the first heartbeat after a reboot arrives ~30 minutes after boot — up to ~60 minutes after the previous one, past the 35-minute watchdog timeout. Any reboot (OTA, power cycle, restart button) that lands more than ~5 minutes after a heartbeat therefore raises a false `silent for 35 minutes` alert, which teaches everyone that silence alerts are noise. **Applicability:** the false alert needs the worst-case gap — 2 × the heartbeat interval, plus the reboot's downtime — to exceed the 35-minute timeout, i.e. a heartbeat interval above roughly 15 minutes. Components on the standard 30-minute heartbeat therefore **also send one heartbeat shortly after each boot**. Components on a 5-minute heartbeat (`hiking-monitor`, `air-quality-monitor`) cannot hit it and are exempt; systemd-timer heartbeats already do this (`OnBootSec=2min` in `photo-server`'s and `p-w-firefly`'s timers). The boot heartbeat has three conditions:

1. **After the first valid sensor reading.** Delay at least the longest poll interval plus a margin (reference build: 90 s for 60 s polling), so the read-failed Alerts that ride on the heartbeat are meaningful instead of firing on every boot.
2. **Only once MQTT is connected** (`wait_until: mqtt.connected` after the delay). `mqtt.publish` silently drops when disconnected, and a post-boot reconnect has been observed to take ~54 s on a weak-signal device.
3. **Same guards as the regular heartbeat** — e.g. the *Heartbeat pattern (home-mode-only guard)* earlier in this document for devices with a field mode.

Implement it as **one shared script called by both the interval and the boot trigger**, so the two payloads cannot drift apart:

```yaml
esphome:
  on_boot:
    priority: -100
    then:
      - delay: 90s
      - wait_until:
          mqtt.connected:
      - script.execute: send_heartbeat

interval:
  - interval: 30min
    then:
      - script.execute: send_heartbeat

script:
  - id: send_heartbeat
    mode: single
    then:
      # the log-topic publish, the heartbeat-topic publish, and any read-failed Alerts
```

A boot loop shorter than the delay never sends one, by design. Components that deliberately use a longer interval (see the rationale above) still send the boot heartbeat. Reference implementations: `components/front-porch-temp-sensor/front-porch-temp-sensor.yaml` and `components/back-patio-temp-sensor/back-patio-temp-sensor.yaml`; retrofitting the other ESPHome components is the follow-up on CARD-0333.

> **Critical:** The log topic heartbeat message **must begin with `"Heartbeat - "`** (with a space and hyphen). The log server uses this prefix to collapse consecutive same-state heartbeats into a single dashboard row showing count and time range. Any other prefix causes each heartbeat to appear as a separate row, filling the dashboard with noise.

### 4.2 Log Message Format

All log messages are published as JSON to `jctsh/<type>/<component>/log`. Node-RED subscribes to this topic and routes messages to the Python log server at `http://pi1.local/`.

**Required format:**
```json
{ "component": "<name>", "category": "<category>", "message": "<text>" }
```

**Category guide** — each category maps to a distinct layer of the stack (merged in from root `CLAUDE.md`, CARD-0303 — the two had drifted into two separate levels of detail for the same convention):

| Category | What it covers | Examples |
|---|---|---|
| `System` | Device health and operational state | Online/boot, WiFi reconnect, heartbeat |
| `MQTT` | Transport layer — the broker connection itself | Connected, disconnected, LWT |
| `Sensor` | Physical-world data and state transitions | Presence detected/cleared, distance, salt % |
| `Alert` | Threshold crossings requiring human attention | Salt warning/critical, API failures |
| `Test` | Messages generated during test mode | Simulated readings, test mode on/off |

The dividing line between `System` and `MQTT`: if the message is about the *device* (booted, alive, WiFi), use `System`. If it's specifically about the *broker connection* (connected, disconnected, subscribed), use `MQTT`.

**Do not include timestamps** — the log server adds them on receipt.

**Event-time convention (merged in from root `CLAUDE.md`, CARD-0303 — previously only stated there, missing here entirely).** Since the log server timestamps every message by receipt time, a message describing something that happened at a *different* time than when it's posted must include that actual event time in the message text itself — otherwise the dashboard timestamp silently misrepresents when the thing actually happened. This applies any time a component relays/re-reports an event from another system's own history rather than reporting something happening live (e.g., CARD-0078's NetAlertX relay, which can post about a device's original connection time well after the fact — the relayed message must say when the device actually connected, not just rely on the post time).

### 4.3 Standard Log Events

Every ESP32 component logs the following events:

| Event | Category | Message format |
|---|---|---|
| Boot | System | `<Component name> online - ESPHome vX.X.X, IP: x.x.x.x` |
| MQTT connected | MQTT | `MQTT connected` |
| MQTT disconnected | MQTT | `MQTT disconnected` (sent by broker as LWT — not by device) |
| Primary state ON | Sensor | `<State name> detected - <key>: ON (<detail>)` |
| Primary state OFF | Sensor | `<State name> cleared - <key>: OFF, timeout elapsed` |
| Heartbeat | System | `Heartbeat - uptime: Xh Xm, RSSI: -XXdBm, <state-key>: <value>` |
| OTA started | System | Handled natively by ESPHome |
| OTA completed | System | Handled natively by ESPHome |

### 4.4 Node-RED Watchdog Flow

The JCTsh watchdog is a Node-RED flow that monitors the heartbeat topic of each registered ESP32 component. It alerts Joseph via the Home Assistant companion app on his Pixel 10 Pro if a component goes silent.

**This is a JCTsh infrastructure component**, first built as part of the garage-radar project. It lives at `core/node-red/watchdog.flow.json`.

**How it works:**
- Subscribes to `jctsh/+/+/heartbeat` (wildcard — catches all component heartbeats)
- On each received heartbeat, resets a per-component timer
- If a timer expires (no heartbeat received within 35 minutes for a 30-minute interval), fires an alert
- Alert path: Node-RED → HA REST API (port 8123) → HA companion app → Joseph's Pixel 10 Pro
- Alert message format: `JCTsh alert: <component-name> has not reported in <N> minutes`

**When adding a new component:**
- No registration step required — the wildcard subscription catches all `/heartbeat` topics automatically
- Confirm the new component's heartbeat topic matches `jctsh/<type>/<name>/heartbeat`
- Confirm the heartbeat is publishing before considering observability complete

**Salt sensor retrofit:** The salt sensor (Arduino C++) will need a heartbeat added to its sketch to benefit from the watchdog. This is a separate future task — do not block new components on it.

### 4.5 Message Logging Integration

Node-RED already subscribes to `jctsh/+/+/log` (wildcard) and routes all matching messages to the Python log server. No per-component Node-RED changes are needed for logging — publish to the `/log` topic in the correct JSON format and it appears in the dashboard automatically.

Verify logging is working by checking `http://pi1.local/` (Basic Auth, user: `jctsh`) after first flash.

### 4.6 Sensor Health Detection

ESPHome components with **I2C or SPI sensors** must publish explicit error log messages when a sensor read fails (returns NaN). This makes hardware faults visible in the dashboard instead of silently showing stale retained MQTT values in HA.

**When to apply:** Any component where a physical sensor failure would cause `sensor.state` to return NaN — typically BME280, BH1750, LTR390, and similar I2C/SPI sensor platforms.

**Pattern:** Add one `if` block per sensor at the end of the 30-minute heartbeat interval, after the heartbeat publishes:

```yaml
      - if:
          condition:
            lambda: 'return isnan(id(<sensor_id>).state);'
          then:
            - mqtt.publish:
                topic: jctsh/<type>/<component>/log
                payload: '{"component":"<name>","category":"Sensor","message":"<SensorName> read failed — check I2C wiring (SDA GPIO<X> / SCL GPIO<Y>)"}'
```

**Reference implementation:** `components/front-porch-temp-sensor/front-porch-temp-sensor.yaml` — checks `bme280_temp` and `bh1750_lux`, publishes under category `Sensor`.

**Rules:**
- One `if` block per sensor ID — do not combine into a single message
- Category must be `Sensor` (not `System`) so it appears as a distinct row type in the dashboard
- Message must name the specific sensor and the GPIO pins, not just "sensor error"
- Check is run every 5 minutes — if the sensor recovers, the error stops appearing automatically

**Backlog:** hiking-monitor has BME280 (`bme_temp`) and LTR390 (`ltr_uv_index`) — both need this pattern added. See `components/hiking-monitor/hiking-monitor-claude-code-instructions.md`.

---

## 5. SmartThings Integration Standards

**Superseded for new components by §6.4 (CARD-0164, found as a real internal contradiction during CARD-0303) — SmartThings is no longer the default destination.** This section's mechanics (device type selection, integration path) still apply *when* SmartThings is genuinely the right target per §6.4's decision order (native HA integration, then Matter, then SmartThings only if neither applies) — but this section's own opening line below ("every component... is exposed in SmartThings... not deferred") predates that policy and directly contradicts it. Treat §6.4 as authoritative on *whether* to use SmartThings; this section on *how*, once that's already decided.

~~Every JCTsh component that produces actionable state is exposed in SmartThings. Determine the SmartThings device type during Phase 3 — not deferred.~~ **(Superseded by §6.4 — kept struck through, not deleted, so the contradiction this card found stays visible rather than silently vanishing.)**

### 5.1 Device Type Selection

| Use case | SmartThings device type | Notes |
|---|---|---|
| Presence / occupancy (is someone there?) | Motion Sensor | Active/Inactive — most natural fit for room presence |
| Simple on/off state consistent with existing virtual switches | Virtual Switch | On/Off — use when consistency with existing components matters |
| Door, window, or physical open/close state | Contact Sensor | Open/Closed |
| Person associated with a location (arrival/departure) | Presence Sensor | Present/Not Present — for person-tracking, not room sensors |
| Environmental reading (temp, humidity, level) | Use appropriate SmartThings capability | Match to the sensor type |

### 5.2 Integration Path

The only integration path to SmartThings is via Home Assistant:

```
Node-RED → HA REST API (port 8123) → SmartThings integration → SmartThings device
```

There is no direct MQTT-to-SmartThings path. Do not attempt to create one.

**Pattern:**
1. Create a virtual switch (or appropriate device type) in SmartThings
2. Expose it as an HA entity — HA syncs it to SmartThings automatically
3. Control it from Node-RED via the HA REST API

**Reference implementation:** The salt sensor switches (`switch.salt_critical_alert`, `switch.salt_low_alert`, etc.) are the established pattern. Examine `components/salt-sensor/` before writing any new SmartThings integration.

### 5.3 HA REST API

Node-RED calls HA at `http://pi1.local:8123/`. The HA long-lived access token is stored in Node-RED credentials (not in source control). Do not hardcode the token.

---

## 5.4 Node-RED Flow Deployment Patterns

Lessons from the hiking-monitor environmental data pipeline (2026-06-04):

**Do not inject flows directly into `flows.json` via Python/SSH.** The correct method is Node-RED UI → Import → Clipboard. Direct injection has subtle failure modes that the UI avoids.

**Every node must have a `z` property pointing to a tab node.** Nodes without `z` are orphaned — they load silently but never execute. Always include a `type: "tab"` node in the flow JSON and set `z` on every other node to match its `id`.

**The JCTsh broker (Mosquitto 2.0.21) runs MQTT v5.** The Node-RED broker config node uses `protocolVersion: 5`. Node-RED v4 UI imports generate MQTT v5 fields (`nl`, `rap`, `respTopic`, `contentType`, etc.) — these are now correct and do not need cleanup. ESP32/ESPHome devices and HA remain on MQTT v3.1.1; Mosquitto accepts both simultaneously.

**Google Apps Script returns 405 on redirect — treat it as success.** When Node-RED POSTs to an Apps Script web app URL, Google executes the script and appends the row, then returns a 302 redirect. Node-RED follows the redirect with POST; the redirect destination returns 405 (Method Not Allowed). The row WAS appended. The check response function must treat `statusCode === 405` as success, not as an error.

**Apps Script API keys must be alphanumeric.** Special characters (`&`, `@`, `*`) in URL query parameters break parsing even with `encodeURIComponent`. Generate keys using only `[a-zA-Z0-9]`.

**Node-RED env vars via systemd EnvironmentFile.** The Node-RED service on the Pi reads `/home/pi/.node-red/environment` via `EnvironmentFile=` in the systemd unit. Add `KEY=value` lines to this file for secrets passed to function nodes via `env.get('KEY')`. Restart Node-RED after editing.

**A single-output Function node returning multiple messages needs a doubly-nested array — a flat array silently drops everything but the first message.** `return [msg1, msg2, msg3]` from a node with **one** output tells Node-RED "route `msg1` to output 1, `msg2` to output 2, `msg3` to output 3" — with only one real output wired, `msg2`/`msg3` are sent to output ports that don't exist and are silently discarded, no error anywhere. To send multiple messages out a single output, nest one more level: `return [[msg1, msg2, msg3]]`. Found in CARD-0261 (2026-09-12): `salt-sensor.flow.json`'s "Build HA poll requests" node had exactly this bug since it was originally written — only the first of its 4 polled entities (`salt_test_mode`) was ever actually checked; the other 3 (`salt_full_reset`, and the two calibration `input_number`s) were silently dropped every single poll, for the life of the component, until a live end-to-end test of the reset path finally surfaced it. Both the failure mode and its correctness are invisible from the outside — check a Function node's actual configured output count (visible on the canvas as the number of connector dots on its right edge) before writing `return [...]` with more than one message, whenever there's only one wire out.

---

### 5.5 GPS Timestamp Lookup Pattern

For body-worn environmental sensors that need GPS coordinates without GPS hardware on the ESP32: use the GPSLogger → Google Apps Script → GPS Track sheet pipeline.

**Architecture:**
```
Pixel (GPSLogger app)
    │  GET every 30 seconds while hiking
    ▼
Google Apps Script  action=gps
    │  append one row (timestamp, lat, lon, accuracy_m, altitude_m)
    ▼
"GPS Track" sheet in workbook

          ↕  (on SPIFFS replay)

Node-RED wildcard data handler
    │  GET action=lookup&ts=<sensor_ts>
    ▼
Google Apps Script  action=lookup
    │  nearest trackpoint within ±5 minutes
    ▼
lat/lon populated in Environmental Data sheet
```

**Key implementation details:**
- GPSLogger's `%TIME` placeholder is a Unix epoch integer (seconds, not milliseconds). The Apps Script converts it to ISO 8601 UTC before writing to the sheet.
- Lookup tolerance is ±5 minutes. This covers the worst case: 2-minute sensor interval with 30-second GPS interval means the nearest GPS point is always within 1 minute when hiking. The 5-minute window also tolerates brief GPS signal loss.
- Home-mode readings (rssi_dbm ≠ 0) always return `{lat: null, lon: null}` — no GPS track exists for home timestamps. This is correct behavior, not an error.
- No port forwarding needed. GPSLogger posts directly to Google over cellular — the Pi is not involved in GPS logging.

**Apps Script note:** The lookup function is in the same `doGet(e)` handler as any other GET actions. Add it alongside existing actions without replacing them.

**Reference:** `components/hiking-monitor/gps-pipeline.md`, `core/data-pipeline/environmental-data.gs`

---

### 5.6 Node-RED Per-Component Context Isolation

When a Node-RED function node handles multiple components via a wildcard subscription (e.g., `jctsh/components/+/data`), use the component name as a key suffix in `context.get/set` to prevent state from leaking between components:

```javascript
var component = msg.payload.component;

// Read per-component state (undefined on first message from this component)
var lastRssi = context.get('lastRssi_' + component);
var lastTs   = context.get('lastTs_'   + component) || '';

// Write per-component state
context.set('lastRssi_' + component, rssi);
context.set('lastTs_'   + component, ts);

// Initialize cleanly on first message — don't process a state transition yet
if (lastRssi === undefined) return null;
```

New components are picked up automatically by the wildcard subscription and get their own isolated context slots with no code changes. This pattern scales to any number of components.

**Important:** Node-RED in-memory context is cleared on service restart (`sudo systemctl restart nodered`). If you need to reset stale per-component state (e.g., after a long offline period), a restart is the cleanest method.

**Reference:** `components/hiking-monitor/hiking-hike-events.flow.json`, `Detect field session start / end` function node.

### 5.7 Exposing a Sensor (Not a Switch) to SmartThings

Merged in from root `CLAUDE.md`, CARD-0303 — previously only stated there. To expose a sensor (e.g. a motion sensor) rather than a switch, use HA's own SmartThings integration's entity-exposure feature (Settings → Devices & Services → SmartThings → Configure) to push the existing HA entity to SmartThings directly. No virtual device and no SmartThings PAT required — simpler than the virtual-switch pattern in §5.2, which is for state HA needs to *push* into SmartThings rather than an entity SmartThings can read directly.

---

## 6. Integration Standards

### 6.1 Additive First

Moved to `tos/JCTsh-Operating-System.md`'s Engineering Discipline section (CARD-0289 follow-on) — the underlying rule isn't hardware-specific. Applied here: when integrating a new component alongside existing ones, wire it in parallel — do not replace inputs, automations, or integrations without an explicit decision documented in the instruction set.

### 6.2 Timeout and Timer Logic

Document where timeout/timer logic lives for every component. The three options are:

- **ESPHome** — sensor-level smoothing (short timeouts, e.g. 30 seconds). Changes require a firmware reflash.
- **Node-RED** — flow-level logic. Changes made in Node-RED UI without reflashing.
- **Home Assistant** — automation-level logic. Changes made in HA UI without reflashing.

When both a short smoothing timeout (ESPHome) and a longer presence timeout (HA or Node-RED) exist, document both with their distinct purposes so they are not confused.

### 6.3 Existing Pattern Investigation

Moved to `tos/JCTsh-Operating-System.md`'s Engineering Discipline section (CARD-0289 follow-on) — the underlying rule isn't hardware-specific. Applied here: before writing any integration code that touches an existing process (logging, presence automation, HA-SmartThings bridge, Node-RED flows), read the relevant flow JSON, YAML, or source file first.

### 6.4 New Smart-Home Devices Default to SmartThings-Free

Decided 2026-09-11 (CARD-0164), prompted by the household's first Matter devices. A new commercial smart-home device (a light, sensor, lock, plug — anything outside this repo's own ESP32/ESPHome components) defaults to whichever of these fits, in order of preference, **never SmartThings unless none of the others apply:**

1. **A native Home Assistant integration** (Ecobee, Ring, and most established brands have one) — no intermediary platform at all.
2. **Matter, commissioned into HA first, then exposed to Google Home through HA** — most new devices ship Matter-capable. Check whether it's Matter-over-WiFi (joins the LAN directly, no extra hardware) or Matter-over-Thread (needs a Thread Border Router somewhere on the network — several existing devices, including SmartThings' own hub, can serve this role without the device itself needing to live in SmartThings). **Commission into HA before Google Home, not the reverse or both independently** — see the dedicated note below; this ordering was learned the hard way from the first real Matter devices.
3. **SmartThings, only if neither above applies** — e.g. genuine Zigbee/Z-Wave hardware with no other bridge available.

**Why:** SmartThings' developer API access ends its free tier October 2026 (CARD-0164) — every device added there is a device that would need migrating later if the API dependency is ever fully dropped. The existing Zigbee/Z-Wave hardware already paired to the SmartThings hub is deliberately *not* being migrated (real, disruptive work with no forcing deadline, since the hub/app itself stays free indefinitely) — this standard exists so that installed base stops growing, not to retroactively fix it.

**For anything that needs to reach Google Home for voice control** (the actual reason JCTsh components have historically used SmartThings virtual switches): use **HA's own native Google Assistant Smart Home integration** (via Nabu Casa, already active for other reasons) instead of a SmartThings-virtual-switch bridge. See `components/outdoor-presence-detection/CLAUDE.md` for a real, already-built precedent that chose this path over the SmartThings-virtual-switch-and-Routine pattern for exactly this reason.

**Matter device registration order, added 2026-09-12 (CARD-0262) — a real gap found, not a hypothetical.** The household's first three Matter devices (Cync under-cabinet lights) were registered directly in Google Home. Result: zero visibility from HA (`404 Entity not found` on every one, confirmed live) — Google Home doesn't sync back to HA the way SmartThings did. **Always commission a new Matter device into Home Assistant first**, then expose it to Google Home via HA's own native Google Assistant integration (§6.4 point 2 above) — never register in Google Home directly, and never commission into both independently (Matter's multi-admin support makes this technically possible, but it creates two separate registrations of the same device that can drift, rather than one source of truth with Google Home as a view into it). This mirrors the exact pattern already used for every JCTsh-custom device reaching Google Home.

**Commissioning mechanics on Android** (this household's phones): the official Home Assistant Companion app (Play Store build, not F-Droid) has an "Add Matter Device" flow that hands off to Android's own system-level Google Matter commissioning UI to do the actual pairing, then relays the result back to HA in the background — needs the Companion app's Location permission set to "Allow all the time." This is a *front-end* only — HA's own Matter integration and its backend Matter Server (`python-matter-server`) must already be configured for this to have anything to hand the device off to. On a plain Docker Container HA install (not Home Assistant OS), that backend doesn't come for free — it needs its own container, added explicitly, not just an "Add Integration" click. See CARD-0262 for the concrete setup.

**Real gotcha found during CARD-0262's build, worth checking on any future Matter device: `python-matter-server` needs `--primary-interface` pinned on a dual-homed host.** The Pi runs both `eth0` (wired, its normal primary) and `wlan0` (WiFi) — with neither pinned, the server logs `Using 'None' as primary interface (for link-local addresses)` at startup, and commissioning a WiFi-only Matter device fails with `PASESession timed out` / `Secure Pairing Failed` against the device's link-local IPv6 address, since the server doesn't know which interface to send that traffic out on. Fix: add `--primary-interface wlan0` (or whichever interface the target device actually joins) to the container's `command:` in `core/homeassistant/docker-compose.yml` — confirmed via the startup log correctly switching to `Using 'wlan0' as primary interface`, and by three subsequent commissioning attempts all succeeding with the link-local address correctly carrying the `%wlan0` zone identifier. Only relevant on a host with more than one active network interface — a single-homed HA install wouldn't hit this.

### 6.5 New Automations: HA vs. Google Home, Never a New SmartThings Routine

Decided 2026-09-11 (CARD-0164), extending §6.4 from devices to automations. Three automation engines exist in this household — Home Assistant/Node-RED, Google Home's own Routines, and SmartThings' own Routines — and the choice between the first two is a single test, with the third no longer a candidate for new work:

**The test: does Robin need to see, trigger, or adjust this herself?**
- **Yes → Google Home Routines.** She uses Google Home daily and doesn't use HA or SmartThings directly (and likely never will) — it's the only one of the three automation surfaces she can actually touch. Simple, voice-relevant automations belong here even though Google's own Routines are less capable than the other two.
- **No → Home Assistant / Node-RED.** JCTsh's own internal logic — multi-condition state machines, sensor fusion, timers, anything that should be version-controlled in this repo and observable on the log dashboard — belongs in HA/Node-RED, already the established "brain" per this project's own architecture (`CLAUDE.md`'s Component Roles table). This is the default for anything that isn't specifically Robin-facing.

**SmartThings Routines are not a destination for new automations, regardless of which side of the test above an automation falls on.** Not because they're technically deficient — they're arguably more capable than Google's own Routines — but every reason to use them evaporates once new work isn't building on SmartThings by default: Robin can't see or adjust them, they get none of JCTsh's own observability, and anything triggered from HA re-creates the exact paid-API dependency §6.4 exists to stop growing. **Existing native SmartThings Routines** (a real SmartThings device triggering another real SmartThings device, with HA never in the loop) are fine to leave running untouched — they don't depend on the deprecated developer API at all — this rule is about where *new* automation logic goes, not a mandate to migrate what already works.

**A real gotcha when moving an existing automation off a SmartThings-sourced device:** Google Home identifies a device by which partner integration supplied it. Swapping a device from SmartThings-sourced to HA-sourced — even keeping an identical entity_id inside HA — makes Google treat it as a brand-new device, not the same one. Any existing Google Home Routine referencing the old device by name will silently point at a dead device afterward; it does not auto-follow. Audit Google Home's own Routines list for references to a device before migrating it, and re-point anything found afterward — this can't be checked or fixed from outside the Google Home app itself.

---

## 7. Documentation Standards

### 7.1 Required Documents per Component

Every completed component must have the following in `components/<name>/`:

| Document | Purpose |
|---|---|
| `README.md` | Permanent component reference — what it does, hardware, wiring, MQTT topics, integration, known behaviors, tuning notes |
| `<name>.yaml` or equivalent | ESPHome YAML or source code — the actual implementation |
| `wiring.md` | Pin-by-pin wiring reference including connection table and breadboard layout |
| `flashing.md` | Flash and OTA update instructions |
| `testing.md` | Sensor validation and enhancement validation procedures |
| `perfboard-layout.md` | Permanent build layout, soldering sequence, continuity check procedure |
| `mounting.md` | Physical installation guide |
| `integration.md` | Integration instructions for Node-RED, HA, and SmartThings |
| `integration-notes.md` | Findings from investigating existing logging, watchdog, presence automation, and SmartThings bridge patterns |
| `end-to-end-test.md` | Full system validation procedure |
| Pinout PNG | ESP32 DevKit pinout reference image |

### 7.1a Required Documents for HA-Only Automation Components

**Every automation app gets a component directory — no exceptions for "it's just a couple automations in `automations.yaml`."** This applies whether the component has any dedicated hardware or not. §7.1's list above assumes an ESP32/physical build; a component that's purely HA automations (no firmware, no wiring, no enclosure) doesn't need those hardware-specific documents, but still needs a real, discoverable home in `components/<name>/` rather than living only in `automations.yaml`'s own inline `description:` comments and `kanban-board.md`'s card history.

| Document | Purpose |
|---|---|
| `README.md` | What the component does, which `automations.yaml` entries belong to it (by `id:`/`alias:`), entities involved, how to verify it's working, how to turn it on/off if applicable |
| `CLAUDE.md` | Full automation YAML (kept in sync with the deployed source) plus design rationale and revision history — mirrors the inline `description:` block already required in every automation (§2.7-adjacent convention), but as a standalone, greppable file rather than only living inside the YAML comment |

Multiple related automations belonging to one conceptual feature (e.g. a nightly randomizer automation plus its action automation) share one component directory — split into separate documented sub-features within the same README/CLAUDE.md rather than one directory per individual automation entity, if they're clearly part of the same user-facing feature.

**Reference implementations:** `components/traveling/` (Traveling Lights + Unexpected TV Activity), `components/outdoor-presence-detection/` (Ring motion announcement + doorbell live video).

### 7.2 Top-Level README

Update the top-level `README.md` Components list when a new component is completed.

### 7.3 CLAUDE.md Credentials Table

Add the new component's MQTT account to the credentials table in root `CLAUDE.md` when the account is created.

### 7.4 Parts Inventory Update

Add an entry to JCTsh-Parts-Inventory.md inventory update log when a project is completed. Record all tracked parts consumed.

### 7.5 Documentation Captures Reality

Moved to `tos/JCTsh-Operating-System.md`'s Note on Build (CARD-0289 follow-on) — pure process, no technology content, and overlapped the existing Reflection requirement there.

---

## 8. LED Indicator Standards

When LED indicators are included in a component:

- **Green LED** — primary positive state (presence detected, sensor active, connection established)
- **Yellow LED** — secondary or downstream state (virtual switch status, integration state)
- **Red LED** — fault, error, or disconnected state (reserved for future use)
- **Current-limiting resistor:** 330Ω for standard 5mm LEDs at 3.3V (~6-7mA)
- **GPIO selection:** avoid GPIO0 (boot), GPIO2 (onboard LED), and any GPIO already allocated to a peripheral

---

## 9. Non-ESP32 / Docker-Based Component Standards

Standards for components that are not ESP32/ESPHome devices — Docker-based services on dedicated Linux hosts (e.g. `photo-server`). Sections 1-8 above assume an ESP32; this section is the equivalent for a Docker/Linux host component. First established during the `photo-server` (Immich) build.

### 9.1 Docker DNS Pinning

Pin DNS in the Docker daemon config for any host running containers that need external connectivity:

```json
{
  "dns": ["8.8.8.8", "8.8.4.4"]
}
```

Applied at `/etc/docker/daemon.json`, then `sudo systemctl restart docker`. This is now twice-applied (Home Assistant's container, Immich's) — required, not optional. Root cause it prevents: a stale DHCP-assigned DNS server getting baked into a container's network config at creation time, which caused a full cloud-connectivity outage for HA in June 2026 and would otherwise repeat for any new container.

### 9.2 UUID-Based USB Storage Mounts

Any component with attached external storage mounts via UUID in `/etc/fstab` — never a raw device path (`/dev/sdX`), which can silently renumber on reconnect (confirmed happening mid-build to photo-server's own primary drive, `sda` → `sdc`, with no user action). Always add `nofail`, so a disconnected or missing drive doesn't block the host from booting:

```
UUID=<disk-uuid>  /mnt/<mount-point>  ext4  defaults,nofail  0  2
```

Prefer bus-powered 2.5" USB drives for compact installations — no separate power brick/cable to manage or fail. Note the tradeoff when sizing spares: a larger bus-powered drive may not exist, forcing a choice between capacity and the bus-powered convenience.

**Reference implementation:** `components/photo-server/backup.md`, `hosts/m8/network.md`.

### 9.3 Incremental Local Backup (rsync)

Weekly cron running `rsync -av --delete <source>/ <backup-destination>/` from primary storage to a local backup drive.

**This is incremental by design** — worth stating explicitly, since it is not obvious from a one-line script. `rsync` only transfers files that are new or changed since the last run (by size/mtime); `--delete` additionally removes anything from the destination no longer present in the source, keeping it an exact mirror rather than an ever-growing pile. A slow first run does not mean something is wrong — it means the destination is being fully reconciled for the first time (or after an unrelated change invalidated it); subsequent weekly runs should be fast, transferring only that week's actual changes.

**Reference implementation:** `components/photo-server/photo-library-backup.sh`, `components/photo-server/backup.md`.

### 9.4 Dashboard Visibility for Scheduled/Background Jobs

The non-ESP32 equivalent of §4's heartbeat/log standards. For any recurring systemd timer or cron job on a Docker/Linux host (scheduled reboots, backups, or similar), publish a matched pair of MQTT log messages to the JCTsh dashboard — one immediately before the job starts, one on completion:

```json
{"component":"<host-component-name>","category":"System","message":"<Job> starting."}
{"component":"<host-component-name>","category":"System","message":"<Job> complete."}
{"component":"<host-component-name>","category":"Alert","message":"<Job> failed (<detail>)."}
```

Reuse the host's existing MQTT account (e.g. `photo-server`, `jctsh-log-server`) via `mosquitto_pub` — do not create a new account per job. Neither message uses the `"Heartbeat - "` prefix, so each occurrence stays visible as its own dashboard row rather than collapsing, matching how ESP32 Alert-category messages behave (§4.2).

This pattern was established twice in the same build with an identical shape both times (scheduled-reboot notifications, then backup-run notifications), which is what promotes it from a one-off to a standard — the second implementation should not need to reinvent it.

**Reference implementation:** `core/maintenance/reboot-complete-pi.service` / `reboot-complete-m8.service`, `components/photo-server/photo-library-backup.sh`.

### 9.5 Scheduled Maintenance Windows — Cross-Host Coordination

Any new recurring job (cron or systemd timer) on any JCTsh host must be checked against the **Scheduled Maintenance Windows** table in `network/jctsh-network.md` before scheduling, and added to that table once deployed.

**Rule of thumb:** at least one hour of clearance from any other recurring job on any host, especially where one job's MQTT publish depends on another host being reachable — e.g. the Pi/M8 reboot stagger exists specifically because the M8's heartbeat publishes to the Pi's broker, so overlapping reboots would produce a false "down" reading for the wrong reason.

### 9.6 Detached Remote Job Execution

For any long-running remote job (data imports, backups, verification runs) that must survive the initiating SSH session ending, launch it via `nohup <command> & disown` on the remote host itself — not a local polling/monitoring loop.

**Critical:** verify actual state via `ps aux` / `systemctl status` on the remote host directly. Never assume that stopping a local monitoring tool has any effect on a detached remote process — it does not, and assuming otherwise caused a real duplicate-write race during the original `photo-server` Takeout migration (two `mv` operations racing on the same files after a local poller was stopped but the remote job kept running).

**Reference:** `components/photo-server/migration.md` ("Killed background processes didn't actually die").

### 9.7 Container-Image Update Visibility via GitHub Releases

For any Docker-based component running an open-source image (not project-specific code like Immich's own API — see below), check for updates via the image's **GitHub Releases API**, not a per-service custom integration:

1. Confirm the running container's `org.opencontainers.image.source` label points at a repo that actually publishes releases — `docker inspect <container> --format '{{index .Config.Labels "org.opencontainers.image.source"}}'`, then verify with `curl -s -o /dev/null -w '%{http_code}' https://api.github.com/repos/<owner>/<repo>/releases/latest` before trusting it. **Not guaranteed to be the right repo** — confirmed live 2026-07-31 that Caddy's own image labels point at `caddyserver/caddy-docker` (the Dockerfile-packaging repo, 404 on releases), while the real releases matching the running version live at `caddyserver/caddy`. Docker packaging repos and core-software repos are often split; check, don't assume.
2. Determine the currently-running version from `org.opencontainers.image.version` if the image sets it; if not (cloudflared doesn't), exec the binary's own version flag inside the container (`docker exec <container> <binary> --version`) and regex out the version string.
3. Normalize before comparing — different projects format release tags differently (`v2.11.4` vs. bare `26.7.1`); strip a leading `v` before the equality check.
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

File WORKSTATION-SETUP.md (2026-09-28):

# JCTsh Workstation Setup

Reference for what this repo's development/flashing workstation (Joseph's Windows machine)
needs installed and configured, and the tool-specific gotchas that aren't obvious from error
messages alone. Single-operator machine, not a fleet of contributor machines — this is the
canonical, actively-read home for these facts (CARD-0357); several were previously recorded
only in archived card history (`card-archive.md`, on-demand-only reading) or scattered across
individual component `flashing.md` files, which is how the Python-version gap below went
unnoticed for ~5 months. For the Pi/M8's own software, see `SOFTWARE-ENVIRONMENT.md`; for the
physical smart-home devices, see `ENVIRONMENT.md`.

**`workstation-verify.ps1` (repo root, CARD-0360) checks the workstation's actual state
against this doc** — Python versions via the `py` launcher, which ESPHome pip version the
live `esphome` command resolves to versus the pin documented below (parsed from this file,
not a separately hardcoded copy), and a MAX_PATH-risk proxy on the current working
directory. Verify-only — reports drift, changes nothing. Run it (native PowerShell) before
a compile/flash session, not just when something's already gone wrong; it doesn't replace
reading the gotchas below, since those explain *why* each check exists.

## Python

| Version | Purpose |
|---|---|
| 3.11.x (`C:\Users\jcthomas\AppData\Local\Programs\Python\Python311\`) | Long-standing base install — general scripting, most tooling |
| 3.12.10 (installed 2026-09-27, CARD-0357, via `winget install Python.Python.3.12`) | Required by ESPHome 2026.7.0+ (see below) — installed alongside 3.11, not replacing it |

Both are reachable via the `py` launcher: `py -3.11`, `py -3.12` (bare `py`/`python` defaults
to whichever was installed/registered first — check with `py -0` before assuming).

## ESPHome (firmware build/flash tooling)

**Currently pinned at `2026.4.5`** (`pip install esphome==2026.4.5`) — every component's
`flashing.md`/build-instructions doc should say this. The pin exists because `2026.9.0`
(current latest as of 2026-09-27) was believed to "break the compile" when first tried
around CARD-0333/CARD-0335 (2026-09-24/25) — **root-caused 2026-09-27/28, CARD-0357, and it
was never actually a YAML/config incompatibility:**

1. **ESPHome 2026.7.0 and later require Python ≥3.12** (`Requires-Python >=3.12.0,<3.15` on
   PyPI) — this workstation only had 3.11 at the time, so `pip install esphome==2026.9.0`
   couldn't even resolve a matching distribution. Fixed by installing 3.12 above.
2. **ESP-IDF's own toolchain installer refuses to run under Git Bash/MSYS** — `ERROR:
   MSys/Mingw is not supported`. This is real and applies to *any* ESPHome version doing a
   fresh ESP-IDF framework install, not just 2026.9.0 — **always compile/flash from native
   PowerShell or cmd, never Git Bash**, even though Git Bash is this repo's normal shell for
   everything else (SSH to the Pi/M8, git, etc. — see below).
3. **Windows `MAX_PATH` (260 chars) can break a DLL import inside `aioesphomeapi`** (a
   dependency ESPHome's `time:` component pulls in) with `ImportError: DLL load failed ...
   The filename or extension is too long` if the venv/install path is too deeply nested —
   confirmed live at exactly 255 characters. **This is the actual reason for the
   `C:\esphome\<name>\` flash-directory convention** (short, root-level, no spaces) already
   used for real device flashes — previously followed without the underlying reason being
   written down anywhere live.

**Confirmed 2026-09-27/28 (CARD-0357):** with Python 3.12 + native PowerShell + a
short working path, `garage-radar.yaml` compiles clean on ESPHome 2026.9.0 (exit 0, real
firmware binaries generated) — strong evidence the 5-month-old pin was never a real ESPHome
regression. **Not yet re-verified for the other 5 devices**, and the live fleet's actual pin
has deliberately **not** been bumped yet (CARD-0357's own scope decision: fix + prove the
compile, don't force a fleet-wide reflash in the same pass). Per Joseph's direction
(2026-09-28): the pin gets revisited **per device, at that device's next real flash** —
whoever next runs `esphome run <device>.yaml` should try the current latest ESPHome first
now that the workstation is actually capable of running it, rather than reflexively reusing
`2026.4.5`.

**Other real gotchas, carried forward from archived card history:**
- **Stale `.esphome` build-cache directories can cause `Access is denied` / permission
  errors** when ESPHome tries to clean them after a version or environment change (e.g. a
  Windows user-profile rename left one such cache pointing at a dead path). `.esphome/` is
  always gitignored and fully regenerable — if a compile fails while trying to *clean* the
  build directory (not while actually building), delete `.esphome/` under that component and
  retry before assuming anything else is wrong.
- **After flashing, wait past ~60s before touching the device** — ESP32 OTA has automatic
  rollback: if the new image reboots before it's marked valid, the bootloader silently
  reverts to the previous firmware, and every observation in that window is actually the
  *old* firmware running.

## SSH (Pi / M8 access)

**Use Git Bash's `ssh`, not PowerShell's native OpenSSH** — PowerShell's OpenSSH client
rejects `~/.ssh/id_ed25519` on ACL grounds where Git Bash's `ssh` (and the `Bash` tool) work
fine (found live during CARD-0328). If a `ssh`/`scp` command needs a fresh host-key prompt
answered non-interactively, use `-o StrictHostKeyChecking=accept-new` after comparing the
fingerprint against the already-trusted key — a plain shell command can't answer an
interactive host-key prompt.

## Filesystem

**`C:\Shared` is a junction, not a real directory** — the `Read`/`Write`/`Glob` tools refuse
to operate on it; PowerShell reads/writes it fine. Relevant any time a task touches something
under that path (e.g. RoboForm exports, per `digital-identity-protection-checklist.md`).

## Not covered here (CARD-0344's explicit scope boundary, unchanged)

Git, `gh`, Claude Code, and ESP-IDF's own toolchain versioning are deliberately not tracked
by any maintenance check or this doc's own currency — only ESPHome, because it's the one tool
that has actually broken a build. Revisit that boundary if a second real gap in one of those
shows up, not preemptively.

**Related:** CARD-0357 (root-caused the ESPHome pin, wrote this doc), CARD-0333/CARD-0335
(where the pin was first established), CARD-0344 (the update-check scope boundary this doc's
last section restates), CARD-0328 (found the SSH ACL gotcha).

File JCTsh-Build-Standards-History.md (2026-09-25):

# JCTsh-Build-Standards.md — Version History

Full changelog for `JCTsh-Build-Standards.md`, split out (CARD-0292) once it reached 14.6KB inside an already-121KB file — read on demand only, not part of routine reading. The live document's own header states only the current version and description.

---

## Standards Version History

| Version | Change |
|---|---|
| 1.41 | CARD-0335 — §4.1's boot-time heartbeat rule now states its applicability instead of saying "every component": the false watchdog alert needs the worst-case gap (2 × the heartbeat interval plus the reboot's downtime) to exceed the 35-minute timeout, i.e. an interval above roughly 15 minutes. 30-minute heartbeats must send a boot heartbeat; the 5-minute heartbeats (`hiking-monitor`, `air-quality-monitor`) cannot hit it and are exempt; systemd-timer heartbeats already do it with `OnBootSec=2min` (`photo-server`, `p-w-firefly`). |
| 1.40 | CARD-0333 — §4.1 gained a required boot-time heartbeat: the 30-minute interval counts from boot, so any reboot more than ~5 minutes after a heartbeat left a gap longer than the watchdog's 35-minute timeout and raised a false `silent` alert. Conditions (after the first valid reading, only once MQTT is connected, same guards as the regular heartbeat) and a reference ESPHome snippet are included. §2.5 gained the OTA-rollback gotcha: never reboot within ~60 s of a flash, and verify the device's *reported* config hash before drawing conclusions. |
| 1.39 | CARD-0303 — merged root `CLAUDE.md`'s richer content into the canonical sections it was duplicating, then trimmed `CLAUDE.md` to pointers: §4.2 gained the fuller MQTT log-category table and a new Event-time convention (missing here entirely before); §5 gained a note flagging that its own opening line contradicted §6.4's later SmartThings-Free policy (struck through, not deleted); new §5.7 for SmartThings sensor-exposure; §10.5 gained the full risk-accounting detail (mitigations, risks accepted, LAN security); §2.6's GPIO exclusion list was reconciled with `CLAUDE.md`'s separate list, which had genuinely diverged (each missing pins the other correctly excluded) — now one complete, correct list. |
| 1.38 | Split this table out of `JCTsh-Build-Standards.md` into this file (CARD-0292) — it had grown to 14.6KB inside an already-121KB file. From this version on, the live document's header holds only the current version's description; this file is the complete record. |
| 1.37 | Moved §6.1 (Additive First), §6.3 (Existing Pattern Investigation), and §7.5 (Documentation Captures Reality) to `tos/JCTsh-Operating-System.md` — pure process/policy with no technology content, found via a repo-wide review of what belongs in this doc vs. the TOS doc (CARD-0289 follow-on). Section numbers kept here as pointers. |
| 1.35 | Added §9.10, SD-Card Hosts: Route Every Write-Heavy Path Off the SD Card — harvested from CARD-0159/CARD-0006 (previously only captured in CLAUDE.md's project-specific Infrastructure section, never in this reusable standards doc). Covers Docker `data-root` + containerd `root` (two separate paths), container/native-service persistent state, and `/var/log` as a whole, plus the mount-ordering-race gotcha (`RequiresMountsFor`) hit three separate times (CARD-0032/CARD-0048/CARD-0006) before becoming a checked step. |
| 1.34 | Added §9.9, `journald` as the Docker Logging Driver — the M8-wide switch (CARD-0272), why a per-service `logging:` options block breaks under it (found live via netalertx), and why a `daemon.json` driver change needs every container recreated, not just a daemon restart. |
| 1.30 | Extended §6.4 with a Matter device registration order (HA first, then expose to Google Home through HA — never register in Google Home directly or into both independently) after the household's first 3 Matter devices were registered directly in Google Home and left HA with zero visibility (`404 Entity not found` on every one). Documents the Android HA Companion app's "Add Matter Device" commissioning flow (hands off to Android's system Google Matter UI, relays to HA) and that it still needs HA's own Matter Server backend already configured — which a Docker Container HA install (not Home Assistant OS) doesn't have by default. See CARD-0262. |
| 1.29 | Added §6.5 New Automations: HA vs. Google Home, Never a New SmartThings Routine — extends §6.4's device-level policy to automations. A single test decides between the two remaining engines (does Robin need to see/trigger/adjust it herself → Google Home Routines; otherwise → HA/Node-RED, the established brain), with SmartThings Routines no longer a destination for new automation logic either way (existing native ones, untouched by HA, stay as-is — this governs new work only). Documents the real gotcha found while scoping CARD-0260/CARD-0261: migrating a device off SmartThings makes Google treat it as a brand-new device, silently orphaning any existing Google Home Routine that referenced the old one by name. |
| 1.28 | Added §6.4 New Smart-Home Devices Default to SmartThings-Free — a preference order (native HA integration, then Matter direct to HA/Google, then SmartThings only as a last resort) for any future commercial smart-home device, plus HA's own native Google Assistant integration as the standard path to Google Home voice control rather than a SmartThings virtual-switch bridge. Harvested from CARD-0164's decided direction (drop the paid SmartThings API dependency, leave the existing Zigbee/Z-Wave hardware on the hub alone), prompted by installing the household's first Matter devices (3 Cync under-cabinet lights, confirmed Matter-over-WiFi). |
| 1.27 | Broadened v1.26's §2.3 debug-UART design provision beyond battery-powered builds — the design-time GPIO17/UART2 reservation now applies to any component that will lose convenient onboard-USB debug access: battery-powered with a separate regulator (backfeed risk), going into an enclosure, deployed somewhere physically inconvenient, or where a WiFi/MQTT problem being debugged is itself the transport OTA logging would depend on. Raised directly by Joseph questioning why the v1.26 scoping was battery-specific — correct: that was the narrowest justification, not the whole one. |
| 1.26 | Extended §2.3 UART with a secondary debug-UART standard for battery-powered builds: a design-time requirement to reserve GPIO17/UART2 for debug logging whenever the board's own onboard USB-C can't safely double as a console while running on battery; the ESPHome `uart_set_pin()` gap (`hardware_uart: UART2` starts the peripheral but never routes it through the GPIO matrix without a manual `on_boot` lambda call); the adapter-VCC-must-stay-disconnected rule (avoids a second unisolated power source); the loose-GND silent-failure gotcha (zero bytes, no error, easy to mistake for a firmware regression); and a cheapest-first troubleshooting order (loopback the adapter, then verify the raw GPIO toggle, before suspecting firmware). Harvested from air-quality-monitor's CARD-0205, whose own long troubleshooting arc hit every one of these in turn. |
| 1.25 | Added §2.14 point 13: the complete data-flow model for a field-and-later-upload device as three distinct steps — the attempt gate (Intent off AND Power Connected, both genuinely required, not either alone), a bounded attempt with periodic retry (not indefinite, not one-shot), and the actual upload only beginning once WiFi and MQTT both succeed. Also documents that "Power Connected" is deliberately broader than the word "docked" implies (fires identically for home dock, solar, or field USB), and that whether field logging itself pauses on Power Connected is a per-device design choice (hiking-monitor stops, air-quality-monitor doesn't), not dictated by this point. Prompted by a real back-and-forth where Claude initially mis-stated Power Connected as not required — corrected directly by Joseph. |
| 1.24 | Added §2.14 point 12: the three-signal hardware framework required for any field-and-later-upload device -- Intent (deliberate, user-set "am I collecting or idle" declaration), Power Connected (pure charging-current fact, USB or solar), and Power Switch (genuine zero-draw off) -- each orthogonal, never one inferred from another. A real audit of both existing field devices found neither has all three independently: hiking-monitor has Intent + Power Connected cleanly separated but no real Power Switch (the slide switch isn't in the power path; true off requires disconnecting the LiPo JST, CARD-0181, Defer); air-quality-monitor has a real Power Switch + Power Connected but no Intent signal at all (its 2026-08-19 design used dock-detect for mode-switching, conflating Power Connected with Intent from the start -- surfaced 2026-08-27, CARD-0218). Point 11 is this framework's firmware-behavior consequence. |
| 1.23 | Added §2.14 point 11: a field device that buffers data for later upload must never attempt WiFi while actively collecting, only once its own session-over signal fires -- never just because a charging/dock signal went high, since power and network availability are unrelated (solar in particular correlates with worse connectivity, not better). Harvested from hiking-monitor's real 2026-08-27 reset storm (CARD-0217) and the related CARD-0045 fix (dock_detect-triggered WiFi re-enable now also requires the field-mode switch to be off). Checking this against air-quality-monitor's own not-yet-built Step 8 duty-cycle design (CARD-0218) -- which had already planned the same bounded-retry-with-cooldown mistake this point rules out -- surfaced a real, unresolved gap: that device has no GPIO-readable mode signal at all to hook the rule to, a design question for Step 8 to actually resolve, not something this standards update settles by itself. |
| 1.22 | Added §2.14 points 9-10: quantified regulator peak-current headroom (2-3x the coincident peak load — WiFi TX/association spike + any active peripheral + baseline draw — not the average), required bulk capacitance at the point of load (a few hundred µF electrolytic + small ceramic, framed as a complement to headroom, not a substitute), and a firmware-sequencing requirement to avoid stacking WiFi association with a peripheral's own power-up. Extended point 2's low-battery cutoff to explicitly cover WiFi-burst operations (replay/upload/OTA), not just continuous logging. Harvested same-night from CARD-0198 (air-quality-monitor) and CARD-0211/CARD-0212 (hiking-monitor) hitting the identical brownout-under-WiFi-spike physics on two different devices, grounded in CARD-0026's real measured WiFi-burst current (109-154mA) on hiking-monitor's own hardware. |
| 1.20 | Added a cross-device MQTT discovery unique_id collision gotcha to §3.5 — ESPHome's default legacy id generator derives an entity's discovery id from type+name alone, so identically-named entities on different devices (e.g. two "Restart" buttons) silently collide, with the loser dropped from HA with no visible error. Two fix patterns by blast radius (mac generator if the device exposes only that one entity; device-specific name otherwise), plus the requirement to clear the stale retained discovery topic after either fix and a note on avoiding doubled device-name-in-entity-name results. Harvested from CARD-0180/CARD-0186 — salt-sensor's restart button had silently never worked in HA until this was found. |
| 1.19 | Added §1.7 Accessible Power Control for Enclosed Devices — a true hard power-off and a reboot/reset trigger, both reachable without disassembly, required for any enclosed component and decided before the enclosure is sealed. Harvested from hiking-monitor's final assembly (CARD-0009) surfacing both gaps only after sealing (CARD-0181, CARD-0180), including the gotcha that a switch can look like a power switch without sitting in the power path. |
| 1.18 | Added §1.5 3D-Printed Enclosure Build Pattern (two-tool OpenSCAD+Tinkercad workflow, `-raw`/`-final` naming, open-face-down print orientation, PLA-test-then-final-material pattern, hex-nut capture fastening, ASA/PETG material choice, press-fit/slot/bail sizing tolerances, design-record discipline for live Tinkercad edits) and §1.6 Sensor Cable Relocation for Mounting-Orientation Flexibility (STEMMA QT/Dupont relocation for rigid-socket-mounted sensors, pinout-verification-not-color-matching gotcha) — harvested from the completed hiking-monitor enclosure build (CARD-0009). |
| 1.17 | Added §9.7 Container-Image Update Visibility via GitHub Releases — harvested from CARD-0126 (NetAlertX, Caddy, cloudflared, Home Assistant). Generic pattern: check the OCI `source` label's repo for GitHub releases (verified, not assumed — Caddy's own label points at the wrong repo), determine current version from the `version` label or a binary `--version` exec, normalize tag formats before comparing, notify-only via the same throttled `System`-category convention as every other maintenance check. |
| 1.16 | §1.2 now points to `JCTsh-Perfboard-Build-Template.md` (new, repo root) — a reusable section skeleton for a component's `perfboard-layout.md`, generalized from hiking-monitor's and salt-sensor's builds now that there are two real examples to draw from. |
| 1.15 | Added §1.2 pin-verification guidance — harvested from salt-sensor's CARD-0049 perfboard build: identify pins by printed silkscreen label rather than a documented reference table's position numbers (different board brands/clones can have different physical pin order despite the same GPIO count), and add isolation checks between visually-adjacent pin labels to Pre-Power Checks, not just intentional-net continuity checks. |
| 1.14 | Added §10 Security Standards — harvested from the completed JCTsh security hardening audit (CARD-0022/CARD-0023, `jctsh-security-hardening.md`). Covers SSH key-only auth, MQTT broker auth, `secrets.yaml` gitignore requirement, Node-RED `adminAuth`, Tailscale-as-sole-remote-access-path with the accepted MQTT-port-forward exception, MFA requirement across every cloud account (including per-user HA TOTP), router UPnP/remote-management policy, router admin password/firmware currency, and Windows SSH private key permissions. |
| 1.13 | Added §9 Non-ESP32 / Docker-Based Component Standards — first section for non-ESP32/Docker host components, harvested from the `photo-server` (Immich) build. §9.1 Docker DNS pinning (twice-applied: HA, Immich). §9.2 UUID-based USB storage mounts with `nofail`, bus-powered drive preference. §9.3 incremental rsync local backup — explicit note that `rsync --delete` is incremental, not a full re-copy each run. §9.4 dashboard visibility for scheduled/background jobs — matched start/complete MQTT message pairs, the non-ESP32 equivalent of §4's heartbeat standard, established twice in one build (reboot notifications, backup notifications) with an identical shape. §9.5 cross-host schedule coordination via the `network/jctsh-network.md` Scheduled Maintenance Windows table, ≥1 hour clearance rule of thumb. §9.6 detached remote job execution (`nohup ... & disown`) with the rule to always verify via `ps aux`/`systemctl status` on the remote host, never assume a local monitor stopping affects a detached remote process. |
| 1.12 | Added §2.14 point 3 charging-surface guidance: the fireproof bag must sit on a heat-insulating, non-combustible surface (concrete/masonry, ceramic tile, cement board, or a sand/kitty-litter-lined metal tray) — never bare sheet metal on a wooden workbench, since metal conducts thermal-runaway heat straight through to the wood rather than blocking it. |
| 1.11 | Added §2.14 point 8: GPIO-controlled power gating for I2C/SPI peripherals during sleep (P-FET high-side switch on the microcontroller's 3.3V output, not the boost module's output) — flagged as a candidate pattern, not yet a required standard, pending validation via hiking-monitor CARD-0026/CARD-0027. |
| 1.10 | Added §2.14 point 7: prefer direct LiPo-to-LDO power architecture over boost-then-buck for new battery-powered builds — avoids two-stage conversion idle draw and the boost converter's end-of-charge instability. Recommended default for the *next* build, not applied retroactively to hiking-monitor. |
| 1.9 | Added §2.14 Battery-Powered Component Safety Standards: PCM-protected cells required (verify before purchase, EEMB 603449 confirmed compliant), firmware low-battery cutoff required (3.4V threshold, checked at boot and during operation, persistent e-ink warning), fireproof charging bag required, never charge a cell showing 0V/swelling/heat/smell, storage at 40-60% charge, disposal via battery recycling, connector polarity verification before first use. Established after hiking-monitor's original battery failed in the field with no advance warning (2026-07-03). |
| 1.0 | Initial release. Enclosure convention, ESP32/ESPHome standards, MQTT conventions, observability standards, SmartThings integration, LED standards, documentation standards. |
| 1.8 | Updated §5.4: broker now runs MQTT v5 (Mosquitto 2.0.21, `protocolVersion: 5` in Node-RED broker node). Removed MQTT v5 field cleanup warning — v5 fields from Node-RED v4 UI imports are now correct. ESP32/ESPHome/HA remain on v3.1.1; Mosquitto accepts both simultaneously. |
| 1.7 | Changed heartbeat standard from 5 minutes to 30 minutes throughout (§2.7, §3.2, §4.1, §4.4, §4.6). 30 min is derived from the watchdog timeout (35 min = interval + 5-min buffer), not arbitrary. Updated front-porch-temp-sensor.yaml to match. |
| 1.6 | Added §2.8 multi-network WiFi variant (networks: list) and captive_portal deep-sleep exception. Added §2.12 e-ink display pattern. Added §2.13 multi-priority on_boot sequencing. Updated §3.3 with DuckDNS broker guidance for cellular components. Added §3.6 rssi_dbm=0 field-mode sentinel. Added §5.5 GPS timestamp lookup pattern. Added §5.6 Node-RED per-component context isolation. |
| 1.5 | Added §5.4 Node-RED flow deployment patterns (MQTT v5 field issue, flows.json injection, Apps Script 405 redirect, alphanumeric API keys, env vars via EnvironmentFile), watchdog is a new Node-RED flow (not an existing process). Added SmartThings actual integration path (Node-RED → HA REST API → virtual switch). Added MQTT account creation as a required step. Added phone notification via HA companion app as watchdog alert method. |
| 1.4 | Added §2.10 onboard flash logging standard: use ESP-IDF SPIFFS not Arduino LittleFS; name files by function not library. Fixed §2.7 reference from "LittleFS replay loop" to "SPIFFS replay loop". Renumbered MQTT account creation to §2.11. |
| 1.3 | Added §2.8 ESPHome component boilerplate (board, framework, logger, captive_portal, WiFi AP fallback naming, component naming consistency, flash path). Added §2.9 sensor coding standards (NaN guards, standard I2C pins GPIO21/22, internal: true housekeeping sensors). Added §3.4 will_message pattern (retain: false critical). Added §3.5 MQTT discovery rule. Fixed §4.1 heartbeat message format and added "Heartbeat - " prefix requirement. Fixed §4.3 log event message formats (hyphen throughout, removed MQTT reconnected event, clarified LWT). |
| 1.2 | Added §2.7 ESPHome MQTT publishing patterns (on_connect and heartbeat). Fixed §4.3 online message format (hyphen not em dash). Added §4.1 note on heartbeat interval discrepancy between standard (5 min) and existing components (30 min). Renumbered MQTT account creation to §2.8/§2.10. |
| 1.1 | Corrected observability section: log format is JSON to /log topic routed by Node-RED (not a separate process to examine). Watchdog is a new Node-RED flow built as part of garage-radar project, not an existing process. Added actual SmartThings integration path (Node-RED → HA REST API → virtual switch). Added MQTT account creation procedure (Section 2.7) including Mosquitto passwd ownership gotcha. Added phone notification via HA companion app as watchdog alert method. Added CLAUDE.md credentials table update to documentation standards. |

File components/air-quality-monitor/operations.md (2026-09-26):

# Air Quality Monitor — Operations Guide

Day-to-day operation and interpretation. For build steps see
`air-quality-monitor-claude-code-instructions.md`; for physical wiring see
`wiring.md`; for the full build/debugging history see `tos/kanban-board.md`
(CARD-0012 and its related cards) and `components/air-quality-monitor/CLAUDE.md`.

## Hardware Overview

| Component | Role |
|---|---|
| ESP32 + SEN55 | Reads PM1.0/2.5/4.0/10.0, VOC Index, NOx Index, temperature, humidity every 2 minutes |
| EEMB 1100mAh LiPo + TP4056 + Pololu D24V10F3 | Power system — TP4056 charges the battery only (its boost stage is unused); the Pololu buck regulator supplies the ESP32 directly from the battery |
| BK-1208 latching push button (Power Switch) | True hard off / forced cold restart — gates the regulator's `VIN`, not TP4056's charge path |
| SS12D10 slide switch (Intent, GPIO27) | Signals "actively collecting field data" when closed |
| Dock detect (GPIO32 divider) | Detects external power (USB or solar) on TP4056's charge input |
| RGB LED (KY-016) | Boot self-test, PM2.5 threshold color, and networking-status diagnostics (Blue) |

This is a version-2 design relative to hiking-monitor — same underlying philosophy, evolved with a genuinely different signal architecture. See "The Three-Signal Model" below for the key difference.

---

## The Three-Signal Model

Unlike hiking-monitor (which conflates "docked" with "session over"), this device tracks three independent signals, per `JCTsh-Build-Standards.md` §2.14 point 12 — none ever stands in for another:

| Signal | What it means | How it's read |
|---|---|---|
| **Intent** | Are you actively collecting field data right now? | SS12D10 slide switch, GPIO27. Closed (ON) = collecting. |
| **Power Connected** | Is external power (USB or solar) present? | Dock detect, GPIO32. Says nothing about whether a session is over — solar can connect mid-hike. |
| **Power Switch** | Is the device powered at all? | BK-1208 latching button, inline in the battery path. Off = true zero-draw. |

**The key consequence:** field data collection runs whenever Intent is ON, regardless of whether power is connected — plugging in a power bank or the solar panel mid-collection does not end the session or trigger an upload. Only a WiFi/upload attempt cares about Power Connected, and only when Intent is OFF at the same time.

---

## Operating Modes

### Off (Power Switch open)
- True zero-draw — nothing runs, nothing drains.
- TP4056 still charges the battery in this state (charging is upstream of the Power Switch) — leaving it off in storage with USB connected still tops off the battery.
- Also the way to force a cold restart if the device ever hangs or loops: switch off, then on.
- **Normally leave the Power Switch ON** -- it is not part of the routine start/stop cycle (Intent is). Every power-cycle also erases the device's clock (see "The Clock" below).

### Collecting (Intent ON)
- SEN55 duty-cycles every 2 minutes: warms into full Measurement mode (~40s), takes a reading, drops back to low-power RHT/Gas-Only mode until the next cycle.
- Runs unconditionally regardless of Power Connected — collecting on battery alone, or collecting while charging via USB/solar, both work identically.
- No WiFi attempt happens while Intent is ON, full stop — same as hiking-monitor's field mode, for the same reason (no unnecessary radio current while the thing you actually care about is sensor accuracy and battery life).
- Readings buffer to flash if there's no active MQTT connection; buffered readings replay automatically once one exists (see Upload Behavior below).

### Idle / Docked (Intent OFF)
- No sensor duty-cycling.
- If Power Connected and battery is healthy (≥3.5V), the device attempts WiFi/MQTT and replays anything buffered. See Upload Behavior below for the exact gate and retry timing.
- If Power Connected but battery is still low, WiFi is deliberately not attempted — see Battery & Charging below.

---

## The Clock (no RTC) -- read this before a hike

The AQM has **no real-time-clock hardware.** Its only source of time is an SNTP sync over WiFi, and the sync only ever happens while it is docked with Intent OFF (the WiFi gate below). Consequences:

- **The time is valid only until the next power-cycle.** Any reset or a Power Switch off/on erases it; a device that boots away from WiFi has *no* valid time until it is next docked.
- **A reading taken with no clock is now kept, not thrown away** (CARD-0343, 2026-09-26). It is stored with no timestamp but with the seconds since boot and a per-boot id. When you dock it, the replay waits for the clock (usually under a minute, up to 5 minutes), then converts every reading from **the same boot** to its exact real time, and they land in the Sheet like any other reading. Before this fix the first real field run (2026-09-26) recorded nothing: the AQM was powered on at the garage, never got a clock, and all 98 cycles of the hike were skipped.
- **Readings from an earlier boot cannot be timed.** If the device was power-cycled (or reset in the field) after they were taken, they are kept but stay untimed: they are never written to the Sheet, and instead appear in the log dashboard as `Unresolved-time reading kept in log: {...}` with their uptime and boot id, so the data is not lost and can be anchored later by hand.
- **So still: don't power-cycle it before or during a hike.** Leave the Power Switch ON. The device should already be running; confirm with the `Air quality monitor online` line on the log dashboard (or the blue "connected" flash), then unplug and turn Intent ON.
- **After any power-cycle** (forced restart, storage, a dead battery), dock it with Intent OFF and wait for it to connect before the next hike.

---

## Upload Behavior (WiFi Gate)

A WiFi/MQTT attempt requires **all three** to be true simultaneously — checked fresh every 2 minutes, not just at boot:

1. Intent OFF (collecting session genuinely over)
2. Power Connected (docked/charging via USB or solar)
3. Battery ≥ 3.5V

If all three hold and there's no existing connection, the device attempts for up to **2 minutes**; if it can't connect in that window, it gives up and waits **15 minutes** before trying again — indefinitely, not a fixed number of retries. An already-established connection is only torn down by a real Intent-on or Power-disconnected event, never by a momentary voltage dip — a brief under-load sag no longer kills a working link (a real bug found and fixed 2026-09-09).

Buffered readings replay automatically once connected, and also re-check on every 2-minute tick afterward — so if a replay was deferred for low battery while docked, it doesn't need a fresh disconnect/reconnect cycle to retry once voltage recovers.

**Why 3.5V, not the regulator's 3.4V floor:** the regulator's absolute minimum input is 3.4V, confirmed by a real brownout-loop failure at exactly that voltage during battery-alone bench testing. 3.5V keeps a small margin above that catastrophic floor specifically for a weak/solar charging source that might not supply burst current as robustly as USB — not a large safety margin, a deliberate small one.

---

## Battery & Charging

| Voltage | Meaning |
|---|---|
| ~4.2V | Fully charged |
| ~3.7V | Nominal — plenty of capacity |
| 3.5V | WiFi/upload gate — below this, no networking is attempted, everything just keeps buffering to flash |
| 3.4V | Critical — Measurement-mode sampling itself is suspended (RHT/Gas-Only idle continues, voltage keeps being monitored) until it recovers |

Charging is via TP4056 (micro-USB or the SUNYIMA solar panel, both feed the same charge-input node) and is completely independent of the Power Switch position — a device left switched off in storage still charges if plugged in.

**"Replay deferred" log messages are not an error.** Seeing `Replay deferred - battery X.XXV below 3.5V upload threshold, waiting for charge` on the dashboard just means the device woke, checked, found itself under the upload-safe margin, and correctly declined to spend battery on a WiFi attempt — not a fault. If the device then goes fully silent, that's expected too: below 3.5V it stops even trying to connect, so there's nothing further to report until it's recharged past that line (or, if the deeper 3.4V critical floor is reached, until it's recharged past that instead).

---

## The Measurements

SEN55 reports 8 values — this is the complete set the sensor is physically capable of producing:

| Measurement | What it is |
|---|---|
| **PM1.0, PM2.5, PM4.0, PM10.0** (µg/m³) | Airborne particle mass concentration at four size cutoffs. PM2.5 is the one most health guidance cites (wildfire smoke, vehicle exhaust, cooking) — fine enough to reach deep into lungs. PM10 is coarser (dust, pollen). Each size bucket is cumulative — PM10 includes everything PM2.5 counts plus larger particles. |
| **VOC Index** | Volatile organic compounds (paints, cleaning products, cooking, off-gassing). **Not a concentration** — Sensirion's own relative index, 1–500, self-calibrating to "typical recent average for this location," centered on 100. Rising well above 100 means something is actively off-gassing more than usual right now, not an absolute hazard level. |
| **NOx Index** | Nitrogen oxides (combustion — gas stoves, vehicle exhaust). Same index convention as VOC (1–500, baseline ~100, self-calibrating), not ppm. |
| **Temperature / Humidity** | SEN55's own onboard reading, independent of hiking-monitor's BME280 — kept as a second, independent reference for cross-checking that device's readings over time (CARD-0218), not redundant data. |

Both index values take a while to "learn" a baseline after power-on, so readings in the first few minutes of a fresh session are less meaningful than ones taken once it's been running a while.

---

## LED Reference (RGB module)

| Pattern | Meaning |
|---|---|
| Solid red, 3s (boot) | Reset reason was a brownout/glitch — a real power fault caused this boot |
| Solid blue, 1s (boot) | Normal reset reason — ordinary boot |
| 2× blue blink, 2× red blink, 2× yellow (red+green) blink, 2× green blink (boot self-test) | Sensor/system self-test sequence running |
| Green blinking, no timeout (boot) | Waiting for SEN55's first valid reading |
| Solid yellow 3s, then solid red 3s (boot) | Threshold-color demo — confirms the PM2.5 indicator LEDs actually work, not a live reading |
| Green (steady, on a reading) | PM2.5 < 12 µg/m³ — good |
| Yellow (red+green, on a reading) | PM2.5 12–35 µg/m³ — moderate |
| Red (on a reading) | PM2.5 > 35 µg/m³ — high |
| 3× fast blue+red blink (boot, docked) | Voltage-blocked — docked and idle, but battery below 3.5V, deliberately not attempting WiFi |
| Slow blue blink (~1s cycle) | WiFi attempt actively in progress |
| Solid blue, 1s | MQTT just connected |
| 2× quick blue blink | WiFi attempt window expired without connecting — giving up until the next 15-min retry |

---

## Standard Workflows

### Before outdoor use
1. The device should already be powered on and running from the dock -- **do not switch the Power Switch off and on right before leaving** (that erases the clock; see "The Clock").
2. Confirm it has connected since it was last powered on: the `Air quality monitor online` line on the log dashboard, or the blue "connected" flash.
3. Unplug it and turn Intent ON — collection begins within 2 minutes. Leave the Power Switch alone.

### During use
- No action needed — the device duty-cycles automatically, charging (if plugged into a power bank or solar) doesn't interrupt anything.
- Watch the PM2.5 threshold LED for a quick at-a-glance air-quality read.

### Ending a session / uploading
1. Turn Intent OFF.
2. If not already connected to power, dock it (USB into TP4056).
3. Once battery is ≥3.5V, the device connects and replays automatically — no manual trigger needed.
4. **Leave it docked and on for at least 5 minutes, and don't touch the Power Switch.** If the run began from a cold boot the replay waits for the clock before it uploads, so the readings can take a few minutes to appear. Then confirm the run reached the Sheet (`air-quality-monitor` rows for the hike's time window). The log dashboard also shows the `intent_on` line (how many old lines were cleared or kept) and, if any, `Unresolved-time reading kept in log` lines.

### Storage
1. Turn Intent OFF.
2. Switch the Power Switch off (true zero-draw) — battery still charges normally if left plugged in.
3. When taking it out of storage, switch the Power Switch on **while docked**, leave Intent OFF, and wait for it to connect (that re-syncs the clock) before the next hike.

---

## Log Dashboard Messages

| Message | Category | Meaning |
|---|---|---|
| `Air quality monitor online - ESPHome ..., IP: ..., reset reason: ...` | System | Device booted and connected |
| `MQTT connected` / `MQTT disconnected` | MQTT | Broker connection state |
| `Replaying N buffered readings...` | System | Uploading buffered field data |
| `Buffered-data replay complete.` | System | All buffered data uploaded |
| `Replay deferred - battery X.XXV below 3.5V upload threshold, waiting for charge` | Alert | Normal — see Battery & Charging above, not an error |
| `Critical battery X.XXV - Measurement mode suspended until charge recovers` | Alert | Battery below 3.4V — sensor sampling paused until it recovers |
| `Heartbeat - uptime: Xh Ym, RSSI: ..., PM2.5: ..., VOC: ..., NOx: ..., batt: ...` | System | Alive, connected, 5-minute cadence |

---

## Data Pipeline

Readings publish to `jctsh/components/air-quality-monitor/data` (Environmental Data schema) whenever connected, or buffer to flash and replay per Upload Behavior above. Each row carries all 8 SEN55 measurements plus `battery_v` and `rssi_dbm` — no separate `lat`/`lon` (this device is not GPS-tracked the way hiking-monitor is).

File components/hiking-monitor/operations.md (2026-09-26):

# Hiking Monitor — Operations Guide

## Hardware Overview

| Component | Role |
|---|---|
| ESP32 + sensors | Reads temperature, humidity, pressure, UV index every 2 minutes |
| LiPo battery + TP4056+boost | Power system — boost converter outputs 5.7V directly to ESP32 VIN |
| Slide switch (GPIO27 signal) | Signals field mode — switch ON pulls GPIO27 LOW; not in power path |
| Dock detect (GPIO32 divider) | Detects USB charger connected; wakes ESP32 from deep sleep for upload |

---

## Powering On (Perfboard)
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

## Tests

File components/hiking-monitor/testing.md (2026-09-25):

# Hiking Monitor — Full End-to-End Test (Step 12)

## Prerequisites

All of the following must be confirmed before running this test:
- Steps 5–11 complete (sensors, display, onboard flash, power system, data pipeline)
- Device running from LiPo, connected to JCTnet1 WiFi
- Google Sheets "JCTsh Environmental Data" receiving rows
- Log dashboard at `http://pi1.local/` showing `hiking-monitor` entries

---

## Test Items

### 1 — Sensor Validation

**Check:** All four sensor values updating every 2 minutes in the MQTT data topic.

```
mosquitto_sub -h pi1.local -u hiking-monitor -P <password> -t "jctsh/components/hiking-monitor/data"
```

| Sensor | Expected (Tucson indoors) |
|---|---|
| `temp_f` | 70–115°F (note: ESP32 self-heating on breadboard; will improve on perfboard) |
| `humidity_pct` | 5–60% |
| `pressure_hpa` | 910–940 hPa (Tucson ~750m elevation) |
| `uv_index` | 0.00–1.00 indoors; rises toward window/sunlight |
| `battery_v` | 3.7–4.2V |
| `rssi_dbm` | negative value (e.g. -35 to -70 dBm) |

**Pass criteria:** All six fields present and plausible. No NaN values.

---

### 2 — Display Validation

**Check:** E-ink display shows all four fields in correct layout.

Expected display content:
```
[temp °F]        [humidity %]
P [=>|^|v]       UVI [value]
```

**Pass criteria:** Temp, humidity, pressure trend arrow, and UV index all visible. Display refreshes approximately every 2 minutes.

---

### 3 — Button Validation

**Superseded (2026-06-05):** Button removed. GPIO32 repurposed for dock detect. See test 10.

---

### 4 — Log Dashboard

**Check:** Log messages visible at `http://pi1.local/` under `hiking-monitor`.

Expected entries (most recent first):
- `Heartbeat - uptime: Xh Xm, RSSI: -XXdBm, temp: XX.X°F` — every 5 minutes
- `Hiking monitor online - ESPHome X.X.X, IP: 192.168.1.XXX` — on last boot
- `MQTT connected` — on last boot

**Pass criteria:** All three message types present. Heartbeat collapsing into single row with count.

---

### 5 — Heartbeat

**Check:** Heartbeat appearing every 5 minutes in log dashboard and on heartbeat topic.

```
mosquitto_sub -h pi1.local -u hiking-monitor -P <password> -t "jctsh/components/hiking-monitor/heartbeat"
```

**Pass criteria:** Heartbeat JSON appears within 5 minutes. Contains `uptime`, `rssi`, `temp` fields.

---

### 6 — Field Mode Simulation

This test confirms onboard flash logging and replay work correctly with original timestamps.

**Steps:**

1. Edit `secrets.yaml` — change `wifi_password` to a wrong value
2. Copy to `C:\esphome\hiking-monitor\` and OTA flash: `esphome run hiking-monitor.yaml`
3. Device will disconnect from WiFi (confirm: no new heartbeats in log dashboard)
4. Wait 10+ minutes (5+ readings logged at 2-minute intervals)
5. Restore correct `wifi_password` in `secrets.yaml`, copy and OTA flash again
6. On reconnect, confirm log dashboard shows:
   - `Replaying N hike readings...`
   - `Hike log replay complete.`
7. In Google Sheets, confirm replayed rows have:
   - `timestamp` = original logging time (not current time)
   - `rssi_dbm` = 0 (field-mode indicator)
   - `source` = `hiking-monitor`
   - `dew_point_f` and `heat_index_f` populated (computed by Node-RED on replay)

**Pass criteria:** At least 5 readings replayed. Timestamps match logging time, not replay time. `rssi_dbm = 0` in replayed rows.

---

### 7 — Google Sheets Validation

**Check:** Environmental Data sheet accumulating correct rows.

Open the [JCTsh Environmental Data spreadsheet](https://docs.google.com/spreadsheets/d/1zBzeLocOp4VNW99Neh6JKOW8WHQ1evW2-5HYKJP70_g/edit).

Confirm for recent rows:

| Column | Expected value |
|---|---|
| `source` | `hiking-monitor` |
| `lat` | (blank / null) |
| `lon` | (blank / null) |
| `temp_f` | plausible (70–115°F) |
| `humidity_pct` | plausible |
| `pressure_hpa` | ~910–940 |
| `dew_point_f` | populated (not blank) |
| `heat_index_f` | populated (not blank) |
| `battery_v` | 3.7–4.2V |
| `rssi_dbm` | negative for live readings; 0 for field-mode readings |

**Pass criteria:** All required columns populated. `dew_point_f` and `heat_index_f` not blank. `lat`/`lon` blank.

---

### 8 — Battery Validation

**Check:** `battery_v` in Sheets shows plausible value.

Already confirmed in Step 8 (3.85V). Re-confirm current value is still in range.

**Pass criteria:** `battery_v` between 3.5V and 4.2V.

---

### 9 — Power Cycle Test

**Check:** Device survives power cycle and resumes normal operation.

1. Log 2–3 readings in field mode (disconnect WiFi using wrong password OTA flash)
2. Disconnect LiPo — device powers off
3. Reconnect LiPo — device powers on
4. Restore WiFi credentials, OTA flash
5. Confirm on reconnect: SPIFFS log survived power cycle and readings replay

**Pass criteria:** Readings logged before power-off replay after power-on + WiFi reconnect. onboard flash/SPIFFS is non-volatile — data persists across power cycles.

---

### 10 — Power Switch and Upload Mode

**Check:** Switch OFF → deep sleep. USB connect (switch OFF) → auto-wake → upload mode, no data collection. USB remove → returns to sleep. Switch ON → wakes into hiking mode.

**Prerequisites:** LiPo charged. No USB connected to TP4056 at test start. Home WiFi in range.

**Part A — Switch OFF enters deep sleep**

1. Turn switch ON → confirm device boots, heartbeats appear in log dashboard every 5 minutes
2. Turn switch OFF → wait 6+ minutes
3. Confirm **no** heartbeats appear after switch-off (device is sleeping)

**Part B — USB auto-wake → upload mode**

4. Plug USB charger into TP4056 micro USB → wait up to 30 seconds
5. Confirm log dashboard shows: `Upload mode — USB connected, switch off`
6. If hike data is stored, confirm: `Replaying N hike readings...` then `Hike log replay complete.`
7. Wait one full 2-minute cycle — confirm **no** new data rows appear in Sheets (switch is OFF; no collection)
8. Confirm heartbeats appear while USB is connected and WiFi active

**Part C — USB remove → returns to sleep**

9. Unplug USB → wait 6+ minutes
10. Confirm **no** heartbeats appear after unplug (device returned to sleep)
11. Plug USB again → device wakes again (confirms it returned to sleep, not just WiFi dropout)
12. Unplug USB

**Part D — Switch ON → hiking mode**

13. Turn switch ON → confirm device wakes and connects to WiFi
14. Wait one full 2-minute cycle — confirm new data row appears in Sheets with `rssi_dbm ≠ 0`
15. Turn switch OFF → device enters deep sleep

**Pass criteria:**
- Switch OFF → no heartbeats within 6 minutes
- USB connect (switch OFF) → `Upload mode` log message; no new Sheets rows
- USB remove → no heartbeats within 6 minutes; re-plug wakes device again
- Switch ON → data rows resume in Sheets

---

### 11 — Field Session Start / End Event Detection

**Check:** Node-RED field session events flow fires correct log messages when rssi_dbm transitions between 0 and non-zero. Works for any sensor; tested here with hiking-monitor.

**Prerequisites:** `hiking-hike-events.flow.json` imported and deployed in Node-RED with broker selected. Test inject nodes visible in Node-RED editor.

**Steps (use inject nodes in Node-RED — run in order):**

1. Click `Test: home reading (rssi=-45)` → no event expected (initialises state)
2. Click `Test: field reading 1 — session start (rssi=0)` → log dashboard should show: `Field session started at 2026-06-07T15:00:00Z`
3. Click `Test: field reading 2 — mid-session (rssi=0)` → no event expected
4. Click `Test: home reading — session end (rssi=-31)` → log dashboard should show: `Field session ended at 2026-06-07T15:02:00Z`

**After test:** Reset function node context in Node-RED: hamburger menu → Context Data → select `hike-events-detect` node → delete `lastRssi_hiking-monitor` and `lastTs_hiking-monitor`.

**Pass criteria:** Session started fires once (on inject 2). No event on inject 3. Session ended fires with timestamp of last field reading (inject 3's ts, not inject 4's).

---

## Results

**Completed: 2026-06-12. All tests passed.**

| Test | Result | Notes |
|---|---|---|
| 1 — Sensor validation | PASS | temp_f, humidity_pct, pressure_hpa, uv_index, battery_v, rssi_dbm all present and plausible |
| 2 — Display validation | PASS | All four fields rendering correctly; refreshes every 2 minutes |
| 3 — Button validation | N/A | Button removed 2026-06-05; GPIO32 repurposed for dock detect (see test 10) |
| 4 — Log dashboard | PASS | Heartbeat, boot, and MQTT connected messages all visible |
| 5 — Heartbeat | PASS | Heartbeat appearing every 5 minutes |
| 6 — Field mode simulation | PASS | Readings replayed with original timestamps; rssi_dbm=0 in replayed rows. Bug found and fixed: SPIFFS remove() not persisting across power cuts caused duplicate replays. Fix: truncate before replay + size-based has_data() check. |
| 7 — Google Sheets validation | PASS | dew_point_f and heat_index_f populated; lat/lon blank; source=hiking-monitor |
| 8 — Battery validation | PASS | battery_v 3.85–4.08V across session; fully charged at start of Step 12 |
| 9 — Power cycle test | PASS | LiPo disconnected and reconnected; device rebooted and MQTT reconnected cleanly |
| 10 — Power switch and upload mode | PASS | Deep sleep working; upload mode auto-wake confirmed; switch ON/OFF controls all modes correctly. Bugs fixed: captive_portal was preventing deep sleep; on_connect sleep path incorrectly looped when USB connected. |
| 11 — Hike start/end event detection | PASS | Field session started/ended events fire correctly on rssi transitions; timestamps from sensor data not upload time. Flow in components/hiking-monitor/hiking-hike-events.flow.json. |

---

## Step 12 Findings

- **SPIFFS duplicate replay bug (fixed):** `remove()` on SPIFFS does not always persist to flash before a power cut. On next boot, the file reappears and replays again. Fix: `hike_log_clear()` now truncates to 0 bytes (fopen "w") instead of calling `remove()`; `hike_log_has_data()` now checks file size > 0. Replay also clears the log before the loop, not after — so a mid-replay power cut leaves an empty file, not a full one.
- **Loose BAT- wire caused power dropouts:** TP4056 BAT- (LiPo black wire) was not firmly seated on breadboard during testing — caused multiple unintended power cuts and triggered the duplicate replay bug. Reseat all TP4056 wires before perfboard build.
- **Google Sheets View tab:** A "View" tab was added to the Environmental Data spreadsheet. Uses ARRAYFORMULA to mirror Environmental Data with timestamps converted from UTC to MST (UTC-7, fixed offset — no DST in Arizona). The Apps Script writes only to Environmental Data; View is display-only.

---

## Known Behaviors

- **Temperature reads ~10°F high on breadboard** — ESP32 self-heating warms the BME280. Will improve on perfboard when BME280 is positioned away from ESP32.
- **UV index 0.00 indoors** — expected. Point at direct sunlight or sunny window to confirm sensor responds.
- **Pressure trend shows `=>` (steady) on boot** — no history yet. Arrow updates after ~30 minutes of readings.
- **`rssi_dbm = 0` in field-mode rows** — correct. Used to distinguish field-mode readings from live home-mode readings in Sheets analysis.
- **405 response from Apps Script** — Google redirects the POST and the redirect destination returns 405. The row IS appended. Node-RED treats 405 as success. This is expected behavior, not an error.

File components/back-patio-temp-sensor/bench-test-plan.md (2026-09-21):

# Back Patio Temp Sensor — Bench Test Plan (pre-flash)

**Covers the gap between "soldering is done" and `flashing.md`.** Every electrical check
below is derived from `wiring.md`'s connection tables — that doc is the authoritative
as-built wiring source; this one is the runnable worksheet for verifying it.

- **Before this doc:** `perfboard-layout.md` (assembly and soldering sequence)
- **After this doc:** `flashing.md`, then `testing.md` (post-flash, end-to-end)

**Status as of 2026-09-21:** soldering complete; BH1750 (light sensor) confirmed wired
correctly on a 5-pin header (VCC, GND, SCL, SDA, ADDR).

---

## The nine connections being verified

Straight from `wiring.md`. Everything in Sections 2–4 tests one of these, or the absence
of something that should not exist.

| # | From | To | Wire |
|---|---|---|---|
| 1 | BME280 (temp/humidity/pressure sensor) VCC | 3V3, pin 1 | Red |
| 2 | BME280 GND | GND, pin 38 | Black |
| 3 | BME280 SDA | GPIO21, pin 33 | Blue |
| 4 | BME280 SCL | GPIO22, pin 36 | Yellow |
| 5 | BH1750 (light sensor) VCC | 3V3, pin 1 | Red |
| 6 | BH1750 GND | GND, pin 38 | Black |
| 7 | BH1750 SDA | GPIO21, pin 33 | Blue |
| 8 | BH1750 SCL | GPIO22, pin 36 | Yellow |
| 9 | BH1750 ADDR | GND, pin 38 | Black |

ESP32 pin numbers per `ESP32-project-pins.md`: **viewed from the top**, component side up,
USB-C at the bottom, left pin 1 and right pin 38 at the top.

---

## Section 0 — Setup

- [ ] **Nothing inserted.** No ESP32 DevKitC-32 (microcontroller), no BME280, no BH1750.
      Sections 1–6 test the bare perfboard and its bridges only.
- [ ] Multimeter in continuity mode (audible beep).
- [ ] **Zero the meter:** touch probes together. Confirm it beeps and reads near 0 Ω.
      Record lead resistance: ______ Ω (typically 0.2–1.5). A good joint reads within
      about 1 Ω of this. If it does not beep probe-to-probe, nothing below is meaningful.
- [ ] Spare male header pins or solid-core wire offcuts on hand for probing sockets.

**Probing technique.** Female header sockets are recessed; a probe tip reads open on a
perfectly good joint. Drop a male pin into each socket and probe that. **Probe the socket,
not the solder blob on the back** — a cold joint reads fine from the back and open from
the front, and the front is the side the module actually contacts.

---

## Section 1 — Visual inspection

From `wiring.md`'s Pre-Flash Checklist. Do this before touching the meter; some faults are
faster to see than to measure.

- [ ] BME280 VCC → 3V3, pin 1 — **red** wire (not VIN, pin 19)
- [ ] BME280 GND → GND, pin 38 — **black**
- [ ] BME280 SDA → GPIO21, pin 33 — **blue**
- [ ] BME280 SCL → GPIO22, pin 36 — **yellow**
- [ ] BH1750 VCC → 3V3, pin 1 — **red**
- [ ] BH1750 GND → GND, pin 38 — **black**
- [ ] BH1750 SDA → GPIO21, pin 33 — **blue** (same rail as BME280 SDA)
- [ ] BH1750 SCL → GPIO22, pin 36 — **yellow** (same rail as BME280 SCL)
- [ ] BH1750 ADDR → GND, pin 38 — **black**
- [ ] No bare wire touching adjacent rows or pads
- [ ] **Nothing wired to pin 18** (non-functional as GND on this board batch, and almost
      certainly GPIO11/flash CMD — see `ESP32-project-pins.md`)
- [ ] No solder splash or whisker bridging neighbouring pads
- [ ] All joints shiny and concave — not dull grey blobs (cold joint) or balls sitting on
      top of the pad (no wetting)

---

## Section 2 — Power-rail isolation · DO FIRST

A 3.3V-to-GND short is the one defect that can damage the ESP32 DevKitC-32
(microcontroller) the instant USB is connected.

| Check | Expected | Result |
|---|---|---|
| 3V3 (pin 1) → GND (pin 38) | **No continuity** | |
| BME280 VCC socket → BME280 GND socket | **No continuity** | |
| BH1750 VCC socket → BH1750 GND socket | **No continuity** | |

> **Any beep here stops the build.** Clear the short before going further — do not
> continue to Section 3 "just to see."

---

## Section 3 — Continuity · should connect

| Check | Expected | Result |
|---|---|---|
| 1. BME280 VCC socket → 3V3 (pin 1) | Continuity | |
| 2. BME280 GND socket → GND (pin 38) | Continuity | |
| 3. BME280 SDA socket → GPIO21 (pin 33) | Continuity | |
| 4. BME280 SCL socket → GPIO22 (pin 36) | Continuity | |
| 5. BH1750 VCC socket → 3V3 (pin 1) | Continuity | |
| 6. BH1750 GND socket → GND (pin 38) | Continuity | |
| 7. BH1750 SDA socket → GPIO21 (pin 33) | Continuity | |
| 8. BH1750 SCL socket → GPIO22 (pin 36) | Continuity | |
| 9. BH1750 ADDR socket → GND (pin 38) | Continuity | |
| R1. BME280 SDA socket → BH1750 SDA socket | Continuity — shared rail intact | |
| R2. BME280 SCL socket → BH1750 SCL socket | Continuity — shared rail intact | |

**R1/R2 are not redundant.** Both sensors reach GPIO21/GPIO22 through one shared rail
(`wiring.md`). A break *between the two sensors* can still let checks 3/4/7/8 pass
individually while the bus is actually broken.

---

## Section 4 — Isolation · should NOT connect

| Check | Expected | Result |
|---|---|---|
| SDA rail → SCL rail | **No continuity** | |
| SDA rail → GND (pin 38) | **No continuity** | |
| SCL rail → GND (pin 38) | **No continuity** | |
| SDA rail → 3V3 (pin 1) | **No continuity** | |
| SCL rail → 3V3 (pin 1) | **No continuity** | |

SDA or SCL shorted to GND is the classic "sensor never appears on the bus" fault. Once
powered it is indistinguishable from a dead sensor — far cheaper to find here.

---

## Section 5 — Adjacent-pad bridge sweep

The most common perfboard defect, and **nothing in Sections 2–4 catches a bridge between
two unused pins.** Walk the meter down both 19-pin ESP32 header strips, probing each
socket against its immediate neighbour.

| Sweep | Pairs | Expected | Result |
|---|---|---|---|
| Left strip, pins 1↔2 through 18↔19 | 18 | **No continuity** on every pair | |
| Right strip, pins 20↔21 through 37↔38 | 18 | **No continuity** on every pair | |

**Zero exceptions — every one of the 36 pairs should read open.** Nothing on this build
bridges two adjacent sockets: the only multi-socket nets are GND (three wires all landing
on the pin 38 socket) and the SDA/SCL rails (pin 33 and pin 36, six sockets apart). Any
beep is a defect.

---

## Section 6 — Pin 18 confirmation

| Check | Expected | Result |
|---|---|---|
| Pin 18 socket → GND (pin 38) | **No continuity** | |
| Pin 18 socket → 3V3 (pin 1) | **No continuity** | |
| Pin 18 socket → SDA rail | **No continuity** | |
| Pin 18 socket → SCL rail | **No continuity** | |

Pin 18 should connect to nothing at all. A beep to GND here means a stray bridge on *your*
board — not the board-batch anomaly, which shows as the opposite: no continuity where the
silkscreen promises GND.

---

## Section 7 — Insert modules

Only once Sections 2–6 all pass.

- [ ] Insert ESP32 DevKitC-32 (microcontroller) into both 19-pin strips — press firmly and
      evenly; confirm no pin is folded under or missing its socket
- [ ] Insert BME280 (temp/humidity/pressure sensor) into its 4-pin header
- [ ] Insert BH1750 (light sensor) into its 5-pin header — confirm ADDR is the pin landing
      on the ADDR socket, not shifted by one position
- [ ] **Re-run Section 2's three short checks with modules seated.** A folded-under pin, or
      a module inserted one position off, creates a short that did not exist on the bare
      board. This is the single most valuable repeat check in this document.
- [ ] Attach M3 10mm brass standoffs to the four corner mounting holes

---

## Section 8 — First power-on smoke test

Still before flashing. USB-C to a **computer**, not a wall charger.

- [ ] Meter to **DC volts** (not continuity) before applying power
- [ ] Connect USB-C. Watch the first 5 seconds:
  - [ ] No smoke, no smell, no audible pop
  - [ ] Nothing hot to a fingertip touch — ESP32 regulator, BME280, BH1750
  - [ ] ESP32 onboard power LED lit
- [ ] Measure 3V3 (pin 1) → GND (pin 38): expect **3.2–3.4 V**. Actual: ______ V
- [ ] Measure BME280 VCC socket → GND (pin 38): same reading. Actual: ______ V
- [ ] Measure BH1750 VCC socket → GND (pin 38): same reading. Actual: ______ V

> **Anything hot, or 3V3 below ~3.0 V or above ~3.5 V — unplug immediately** and re-run
> Section 2. A sagging rail usually means a partial short pulling current.

- [x] Confirm the board enumerates on the computer (a new COM port appears) — this
      confirms the CP2102 USB-serial bridge and is a prerequisite for `flashing.md`.
      **2026-09-21: enumerated as COM7** (`Silicon Labs CP210x USB to UART Bridge`,
      VID_10C4/PID_EA60). Verified from the Windows side with
      `Get-CimInstance Win32_PnPEntity | Where-Object { $_.Name -match 'COM\d+' }` —
      the four `Standard Serial over Bluetooth link` entries are not physical ports.

---

## Results

Run 1 — 2026-09-21, Joseph at the bench, walked through section by section.

| Section | Result | Notes |
|---|---|---|
| 1. Visual inspection | Skipped | Covered by the meter sections; Joseph inspected while soldering |
| 2. Power-rail isolation | **Pass** | All 3 open |
| 3. Continuity (9 + 2 rail) | **Pass** | All 11 beeped, including R1/R2 shared-rail integrity |
| 4. Isolation (5) | **Pass** | All 5 open |
| 5. Adjacent-pad sweep (36) | **Pass** | All 36 pairs open |
| 6. Pin 18 | **Pass** | Isolated from GND, 3V3, SDA, SCL |
| 7. Insert modules + re-check | **Pass** | All 3 short checks still open with ESP32/BME280/BH1750 seated |
| 8. Power-on smoke test | **Pass** | 3.3 V at all three points (3V3 pin 1, BME280 VCC, BH1750 VCC). No heat, no smell, power LED lit. Enumerated as **COM7** — `Silicon Labs CP210x USB to UART Bridge`, VID_10C4/PID_EA60 |

**All sections pass. Board cleared for `flashing.md`.** Port for the first USB flash: **COM7**.

---

## Build and flash record — 2026-09-21

Captured so a later "is the running binary actually the one we built?" question has an
answer, rather than being re-derived. `esphome upload` can silently flash a stale binary;
the check is that the device's own boot log reports the same `build_time_str` below.

| Item | Value |
|---|---|
| ESPHome version | 2026.4.5 |
| `config_hash` | `0xf32d00da` |
| `build_time_str` | `2026-09-21 16:11:06 -0700` |
| Compile | Success, exit 0, 494.42 s — no warnings or errors |
| `firmware.factory.bin` | 1,064,208 bytes, written 16:19 MST |
| `firmware.ota.bin` | 998,672 bytes, written 16:19 MST |
| First flash | USB, COM7, `esphome upload --device COM7` |
| Flash result | Success — 998,672 bytes at `0x10000`, plus bootloader/partition/OTA-data regions. **Hash of data verified** on every region. Hard reset via RTS. |

**Verified 2026-09-21 16:24 MST — binary is fresh.** Device boot log:
`ESPHome version 2026.4.5 compiled on 2026-09-21 16:11:06 -0700`, an exact match for the
compile's `build_time_str`. No stale-upload problem.

### First-boot results

| Subsystem | Result |
|---|---|
| WiFi | Connected — `JCTnet1` |
| MQTT | Connected — broker accepted the new `back-patio-temp-sensor` account |
| safe_mode | Boot-loop counter reset — clean boot |
| BH1750 (light sensor) | **Working** — publishing illuminance (332.1, 330.6 lx) |
| BME280 (temp/humidity/pressure sensor) | **FAILED** — `Wrong chip ID or no response` |

**The BME280 in the socket is one of the counterfeit BMP280s** (Joseph confirmed, 2026-09-21)
— from Bin B3, not Bag 3. Not a build defect: BH1750 shares SDA (pin 33), SCL (pin 36),
3V3 (pin 1) and GND (pin 38) with it and works, which proves the bus, the rails, and every
solder joint on the shared path. The perfboard is good.

ESPHome's `bme280_i2c` platform reads the chip-ID register and refuses anything that is not
`0x60`; a BMP280 reports `0x58`, so the component is marked FAILED and publishes nothing —
not even the temperature and pressure the BMP280 can actually measure. **This is the
counterfeit detector `parts-list.md` predicted, working exactly as intended.**

**Resolution:** genuine BME280 ordered 2026-09-21. The swap is drop-in — same pinout, same
`0x76` address — so it needs no firmware change and no reflash, just reseat and power-cycle.

**Diagnostic note for next time:** `logger: level: INFO` suppresses CONFIG-level output, so
the `i2c: scan: true` results never appear in the log. Raise to `DEBUG` if an address-level
answer is ever needed.

**All eight pass → proceed to `flashing.md`.**

---

## Failure triage

| Symptom | Most likely cause | Next step |
|---|---|---|
| No beep on a Section 3 check | Cold joint, or probing the back instead of the socket | Re-probe from the socket with a male pin; reflow the joint if still open |
| Beep on a Section 2 check | Solder bridge between adjacent pads, or a wire stripped too far | Inspect under magnification along the relevant rail |
| R1 or R2 fails but 3/4/7/8 pass | Break in the shared SDA/SCL rail between the two sensors | Inspect the rail bridge on the back of the board |
| Section 5 beep between two unused pins | Solder bridge on the ESP32 header strip | Wick and reflow both pads |
| Section 2 passes bare but fails after insertion | Folded-under module pin, or module off by one position | Remove, straighten pins, confirm alignment, re-seat |
| 3V3 reads low under power | Partial short pulling current | Unplug, re-run Section 2 |
| No COM port appears | Charge-only USB cable, or missing CP2102 driver | Try a known data cable first — this is the common one |

---

## Notes / observations

Record anything unexpected here as it happens, not afterwards — deviations from the plan
get documented during the work (`JCTsh-Operating-System.md`, Note on Build). Anything
learned that generalizes belongs in `JCTsh-Build-Standards.md` at Reflection.

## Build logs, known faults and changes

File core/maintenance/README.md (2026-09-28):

# core/maintenance — Scheduled Maintenance & Update Checks

systemd units and their Python scripts for scheduled maintenance work across the Pi and
M8: OS/firmware/container update checks, scheduled reboots with coordinated
pre/post-reboot notifications, backups, and image pulls. Deployed to `/usr/local/bin/`
on whichever host each unit's `.service` targets (see each unit's `ExecStart`) — check
`network/jctsh-network.md`'s Scheduled Maintenance Windows table before adding a new recurring
job here (`JCTsh-Build-Standards.md` §9.5, ≥1 hour clearance from other jobs).

**Status:** Production — every unit here is a currently-running scheduled job on the Pi
and/or M8.

---

## Update Checks

Notify-only (never auto-apply) — each posts an available-update finding to the log
dashboard and, via `open_kanban_pr.py` (CARD-0128), opens a placeholder PR against
`tos/kanban-board.md`.

| File | Checks |
|---|---|
| `container_update_check.py` | Shared library (`check_services()`) — generic GitHub-Releases-API update check for any Docker container, per `JCTsh-Build-Standards.md` §9.7. Per-host wrapper scripts (`hosts/m8/container-update-check.py`, `core/homeassistant/container-update-check.py`) import this and declare their own `SERVICES` list. `SERVICES` now also covers `ring-mqtt`, `matter-server`, and Immich's `redis` sidecar (CARD-0344) — `immich_postgres` deliberately excluded, its `immich-app/base-images` source repo publishes no GitHub releases to diff against. |
| `container-update-check-m8.service`/`.timer`, `container-update-check-pi.service`/`.timer` | Run each host's own wrapper script daily |
| `pi-maintenance-check.py` | Pi OS/firmware — apt-upgradable packages, stale running kernel (CARD-0125, `maintenance-check.py`'s Pi sibling; the M8-side script itself lives in `hosts/m8/`). Tailscale is covered here (and by `hosts/m8/maintenance-check.py` on the M8) as an ordinary apt package — verified live 2026-09-27 (CARD-0344), no separate check needed. |
| `immich-update-check.service`/`.timer` | Runs `components/photo-server/immich-update-check.py` — Immich exposes its own `/api/server/version-check` API directly, more authoritative than a GitHub tag, so it doesn't use `container_update_check.py`'s generic path |
| `node_red_update_check.py`/`.service`/`.timer` | CARD-0344, Pi only, daily 10:00 AM. `npm outdated --json` against both scopes: Node-RED itself (`npm install -g`, invisible to the apt check) and its palette nodes (`node-red-node-*`/`node-red-contrib-*`, local to `/home/pi/.node-red`'s own `package.json`). Same notify-only/7-day-throttle pattern as the container checks, just without `container_update_check.py`'s Docker/GitHub-Releases assumptions. |
| `esphome_check.py`/`.service`/`.timer` | CARD-0344, Pi only, daily 11:00 AM. Two independent checks: (1) parses each of the 6 field devices' most recent "online - ESPHome X" log line and Alerts (7-day throttle, opens a PR) if any device has drifted off the hand-maintained `PINNED_VERSION` constant — the real CARD-0333/0335-class risk; (2) checks ESPHome's GitHub Releases API against that same constant, logging (informational only, 30-day throttle, **no PR**) when a newer release exists — the pin is deliberate, so this deliberately doesn't escalate the way every other check here does. `PINNED_VERSION` must be updated by hand if the workstation's actual pinned pip version ever changes; nothing checks that they still agree. |

## Config Drift Check

Notify-only (CARD-0328) — detects when a live Pi file has drifted from its version-controlled copy on
GitHub `main`, the exact failure root `CLAUDE.md`'s "repo is the source of truth" rule had nothing
guarding. Same reporting path as the update checks: an `Alert` to the log dashboard plus a kanban PR via
`open_kanban_pr.py`. Never writes to the repo or the Pi, and doesn't decide which side is right.

| File | Purpose |
|---|---|
| `config-drift-check.py`/`.service`/`.timer` | Daily 9:00 AM on the Pi. Compares `core/mqtt/*`, `core/node-red/{settings.js,core.flow.json,watchdog.flow.json}` and `core/homeassistant/*` (its `MANIFEST` list is the authoritative file-to-live-path mapping) against `main`. |

- **Node-RED** is compared node-by-node by id against the merged live `flows.json` (editor x/y positions
  ignored), and live tabs/config nodes that no repo flow file contains are reported too.
- **Secrets** (bcrypt hashes, `credentialSecret`/password/token-style values) are masked in every diff;
  a change confined to one is reported as "content withheld".
- **Throttle:** the same drift re-notifies at most every 7 days; a clean run resets it.
- **Run it by hand** (prints findings, sends nothing): `sudo python3 /usr/local/bin/config-drift-check.py --dry-run`
## Reboots

| File | Purpose |
|---|---|
| `scheduled-reboot-pi.service`/`.timer`, `scheduled-reboot-m8.service`/`.timer` | Weekly scheduled reboot per host, staggered (the M8's heartbeat publishes to the Pi's broker, so overlapping reboots would produce a false "down" reading) — publishes a "Scheduled reboot about to occur" log line before rebooting; the Pi's variant also snapshots the journal first (`journal-snapshot.service`, since `systemd-journald` uses volatile storage — CARD-0246) |
| `reboot-complete-pi.service`, `reboot-complete-m8.service` | Publishes "Boot complete." on next boot after a scheduled reboot |
| `reboot-health-check.py`/`.service` | Post-reboot health check (CARD-0158) — runs once at boot, oneshot |

## Backup

| File | Purpose |
|---|---|
| `pi1-backup-to-m8.py`/`.service`/`.timer` | Weekly backup of the Pi's HA + Mosquitto state to the M8 (CARD-0177) — the disaster-recovery gap CARD-0172's audit found |

## Image Pull

| File | Purpose |
|---|---|
| `pi-image-pull.py` | `ionice`-wrapped `ctr`-based Docker/containerd image pull for the Pi (CARD-0269/CARD-0268) — scheduled, not manual, since a plain `docker pull` can starve HA's own I/O on the Pi's shared USB 2.0 bus |

## Heartbeat

| File | Purpose |
|---|---|
| `pi-heartbeat.py`/`.service`/`.timer` | Publishes the Pi's own container-health heartbeat (extend the script's `CONTAINERS` list for more than `homeassistant`) |

**Adding a file to the drift check:** add a `(repo path, live path, "file")` row to `MANIFEST` in
`config-drift-check.py`, redeploy the script, and confirm `--dry-run` still says `No drift.` A version-controlled copy
that isn't in `MANIFEST` is invisible to the check. The check also watches its own script and units, so redeploying
it means pushing the new version to `main` *first*, or it flags itself. Only `/etc/mosquitto/conf.d/*.conf` is
scanned for live-only files; add a `LIVE_ONLY_DIRS` row to cover another directory.

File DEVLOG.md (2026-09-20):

# JCTsh DEVLOG

## 2026-07-13
Closed CARD-0003 (TLS for Mosquitto, port 8883) — Phases D and E, the last two of five.
Phase D (hiking-monitor OTA reflash) had been blocked on the device being off; it came
back online and unblocked the reflash. Two real snags along the way: `esphome run` from
the repo path failed with "Detected a whitespace character in project paths" (same class
of issue as the 2026-05-20 garage-radar build), worked around via the existing
whitespace-free mirror at `C:\esphome\hiking-monitor\` — but that mirror turned out to be
stale, missing the TLS config/CA-cert changes entirely, and had to be re-synced from the
repo copies of `hiking-monitor.yaml`/`secrets.yaml` first or it would have silently pushed
the old plaintext-1883 config back onto the device. Also hit a locked leftover file in
`.esphome/build/hiking-monitor/.pioenvs` from an earlier interrupted build, blocking the
clean step until manually removed. OTA succeeded; verified via the live Mosquitto log on
the Pi that `hiking-monitor-04b24797df2c`'s old plaintext-1883 session timed out and a new
TLS session on 8883 came up immediately after, staying connected with no disconnects.

Phase E: updated `network/jctsh-network.md`, `components/hiking-monitor/wifi-config.md`,
`credentials.local.md`, and `jctsh-security-hardening.md` (dated superseded-note on the
original port-inventory finding, history kept intact) to reflect 8883/TLS as the
roaming-device path. Confirmed via `p-w-firefly/heartbeat.md` that coachproxyos reaches
MQTT over Tailscale, not the DuckDNS/port-forward path, so retiring the old 1883 forward
had no impact there. Joseph removed the old `1883 → 192.168.1.117` router-forward rule
manually (router admin SPA still isn't drivable via browser automation, same as Phase C).
Verified the cutover from the LAN against the public `jctsh.duckdns.org` hostname (this
router does hairpin NAT, so a LAN-sourced test reflects the real forwarding table): port
1883 now refuses connections, port 8883 still accepts them. Card closed.

## 2026-07-10 (continued, part 4)
Full audit of `photo-server-claude-code-instructions.md` plus `backlog.md`/`setup.md`/
`migration.md` against actual live state, prompted by "what else is there for
photo-server?" after the drive-swap saga closed out. Found two cards (CARD-0042, CARD-0043)
that were left paused mid-fix from 2026-07-09 with explicit "don't close until" conditions —
checked all of them live against the M8: `thumbnailGeneration` and `metadataExtraction`
queues both fully drained (0 waiting/active/failed), a fresh 150-asset sample of Robin's
library showed 0% null-width and 0% broken image thumbnails (matching Joseph's baseline),
and the specific `IMG_20260625_165423.heic` asset that originally surfaced CARD-0043 now has
real width/height/orientation and loads correctly. Closed both cards.

One side-finding during the thumbnail re-check: 10 of 150 sampled assets were `.MP.mp4`
files (Pixel Motion Photo video sidecars) still 404ing on `/thumbnail` — investigated before
assuming regression, confirmed these are `visibility: hidden` linked video components that
Immich never serves a thumbnail for directly; the paired still-image asset each one links to
via `livePhotoVideoId` has its own working thumbnail, which is what actually displays. Normal
Immich behavior, not a bug.

Also confirmed live: both phones (Joseph's Pixel 10 Pro XL, Robin's Pixel 7) are actively
syncing new photos as of the last 24 hours — Step 10's "report back once confirmed" had never
actually been closed out in `setup.md`, just implicitly assumed true. Updated `setup.md` to
reflect this and to replace its stale "Known Deviation Still Outstanding" note (which still
described CARD-0030 as pending — it's been resolved since earlier today) with a pointer to
the current split-backup state. Also noticed CARD-0047's update-check system caught a real
v3.0.1→v3.0.2 Immich version gap and fired its first live notification today at 13:56 UTC —
first real-world confirmation that system works end-to-end, not just in testing.

Remaining photo-server backlog after this pass, all deliberately deferred rather than
outstanding: CARD-0041 (disk capacity growth analysis — waiting for steady-state backup
cadence), CARD-0028 (optional automated quality scan — waiting on Joseph's interest), and
CARD-0031 (coachproxyos heartbeat fix — blocked on RV Pi being reachable, not photo-server
itself). No open, actionable photo-server work remains.

## 2026-07-10 (continued, part 3)
Closed out CARD-0040 and CARD-0046, the two remaining loose ends from the day's drive-swap
saga. CARD-0040: ran the actual `photo-library-backup.sh` script end-to-end (not the manual
isolated rsync calls used while debugging) now that both accounts are fully synced —
confirmed both `"Backup starting."` and `"Backup complete."` fire correctly on the
dashboard, with zero errors on either job. CARD-0046: extended
`photo-server-heartbeat.py`'s storage check to also probe both backup drives directly
(plain host file I/O, not `docker exec`, since Immich never touches those mounts) —
live-tested with the same safe `mount -o remount,ro` technique used for the original
CARD-0032 test, both drives correctly identified by name when degraded, both recovered
cleanly. Closes the exact gap that let Momentus's real hardware failure earlier the same
day go undetected for over 2 hours.

## 2026-07-10 (continued, part 2)
Two more real problems surfaced and fixed following the drive-swap incident, both
discovered because Joseph noticed something wrong in the actual Immich UI rather than a
dashboard alert.

**"Error loading image" on both accounts, thumbnails and full images.** Initially
misdiagnosed — the primary library's storage-health check was firing real recurring
`Alert`s every 30-minute cycle for 2+ hours (06:34, 07:04, 07:34, 08:34), and the first
theory was I/O contention from the actively-running backup rsync, so the backup got killed
to relieve load. That didn't fix it. The actual cause: the `immich_server` container's bind
mount had gone stale after all the remounting earlier (read-only, I/O errors, `sda`→`sdd`
device path change) — confirmed by finding a "missing" asset's file genuinely present on
disk with correct content, ruling out real data loss. `docker compose restart` fixed it
immediately; every previously-404ing asset came back to `200` on both accounts. Runbook
note added to `heartbeat.md`: recurring storage alerts after a remount event mean check the
container's actual data access, not just the host mount — a clean host mount doesn't
guarantee the container is looking at it correctly.

**Momentus never actually got cleaned up, across two failed attempts.** Per Joseph's
request, tried getting Robin's backup job running in isolation to free space via
`rsync --delete`. First attempt: added `--delete-before` (deletions happen incrementally
by directory-walk order with plain `--delete`, and `backups/` — walked before the per-user
dirs where the real deletions live — kept failing on a new file write before ever reaching
them; `--delete-before` does all deletions up front). Still failed, disk usage unchanged.
Second, actual fix: `--delete-excluded` — none of rsync's `--delete*` variants touch files
matched by `--exclude` by default (a protective default against an exclude rule
accidentally wiping data), so Joseph's excluded files had just been sitting on Momentus the
whole time regardless of delete timing. With both flags, Robin's job dropped Momentus from
556G to 207G cleanly with zero errors, then Joseph's interrupted job (stopped mid-transfer
at 47G during the earlier kill) was resumed with the corrected script.

## 2026-07-10 (continued)
Added a daily Immich update-availability check (CARD-0047), prompted by Joseph noticing an
update in the web UI and asking how to manage this going forward. Decided against
auto-updating unattended — this Immich instance has already surfaced real bugs in a single
patch version this week alone, and the data at stake (family photos) doesn't justify the
risk. Built the same notify-via-MQTT-dashboard pattern used for reboots (CARD-0036) and
backups (CARD-0040): a systemd timer checks `/api/server/version` against
`/api/server/version-check` daily and publishes a dashboard message when they differ, with
a state file to avoid re-notifying daily about the same pending update. First deploy
crashed on the state-file write (tried `/etc/jctsh/`, not writable by `jct` — moved to
`/home/jct/.jctsh/`), fixed and verified live: notified correctly for v3.0.2, then
correctly stayed silent on a repeat run. Actual updates remain a manual, deliberate step.

## 2026-07-10
Backup drive capacity crisis and split-by-account fix. The overnight backup verification
run (CARD-0030) failed with `No space left on device` — the primary library had grown to
624GB, past what Momentus (640GB nominal, 586GB usable) could ever hold, not just a slow
first run as assumed. Fix required a second backup drive.

Connecting it went sideways twice: first grabbed the wrong spare (WD 750GB instead of the
intended Seagate Expansion 1TB — the two look similar, always check the P/N label first),
and discovered neither spare was actually blank (both carry a leftover vfat+ext3+swap
partition layout from prior use). Worse, the drive-swapping physically jostled Momentus's
connector, causing a real kernel-level failure (`dmesg`: "device offline error", "Buffer
I/O error", "JBD2: I/O error when updating journal superblock", forced unmount) — and
separately, the primary library briefly went read-only during the same window. Both
recovered cleanly on `mount -a` with no lasting damage. Neither incident got real-time
dashboard visibility: the primary library's blip resolved faster than the 30-minute
heartbeat interval could catch it (not a bug, just polling-interval math), but Momentus's
failure exposed a genuine gap — CARD-0032's storage-health check only covers the primary
library, never either backup drive. Filed as CARD-0046.

Formatted the (now correctly identified) Seagate 1TB drive ext4, mounted at
`/mnt/photo-library-backup-joseph` via UUID with `nofail`, same pattern as the other two
drives. Split `photo-library-backup.sh` into two `rsync` invocations per run, filtered by
owner UUID (each destination excludes the *other* account's UUID within the per-user
`upload`/`thumbs`/`encoded-video` trees, so any future per-user directory Immich adds is
included automatically) — Joseph's larger, faster-growing library (403GB) goes to the new
1TB drive (~467GB headroom), Robin's (187GB) stays on Momentus (~400GB headroom). Chose
this over pooling both drives into one LVM volume, which would add real complexity without
adding redundancy — a failure on either physical drive loses that portion of a pooled
volume just the same as a standalone one. Shared non-per-user data (`backups/`, the ~2.2GB
Postgres DB dump directory) goes to both destinations since it isn't per-account and is
small. Deployed and running as of this entry — not yet verified complete.

## 2026-07-09 (continued, part 3)
Completed photo-server's build Step 18 (harvest step) — the last remaining step in the
instructions doc, found by re-auditing the whole doc against actual state rather than
trusting it was done. Proposed and, after Joseph's review, applied JCTsh-Build-Standards.md
v1.13's new §9 Non-ESP32 / Docker-Based Component Standards: the five candidates the
instructions doc had originally anticipated (Docker DNS pinning, UUID storage mounts,
incremental rsync backup, bus-powered drive preference — folded into §9.2) plus two more
that only became obvious from this build's own operational work rather than the original
plan: §9.4 dashboard visibility for scheduled/background jobs (the MQTT start/complete
message pattern, independently reinvented twice in this build for reboots and backups,
which is what made it worth promoting to a standard) and §9.6 detached remote job execution
(nohup + disown, always verify via ps aux on the remote host — a lesson learned the hard
way during the original Takeout migration's duplicate-mv race).

## 2026-07-09 (continued, part 2)
photo-server documentation catch-up (Steps 15-17 of the build instructions, long overdue)
plus CARD-0030 execution. Installed Node.js (Step 15, was never done). Wrote the 6 missing
Step 16 docs (README.md, docker-compose.yml, .env.example, setup.md, network.md,
backup.md) — deletion-log-setup.md skipped, Joseph moved that step to photo-tv-display's
scope, and Step 13 (face naming) marked N/A, decided "catch as catch can" rather than a
tracked task. Step 17: added photo-server to root README's component table, fixed a stale
parts-inventory note that still said "OS to be replaced" a week after Ubuntu had been
running, added a Storage section for the two USB HDDs + spares.

CARD-0030: with CARD-0039 having already done a far more rigorous completeness check than
the original "spot-check before deleting" plan called for, deleted both Takeout zip
staging locations (818GB reclaimed — Momentus 100%→19% used, NVMe root 87%→5%), re-enabled
the weekly backup cron, kicked off a manual verification run (still in progress — first
run is slow, reconciling a destination that previously held zip staging data instead of
real backups; future weekly runs should be fast since rsync is incremental).

Also added a consolidated "Scheduled Maintenance Windows" table to network/jctsh-network.md
(prompted by realizing KeepConnect's router reboot, now landing Wednesday 3am, was never
cross-referenced against the Pi/M8 reboot and backup schedule) and MQTT dashboard
visibility for backup runs (CARD-0040, same "Backup starting."/"Backup complete." pattern
as CARD-0036's reboot notifications) — not yet live-verified since the first post-cleanup
backup run was already in progress when the updated script was deployed.

## 2026-07-09 (continued)
Closed CARD-0039: re-ran `immich-go` for real (not `--dry-run`) against every retained
Takeout zip for both accounts, prompted by CARD-0037 raising doubt about whether this same
chaotic import had also dropped raw asset uploads, not just background ML jobs. Launched
fully detached (`nohup ... & disown` directly on the M8) so it survived the home network
being down for part of the run. Found 3,433 assets genuinely missing and uploaded them —
58 (Joseph, backup zips), 119 (Joseph, NVMe zips), 3,256 (Robin) — zero errors, single
clean pass, no restarts needed this time. Surprising part: Robin's gap was by far the
largest despite her original import being the "clean" one with no crashes, meaning the
missing-asset problem (like CARD-0037's ML-processing gap) wasn't caused solely by Joseph's
restart history — something shared between both imports is the more likely cause, not
pinned down further since re-running was sufficient to fix it regardless. Full writeup in
`components/m8/migration.md` and `backlog.md` CARD-0039.

## 2026-07-09
Closed CARD-0037: Immich ML processing (face detection/recognition, CLIP smart search, OCR,
duplicate detection) had never run on a large fraction of both Joseph's and Robin's
libraries — found by chasing down Joseph's "most photos don't show identified people"
question through the API rather than guessing, and confirmed definitively via a duplicate
photo pair where one copy had 7 detected faces and its exact twin had zero. Checking
Robin's library too (96% zero-face rate, clean import, no crashes) ruled out the original
5-restart-import theory and showed the gap was server-wide, not import-specific.

Fix was to trigger all five affected jobs via the admin job-control API — Immich has no
dry-run, so starting each job doubled as both the diagnostic (revealing real backlogs:
~140K faces, 33K duplicates, ~17K each for smart search/OCR) and the fix itself. Verified
CPU-bound via `vmstat` (not I/O-bound) before running all five concurrently. Ran overnight
into a home-internet outage (unrelated — the jobs run locally on the M8, unaffected).
Confirmed complete 2026-07-09: all queues drained, zero failures, M8 uptime showed it never
rebooted mid-run. People clusters grew 2,626 → 3,331. Full writeup in `backlog.md` CARD-0037.

Also documented the home router (TP-Link Archer AXE75, 192.168.1.1) in `network/jctsh-network.md`
and `ENVIRONMENT.md` — it had never been added despite being the gateway every other device
depends on, and despite `network/keepconnect.md` already referencing it extensively.

## 2026-07-08 (continued, part 3)
Closed the actual CARD-0032 monitoring gap and live-tested CARD-0029 in the same session.
`photo-server-heartbeat.py` now writes/reads/removes a marker file inside the
`immich_server` container's own `/data/upload` on every run, catching a broken bind mount
directly instead of trusting Docker's health check (which only pings the API). Live-tested
both degraded paths for real, now that the Immich migration is done and it's safe to:
container-down (`docker stop immich_redis`) produced the expected non-collapsing Alert row,
and a storage failure — reproduced via `mount -o remount,ro /mnt/photo-library` rather than
physically pulling the drive — produced `Alert - storage:...Read-only file system`, exactly
reproducing the original incident's failure mode. First attempt to simulate the storage
failure (`chmod 555` on the host-side upload directory) silently failed to trigger anything,
because the Immich container runs as root and root ignores POSIX permission bits — a
read-only remount enforces at the VFS level instead and actually worked. Both cards moved
to Done; full writeup in `components/m8/heartbeat.md`.

## 2026-07-08 (continued, part 2)
Added dashboard visibility for the CARD-0035 scheduled reboots (CARD-0036). Previously the
only way to confirm a reboot happened and succeeded was SSHing in and checking
`systemctl`/`docker ps` manually. Now `scheduled-reboot.service` publishes "Scheduled
reboot about to occur." right before rebooting, and a new `reboot-complete.service`
(runs on every boot) publishes "Boot complete." once the broker is reachable — both land
on the log dashboard under the same component identity as each host's existing heartbeat
(`jctsh-core` for the Pi, `photo-server` for the M8), reusing the existing MQTT accounts
rather than creating new ones. Had to split the previously-shared `scheduled-reboot.service`
into per-host versions (`scheduled-reboot-pi.service` / `scheduled-reboot-m8.service`)
since the broker address, credentials file, and topic now differ between the two hosts.
M8 needed `mosquitto-clients` installed (apt) since it only had the Python `paho-mqtt`
library, not the CLI. Verified live on both hosts via manual `systemctl start
reboot-complete.service` — confirmed on `/data` (live) and `/log` (persisted, after the
global `_pending` slot flushed on the next distinct message).

## 2026-07-08 (continued)
Added weekly scheduled reboot for the Pi and M8 photo-server (CARD-0035), prompted by
the KeepConnect outlet reconfiguration work. `core/maintenance/scheduled-reboot.service`
(`/sbin/reboot`) + per-host timers, deployed as systemd units: Pi Monday 3:00 AM, M8
Monday 4:00 AM. The one-hour stagger matters — the M8's heartbeat script publishes to
the Pi's Mosquitto broker, so an overlapping reboot would read as a false M8-down alert
instead of the Pi just being mid-reboot. Deliberately not synchronized to KeepConnect's
own weekly router reset: that schedule has drifted off its original Wednesday setting,
most likely because its 7-day timer restarts from any reset (scheduled or
outage-triggered) rather than a fixed weekday, so there's nothing stable to sync against
— and a router reboot's brief network blip doesn't meaningfully interact with either
host's own reboot anyway. `Persistent=true` on both timers so a missed window (host off
at 3/4 AM) fires on next boot instead of skipping the week. Verified live via
`systemctl list-timers` on both hosts.

## 2026-07-08
Documented KeepConnect router rebooter (CARD-0033). Not a JCTsh component — a
standalone Johnson Creative device (KeepConnect-27F8) that power-cycles the
router/modem on internet-loss detection. New `network/keepconnect.md` covers
full config: monitor mode set to "Require Full TCP/HTTPS Success" (switched from
vendor Roundtrip mode to avoid depending on Johnson Creative's own server uptime),
distinct primary/backup test domains (google.com / cloudflare.com), and a 4-minute
post-reset reconnect wait (raised from the 3-minute default to give the modem
headroom for DOCSIS ranging). Physically scoped to the router's own surge-protector
outlet only — the Immich Pi and SmartThings hub were moved to a separate always-on
outlet so router-triggered power cycling can't corrupt the Immich Postgres DB
mid-write or force a Zigbee/Z-Wave mesh rebuild on the hub. Linked from
`network/jctsh-network.md` and `ENVIRONMENT.md`. Open item carried forward: a clean
scheduled `shutdown -r` cron for the Pi/Immich stack, independent of power-strip
cycling.

## 2026-05-16
Restructured Salt Sensor project into JCTsh smart home monorepo. Salt Sensor
becomes first component under jctsh/components/. Centralized Python log server
added to jctsh/core/logging/, served at http://pi1.local/. ESP web server
removed; log messages now published via MQTT to jctsh/sensors/salt-sensor/log.
MQTT topics renamed from saltlevel/* to jctsh/sensors/salt-sensor/*. Node-RED
flow split into core.flow.json (broker) and salt-sensor.flow.json (sensor logic).
Test mode loop bug fixed — test sequence now runs once through WARNING then CRITICAL
instead of cycling indefinitely.

End-to-end verification completed. Fixed log_server.py missing MQTT credentials
(MQTT_USER/MQTT_PASS + username_pw_set) — broker requires auth. Sketch moved into
matching subfolder (Arduino IDE requirement). Confirmed: ESP publishes to new topics,
Node-RED responds with status, log dashboard displays messages, Pi reboot survival
verified. JCTsh.local mDNS alias closed out — Avahi CNAME not supported on this Pi;
address record causes local name collision; cosmetic value not worth the complexity.
Use http://pi1.local/ for the dashboard.

Added hourly watchdog heartbeat to log_server.py. Publishes
{"component":"jctsh-core","category":"System","message":"Watchdog: alive."} to
jctsh/core/log-server/log every hour — confirms log server and MQTT broker are alive
between 12-hour sensor readings. Core infrastructure concern, not salt-sensor specific.

Confirmed Home Assistant is the SmartThings bridge — no other path exists. HA is
connected with the SmartThings integration active. Salt sensor switches verified as
HA entities synced to SmartThings. All future components requiring SmartThings alerts
or control must route through Node-RED → HA REST API → SmartThings integration.

Added Garage Presence component (components/garage-presence/). HA-only — no ESP32,
no Node-RED. Two HA helpers created via UI: timer.garage_presence_timer (countdown)
and input_number.garage_timer_duration (duration in minutes, default 20). ST Garage
Timer Duration dimmer (49a4fa15) had no HA entities — replaced by input_number helper.

## 2026-05-18
Garage Presence component tested and refined. Automation 1 (restart timer on activity)
confirmed working with back door sensor and garage motion sensor. Garage cam trigger
wired up but unreliable due to cam sensitivity — left in place. Correct HA entity for
door sensor is binary_sensor.back_door_door (not binary_sensor.garage_door_sensor_door
as originally assumed). Timer duration template fixed — seconds formula used instead
of HH:MM:SS to avoid zero-padding issues.

Automation 2 (timer expiry → turn off Garage Presence Vswitch + auto-close door)
removed by design — garage door control intentionally decoupled from presence detection.
Timer expiry signal available via timer.finished event for future automations to consume.

## 2026-05-19
Started Garage Radar component (components/garage-radar/). Hardware: HLK-LD2412 24GHz
mmWave radar + ESP32 DevKitC-32 (38-pin, CP2102 USB-C), firmware via ESPHome. ESPHome
YAML created (Step 1). Breadboard wired and verified (Step 2) — corrected wiring doc:
LD2412 pin is labeled 5V (not VCC) and connects to ESP32 VIN, not 3.3V; onboard
regulator handles the step-down; UART logic is 3.3V, no level shifter needed.

## 2026-05-20
Garage Radar Steps 3–10 completed with breadboard prototype. ESPHome flashed via USB
(Step 3) — fixed ESPHome 2026.x breaking change: ld2412 timeout option removed, replaced
with delayed_off: 30s filter on has_target binary sensor. Fixed whitespace-in-path issue
by copying files to C:\esphome\garage-radar\ for flash. Fixed pi1.local resolving
to IPv6 link-local — used 192.168.1.117 (IPv4) for MQTT and HA MQTT integration setup.
All 8 HA entities confirmed (Presence, Moving Target, Still Target, 5 distance/energy sensors).

Sensor validation passed (Step 4): baseline, moving presence, still presence, 30s delayed_off
holdoff, and detection range all confirmed.

Steps 5–7 (perfboard transfer, soldered board validation, physical mount) deferred —
system fully functional on breadboard prototype. Perfboard layout and wiring docs complete
for when soldering is ready.

HA integration complete (Steps 8–9). 20-minute presence timeout confirmed as HA-only —
no Node-RED involvement. Two automations added: (1) garage_radar_presence added as trigger
to existing Garage Presence - Restart timer on activity automation; (2) new Garage Presence
- Radar keepalive automation fires every 10 minutes while radar detects presence, preventing
timer expiry during extended still workbench use. End-to-end tests 1–4 all passed.

Final documentation complete (Step 10): component README.md created, root README updated.

Infrastructure and documentation session. Added Architecture section to CLAUDE.md
covering component roles (ESP32 = edge sensor, no logic; Mosquitto = message bus;
Node-RED = brain/logic; Python log server = record keeper; HA = integration layer
only), full end-to-end message flow diagram, and the two parallel flows concept
(data flow vs. log flow) that every component produces.

Fixed pi1.local resolution on Windows — hostname was always intermittent
due to Windows mDNS unreliability. Set DHCP reservation on router for
192.168.1.117, added hosts file entry on Windows to bypass mDNS entirely.
IP documented in CLAUDE.md as fallback reference.

Fixed log server hang (ThreadingHTTPServer). Phone on 5G could reach HA (port 8123,
Docker) but not the log dashboard (port 80, Python). Root cause: single-threaded
HTTPServer blocks all new connections if a client connects and drops mid-response
(phone browsers do this frequently). Docker punches through iptables directly so
HA was unaffected. Fix: switched HTTPServer to ThreadingHTTPServer — each request
now handled in its own thread. Deployed and confirmed working from phone.

Log dashboard tweaks deployed and confirmed. Timestamp color changed from #444
to #888 to match Component column. Repeat count color changed from fixed #444
to match the message color. Watchdog message now reports active components seen
since last restart (e.g. "Watchdog: alive. Active: salt-sensor, garage-radar.")
instead of the generic "Watchdog: alive." Log server hang fix (ThreadingHTTPServer)
also deployed — confirmed working from phone.

MQTT hardening. Replaced single shared account (salt-sensor/raspberry) with
per-component accounts: jctsh-log-server, garage-radar, nodered, salt-sensor.
All passwords are strong random strings. Log server credentials moved out of
source code into /etc/jctsh/log-server.env on the Pi, injected via systemd
EnvironmentFile. garage-radar and salt-sensor secrets files (gitignored) updated
with new credentials. Node-RED broker node updated via UI. All four clients
confirmed connected in Mosquitto log.

Note: sudo mosquitto_passwd resets /etc/mosquitto/passwd group back to root —
always run sudo chown root:mosquitto /etc/mosquitto/passwd after any future
password changes, otherwise Mosquitto fails to start.

SSH key auth set up on Pi — passwordless SSH now works from this machine,
eliminating interactive password prompts for deployment commands.

Security hardening continued. Pi user password changed from default "raspberry"
to strong random password via chpasswd. Log dashboard secured with HTTP Basic
Auth (username: jctsh) — credentials injected via DASHBOARD_USER/DASHBOARD_PASS
env vars in /etc/jctsh/log-server.env alongside MQTT credentials. Verified 401
without auth, 200 with auth.

ESPHome/Arduino OTA passwords (currently "OTA"/"ota") deferred — changing OTA
password via OTA is a chicken-and-egg problem; requires USB flash. Low risk as
OTA is LAN-only. Defer to next time hardware is on the bench.

Updated CLAUDE.md: repo layout corrected to list all four components, added
Credentials section covering MQTT accounts, secrets file locations, mosquitto_passwd
ownership gotcha, dashboard Basic Auth, and SSH key auth. Log dashboard
infrastructure entry updated to note auth required. Future Components checklist
updated to include MQTT account creation.

Security hardening complete. Remaining items (MQTT ACLs, MQTT TLS, OTA passwords)
assessed as low risk for a home LAN not exposed to the internet — deferred
indefinitely. Log dashboard Basic Auth confirmed working from browser; credentials
saved in browser so no repeated prompts.

Post-hardening follow-up. Garage radar presence dropped while user was actively
working at workbench — garage door closed. Root cause: HA's MQTT integration was
using the old salt-sensor/raspberry credentials; when those were changed during
MQTT hardening, HA lost its broker connection. With no MQTT, garage radar entities
went unavailable, presence dropped, and the door closed. Fix: added dedicated
homeassistant MQTT account, updated HA MQTT integration via UI (Settings →
Devices & Services → MQTT → Configure). Presence restored immediately.

Lesson: HA MQTT integration credentials are configured through the UI only (not
in any config file) — easy to miss during MQTT password rotations. Always update
HA alongside Node-RED, ESPHome, and sketch secrets.

Pi timezone fixed from EDT to America/Phoenix (MST, UTC-7, no DST). Log server
restarted to clear EDT-timestamped entries. Passwordless sudo restored for pi
user after password change had revoked it.

Documented ST routine triggered by Garage Presence Vswitch turning off: closes
garage door and turns off lights. Added to garage-presence/CLAUDE.md with a note
that any false "presence off" (MQTT outage, HA restart, radar gap) will trigger it
unexpectedly — as confirmed by today's incident.

Repo cleanup. Added JCTsh-Component-Planning-Pattern.md (v1.4),
jctsh-parts-inventory.md, and components/front-porch-temp-sensor/ (instructions
in progress). Added .claude/settings.local.json to .gitignore — file contains
machine-specific absolute paths and should not be version controlled.

## 2026-06-05
Infrastructure maintenance. SmartThings integration had stopped working — root cause
traced to HA Docker container DNS failure. The container's /etc/resolv.conf had been
baked in at creation time (2026-05-15) with a stale DHCP-assigned DNS server
(192.168.1.222) that no longer existed. The Pi restarted on 2026-06-03 and Tailscale
overwrote the host's resolv.conf with its own DNS (100.100.100.100), but the container
kept its frozen copy — leaving HA unable to resolve any external hostnames.

Fix: pinned container DNS to 8.8.8.8/8.8.4.4 in both /etc/docker/daemon.json and a
new core/homeassistant/docker-compose.yml. The compose file also documents the full
container configuration (network_mode: host, volume mount, TZ, restart policy) which
was previously undocumented — container had been started with a bare docker run.

With DNS restored, set up Nabu Casa (HA Cloud, account joscthomas@gmail.com) to
provide an external HTTPS URL. This is required for the SmartThings integration's
OAuth setup flow — even though SmartThings communicates locally with the hub once
configured, the initial OAuth callback needs an externally reachable URL. SmartThings
re-added successfully; all devices visible.

Also cleared a stale production_auth.json from the HA cloud config directory that was
blocking Nabu Casa login with "Cannot login if already logged in."

Network housekeeping: network/jctsh-network.md updated to add SmartThings hub (192.168.1.112,
MAC 24-FD-5B-01-72-23), hiking-monitor (192.168.1.161, MAC 04-B2-47-97-DF-2C), and
coachproxyos (192.168.1.219, MAC B8-27-EB-BD-C6-63). DHCP reservations confirmed for
all three. SOFTWARE-ENVIRONMENT.md created to document all Pi services (Mosquitto,
Node-RED, HA Docker, log server, Tailscale) with versions, config paths, and
management commands.

## 2026-05-25
Started and completed front-porch-temp-sensor component. Breadboard prototype
fully built and tested (Steps 1–11). Hardware: ESP32 DevKitC-32 (microcontroller)
+ BMP280 (counterfeit BME280) + BH1750 (light sensor) sharing an I2C bus on
GPIO21 (SDA) / GPIO22 (SCL). ESPHome firmware with MQTT discovery, 60-second
sensor updates, and a 5-minute heartbeat.

Counterfeit BME280 issue: all three Podazz BME280 modules in the first batch
are actually BMP280s (no humidity support). Deployed with bmp280_i2c platform;
genuine BME280s ordered. Humidity shows Unknown in HA — expected. YAML has a
TODO comment to swap back when genuine modules arrive.

Whitespace-in-path issue (ESP-IDF compiler): "JCT Documents" path blocked
flashing. Fix: copy YAML + secrets to C:\esphome\front-porch-temp-sensor\ for
all flash operations. Established as standard for all ESPHome components going
forward.

Dedicated MQTT account created: front-porch-temp-sensor. Per-component MQTT
accounts are the established standard.

Two HA automations: Front Porch Temp Alert + Reminder (fires on temp >= threshold
6am–10pm; sends reminder 15 min later, once, via mode: single) and Front Porch
Temp Dropping (fires on temp < threshold 6am–10pm). Both notify
notify.mobile_app_pixel_10_pro_xl and notify.mobile_app_pixel_7_pro. Door sensor
condition removed at Robin's request — temperature and time window only. Lux
threshold removed in favor of explicit 6am–10pm time window.

End-to-end test complete (Steps 1–11). All 10 tests pass; time-window suppression
test (Step 6) skipped. Sensor readings confirmed in HA: 85–90°F, 13.46 psi,
illuminance responsive to light changes; humidity Unknown as expected.

Step 12 (perfboard transfer) deferred pending perfboard delivery. perfboard-layout.md
complete. mounting.md and component README.md written. Root README.md, parts
inventory, and CLAUDE.md credentials section updated.

## 2026-05-21
Installed Tailscale on Pi for remote access. Pi Tailscale IP: 100.70.162.24.
All local services (log dashboard, HA, Node-RED) now reachable from anywhere via
the Tailscale IP — no port forwarding, no public IP exposure. Install Tailscale on
any device and sign in with the same account to get access.

## 2026-05-18 (continued)
Garage Presence further refined. Added Automation 2 (timer expired → turn off Garage
Presence Vswitch) and Automation 3 (sync timer to vswitch — HA restart recovery).
Discovered SmartThings → HA sync is unreliable for real-time state triggers: virtual
switch and sensor state changes made in SmartThings do not reliably reach HA's event
system. Adopted Option A: HA owns Garage Presence Vswitch exclusively — no SmartThings
routines may turn it on. Removed ST routine that turned on vswitch on back door open.
PIR sensors (garage motion, garage cam) unreliable in hot Arizona garage — stay stuck
`on` preventing off→on transition triggers. Confirmed working in cooler morning
temperatures.

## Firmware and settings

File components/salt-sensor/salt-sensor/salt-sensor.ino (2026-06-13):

/*
 * Water Softener Salt Level Sensor
 * Board:   ESP32 Dev Module
 * Sensor:  JSN-SR04T Waterproof Ultrasonic
 *
 * Wiring:
 *   JSN-SR04T Trig  → GPIO 5
 *   JSN-SR04T Echo  → 1kΩ → GPIO 18 → 2kΩ → GND
 *   Red LED    → GPIO 2  via 220Ω   (Critical)
 *   Yellow LED → GPIO 15 via 220Ω   (Warning)
 *   Green LED  → GPIO 4  via 220Ω   (Good)
 *
 * Architecture:
 *   ESP32 publishes sensor readings to MQTT every 12 hours.
 *   Node-RED applies threshold logic and controls SmartThings
 *   via Home Assistant. Node-RED publishes a status string back
 *   to the ESP32 which drives the LEDs.
 *
 * MQTT Topics:
 *   Publish:   jctsh/sensors/salt-sensor/data   {"distance_cm":25.3}
 *   Publish:   jctsh/sensors/salt-sensor/log    {"component":"salt-sensor","category":"...","message":"..."}
 *   Subscribe: jctsh/sensors/salt-sensor/status "ok" | "warning" | "critical" | "error"
 *
 * OTA:
 *   Host: salt-sensor   Password: see secrets.h
 *   Three rapid LED flashes confirm successful reboot.
 */

#include <WiFi.h>
#include <ArduinoOTA.h>
#include <PubSubClient.h>
#include "secrets.h"

// ================== PIN DEFINITIONS ==================
const int trigPin      = 5;
const int echoPin      = 18;
const int redLedPin    = 2;
const int yellowLedPin = 15;
const int greenLedPin  = 4;

// ================== TIMING ==================
const unsigned long READING_INTERVAL    = 43200000UL;  // 12 hours
const unsigned long MQTT_RETRY_INTERVAL = 30000UL;     // 30 s between reconnect attempts

// ================== MQTT TOPICS ==================
const char* TOPIC_DATA   = "jctsh/sensors/salt-sensor/data";
const char* TOPIC_STATUS = "jctsh/sensors/salt-sensor/status";
const char* TOPIC_LOG    = "jctsh/sensors/salt-sensor/log";

// ================== GLOBALS ==================
String currentStatus = "unknown";
float  lastDistance  = 0.0;

unsigned long lastReadingTime = 0;
unsigned long lastMqttAttempt = 0;

// ================== MQTT ==================
WiFiClient   wifiClient;
PubSubClient mqtt(wifiClient);

void publishLog(const char* category, const String& message) {
  String payload = "{\"component\":\"salt-sensor\",\"category\":\"";
  payload += category;
  payload += "\",\"message\":\"";
  payload += message;
  payload += "\"}";
  mqtt.publish(TOPIC_LOG, payload.c_str());
  Serial.println(payload);
}

void mqttCallback(char* topic, byte* payload, unsigned int length) {
  String msg = "";
  for (unsigned int i = 0; i < length; i++) msg += (char)payload[i];

  if (String(topic) == TOPIC_STATUS) {
    if (msg != currentStatus) {
      publishLog("MQTT", "Status: " + currentStatus + " -> " + msg);
    }
    currentStatus = msg;
  }
}

bool mqttConnect() {
  if (WiFi.status() != WL_CONNECTED) return false;
  publishLog("MQTT", "Connecting to " + String(MQTT_HOST) + "...");
  if (mqtt.connect("salt-sensor-esp32", MQTT_USER, MQTT_PASS)) {
    mqtt.subscribe(TOPIC_STATUS);
    publishLog("MQTT", "Connected. Subscribed to " + String(TOPIC_STATUS));
    return true;
  }
  publishLog("MQTT", "Failed, rc=" + String(mqtt.state()) + " - will retry in 30s");
  return false;
}

void publishReading(float distCm) {
  if (!mqtt.connected()) return;
  String payload = "{\"distance_cm\":" + String(distCm, 1) + "}";
  mqtt.publish(TOPIC_DATA, payload.c_str(), true);  // retained
}

// ================== SENSOR ==================
float getFilteredDistance() {
  float readings[15];
  int count = 0;
  for (int i = 0; i < 15; i++) {
    digitalWrite(trigPin, LOW);  delayMicroseconds(2);
    digitalWrite(trigPin, HIGH); delayMicroseconds(10);
    digitalWrite(trigPin, LOW);
    long duration = pulseIn(echoPin, HIGH, 40000);
    float d = duration * 0.0343 / 2.0;
    if (d > 2 && d < 200) readings[count++] = d;
    delay(50);
  }
  if (count == 0) return -1;
  for (int i = 1; i < count; i++) {
    float key = readings[i];
    int j = i - 1;
    while (j >= 0 && readings[j] > key) { readings[j+1] = readings[j]; j--; }
    readings[j+1] = key;
  }
  return readings[count / 2];
}

// ================== LEDs ==================
void updateLEDs(bool blinkState) {
  if (currentStatus == "ok") {
    digitalWrite(greenLedPin,  HIGH);
    digitalWrite(yellowLedPin, LOW);
    digitalWrite(redLedPin,    LOW);
  } else if (currentStatus == "warning") {
    digitalWrite(greenLedPin,  LOW);
    digitalWrite(yellowLedPin, blinkState ? HIGH : LOW);
    digitalWrite(redLedPin,    LOW);
  } else if (currentStatus == "critical") {
    digitalWrite(greenLedPin,  LOW);
    digitalWrite(yellowLedPin, LOW);
    digitalWrite(redLedPin,    blinkState ? HIGH : LOW);
  } else if (currentStatus == "error") {
    digitalWrite(greenLedPin,  blinkState ? HIGH : LOW);
    digitalWrite(yellowLedPin, blinkState ? HIGH : LOW);
    digitalWrite(redLedPin,    blinkState ? HIGH : LOW);
  } else {
    // unknown / no status yet — slow-blink green to show it's alive
    digitalWrite(greenLedPin,  blinkState ? HIGH : LOW);
    digitalWrite(yellowLedPin, LOW);
    digitalWrite(redLedPin,    LOW);
  }
}

// ================== WiFi ==================
void checkWiFi() {
  if (WiFi.status() != WL_CONNECTED) {
    publishLog("System", "WiFi connection lost - reconnecting...");
    WiFi.reconnect();
    unsigned long start = millis();
    while (WiFi.status() != WL_CONNECTED && millis() - start < 10000UL) {
      delay(500);
      Serial.print(".");
    }
    publishLog("System", WiFi.status() == WL_CONNECTED ? "WiFi reconnected." : "WiFi reconnect failed.");
  }
}

// ================== SETUP ==================
void setup() {
  Serial.begin(115200);
  delay(2000);
  Serial.println("\n\n=== Water Softener Salt Sensor ===");

  pinMode(trigPin,      OUTPUT);
  pinMode(echoPin,      INPUT);
  pinMode(redLedPin,    OUTPUT);
  pinMode(yellowLedPin, OUTPUT);
  pinMode(greenLedPin,  OUTPUT);

  // LED self-test
  Serial.println("[Boot] LED self-test...");
  digitalWrite(redLedPin, HIGH);    delay(600);
  digitalWrite(yellowLedPin, HIGH); delay(600);
  digitalWrite(greenLedPin, HIGH);  delay(600);
  for (int i = 0; i < 4; i++) {
    digitalWrite(redLedPin, LOW); digitalWrite(yellowLedPin, LOW); digitalWrite(greenLedPin, LOW);
    delay(300);
    digitalWrite(redLedPin, HIGH); digitalWrite(yellowLedPin, HIGH); digitalWrite(greenLedPin, HIGH);
    delay(300);
  }
  digitalWrite(redLedPin, LOW); digitalWrite(yellowLedPin, LOW); digitalWrite(greenLedPin, LOW);

  // OTA reboot confirmation: 3 rapid triple-flashes
  for (int i = 0; i < 3; i++) {
    digitalWrite(redLedPin, HIGH); digitalWrite(yellowLedPin, HIGH); digitalWrite(greenLedPin, HIGH);
    delay(100);
    digitalWrite(redLedPin, LOW);  digitalWrite(yellowLedPin, LOW);  digitalWrite(greenLedPin, LOW);
    delay(100);
  }

  // WiFi
  Serial.printf("[WiFi] Connecting to %s...\n", WIFI_SSID);
  WiFi.setHostname("salt-sensor");
  WiFi.begin(WIFI_SSID, WIFI_PASSWORD);
  while (WiFi.status() != WL_CONNECTED) { delay(500); Serial.print("."); }
  Serial.println("\n[WiFi] Connected.  IP: " + WiFi.localIP().toString());

  // OTA
  ArduinoOTA.setHostname("salt-sensor");
  ArduinoOTA.setPassword(OTA_PASSWORD);
  ArduinoOTA.begin();
  Serial.println("[OTA]  Ready.");

  // MQTT
  mqtt.setServer(MQTT_HOST, MQTT_PORT);
  mqtt.setCallback(mqttCallback);
  mqttConnect();

  publishLog("System", "Salt Sensor ready. IP: " + WiFi.localIP().toString());
}

// ================== LOOP ==================
void loop() {
  ArduinoOTA.handle();
  checkWiFi();

  // MQTT keep-alive and reconnect
  if (mqtt.connected()) {
    mqtt.loop();
  } else if (millis() - lastMqttAttempt >= MQTT_RETRY_INTERVAL) {
    lastMqttAttempt = millis();
    mqttConnect();
  }

  // Blink state (500 ms toggle)
  static bool blinkState = false;
  static unsigned long lastBlink = 0;
  if (millis() - lastBlink >= 500) {
    blinkState = !blinkState;
    lastBlink  = millis();
  }
  updateLEDs(blinkState);

  // Sensor reading every 12 hours
  if (lastReadingTime == 0 || millis() - lastReadingTime >= READING_INTERVAL) {
    lastReadingTime = millis();
    float dist = getFilteredDistance();
    if (dist < 0) {
      publishLog("Alert", "No valid sensor reading - check wiring.");
      currentStatus = "error";
    } else {
      lastDistance = dist;
      publishReading(dist);
    }
  }

  delay(100);
}

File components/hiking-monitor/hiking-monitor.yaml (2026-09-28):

# JCTsh Hiking Monitor — ESPHome Configuration
# Hardware: ESP32 DevKitC-32 (38-pin, CP2102 USB-C)
#           + GY-BME280 (I2C 0x76) — temp, humidity, pressure
#           + Adafruit LTR-390 (I2C 0x53) — UV index
#           + Waveshare 2.13" e-ink V4 SSD1680 (SPI)
#           + Dock detect: TP4056 IN+ → 68kΩ+100kΩ divider → GPIO32
#           + Voltage divider → battery ADC (GPIO35)
#           + Slide switch → GPIO27 (hiking mode signal, active-LOW)
#           + EEMB 1100mAh LiPo + TP4056+boost module
#
# GPIO assignments:
#   GPIO18  SPI CLK (e-ink)
#   GPIO23  SPI MOSI/DIN (e-ink)
#   GPIO5   SPI CS (e-ink, active-low)
#   GPIO17  DC (e-ink data/command select)
#   GPIO16  RST (e-ink reset, active-low)
#   GPIO4   BUSY (e-ink busy input)
#   GPIO21  I2C SDA (BME280 + LTR-390 shared bus)
#   GPIO22  I2C SCL (BME280 + LTR-390 shared bus)
#   GPIO27  Slide switch (internal pull-up; LOW = switch ON = hiking mode)
#   GPIO32  Dock detect (TP4056 IN+ → 68kΩ+100kΩ divider, HIGH=USB present)
#   GPIO35  Battery voltage ADC (voltage divider output, input-only pin)
#
# MQTT topics (prefix: jctsh/components/hiking-monitor):
#   .../data       — sensor readings (JSON payload per JCTsh-Environmental-Data-Architecture.md)
#   .../log        — diagnostic messages (JSON, wildcard routed to Python log server)
#   .../heartbeat  — 5-min heartbeat when home WiFi connected (wildcard monitored by Node-RED watchdog)
#
# Operating modes:
#   Field mode  (switch ON, no WiFi): read sensors → write JSON to SPIFFS /hike_log.jsonl
#   Home mode   (switch ON, WiFi+MQTT): replay SPIFFS log → MQTT; live readings → MQTT directly
#   Upload mode (switch OFF, USB connected): auto-wake via dock detect → replay log → sleep
#   Sleep mode  (switch OFF, no USB): deep sleep ~10µA
#
# Sensor update interval: 2 minutes
# Heartbeat interval: 5 minutes (home/upload mode only)
#
# NOTE on e-ink model string: 2.13in-ttgo-b74 is the expected SSD1680 model.
# If the display shows garbage or doesn't initialize, try 2.13in-b74 or check
# current ESPHome docs for the SSD1680 model string. Confirm at Step 5.

esphome:
  name: hiking-monitor
  friendly_name: Hiking Monitor
  includes:
    - hiking_logger.h
  on_boot:
    - priority: 600.0
      then:
        - lambda: 'hike_log_begin();'
        # CARD-0195 (original), widened by CARD-0216 to log unconditionally
        # rather than only on an abnormal-keyword match -- confirmed
        # 2026-08-27 (CARD-0217): a real hike hit ~270 reboots in a
        # ~9-minute window, and every single one logged an EMPTY reset
        # reason. Root cause, confirmed against ESPHome's own debug
        # component source: the debug component's reset_reason_ text
        # sensor is only ever populated inside dump_config() (via
        # publish_state() in get_device_info_()), not during setup() --
        # and ESPHome's dump_config() pass for the whole app runs strictly
        # AFTER every component's setup() completes, which includes every
        # on_boot trigger regardless of its own priority value (on_boot
        # triggers are themselves setup_priority-ordered components, not a
        # separate later phase). So reading id(reset_reason_text).state
        # from ANY on_boot block, at ANY priority, always sees the
        # default/empty value -- there's no priority number that fixes
        # this, the read has to happen after setup()+dump_config() finish
        # for the whole app, i.e. once loop() is genuinely running.
        #
        # Fix: on_boot only sets a pending flag (cheap, no dependency on
        # reset_reason_text at all) when the field-mode condition is met;
        # the actual read+log happens at the top of the 2-min interval:
        # block below, on the FIRST tick after boot -- confirmed via
        # ESPHome's own interval component source that its default
        # startup_delay is 0s, so the first tick fires essentially
        # immediately once loop() starts (not after waiting a full 2min),
        # which matters here specifically because a rapid reset loop (like
        # the 270-in-9-minutes incident this fix responds to) needs the
        # read to happen fast enough to survive to the next crash, not
        # deferred a full interval period.
        # CARD-0217 item 2: field mode never actually turned WiFi off --
        # `in_field_mode` elsewhere in this file is just what gets inferred
        # when a connection attempt happens to fail (no known network on the
        # trail), not something that stops the radio from trying. Every
        # failed attempt still powers up the radio and draws the same
        # active-boot current spike CARD-0026 found brownout-triggering on
        # the test rig -- with nothing ever stopping the WiFi component from
        # retrying continuously across a multi-hour hike, that's the leading
        # suspect for what actually escalated into the 2026-08-27 reset
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

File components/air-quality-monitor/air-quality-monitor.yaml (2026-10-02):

# JCTsh Air Quality Monitor — ESPHome Configuration
# Hardware: ESP32 DevKitC-32 (38-pin, CP2102 USB-C)
#           + Sensirion SEN55 (I2C 0x69, via Adafruit #5964 adapter) — PM1.0/2.5/4.0/10, VOC, NOx
#             SEN55 is hard-wired always-on whenever the device has power (see
#             Step 6 decision below) — no dedicated power-gate transistor.
#           + RGB LED (KY-016) — GPIO18/19/23 (pins 30/31/37). PM2.5 threshold
#             indicator (Red/Green combos) + boot self-test/init sequence +
#             brief per-reading blink (Step 5). Blue is dedicated entirely to
#             networking-status diagnostics (Step 8) — see the WiFi Gate
#             Diagnostics section below.
#           + Dock detect: TP4056 IN+ (or solar) → 68kΩ+100kΩ divider → GPIO32 (pin 7)
#           + Battery voltage divider → GPIO34 (pin 5, input-only)
#           + Intent switch: repurposed SS12D10 slide switch → GPIO27 (pin 11),
#             INPUT_PULLUP + inverted (CARD-0218, Step 8) — state TRUE = switch
#             closed = actively collecting field data, same semantic as
#             hiking-monitor's own slide_switch.
#           + EEMB 1100mAh LiPo + TP4056 (charging only) + Pololu D24V10F3 buck-
#             boost regulator (CARD-0198, replaces the original MCP1700 LDO) +
#             inline power switch (BK-1208, gates only the Pololu's VIN — see
#             wiring.md's "Inline Power Switch" section for the shared-node
#             topology and why it does NOT isolate TP4056's own charge path)
#
# STEP 8 (2026-09-09): field/home mode duty-cycle firmware.
# CARD-0377 Phase 2 (2026-10-01): MQTT removed entirely. A persistent broker
# session needed its own attempt-window/backoff/enable-disable state machine
# to manage; a one-shot upload doesn't. When eligible, the device now just
# enables WiFi, does ONE HTTP POST of the whole buffered log to the
# data-pipeline gateway's bulk endpoint, and clears on confirmed success --
# no flag tracks "was this replayed," so there's nothing left to get stuck
# (the actual bug CARD-0346 patched twice and this redesign deletes outright).
# Three independent signals still gate any upload attempt
# (JCTsh-Build-Standards.md §2.14 points 11-13) — Intent off AND Power
# Connected AND battery >= the upload-safe margin (3.5V, revised 2026-09-09
# from an original 3.8V -- see CARD-0012: CARD-0198's brownout finding came
# from a deliberate battery-ALONE stress trial, a scenario the other two
# conditions already prevent; the well-tested docked case (TP4056 supplying
# the burst current, not the battery) was clean at every voltage tried, so
# only a small margin above the confirmed-catastrophic 3.4V floor is kept,
# for the untested weak/solar-charger case). None of these signals ever
# stand in for another. Field-mode duty-cycle logging (SEN55 I2C
# mode-switching, Measurement <-> RHT/Gas-Only) runs independent of
# dock-detect state — a deliberate deviation from hiking-monitor's pattern
# (which stops field logging the instant dock-detect goes HIGH), because
# solar/field-USB charging can happen mid-collection on this device just as
# easily as at home. It IS gated on the Intent switch: Intent ON means
# "actively collecting field data," matching hiking-monitor's own
# Intent-switch semantics (see wiring.md's Intent Switch Wiring section).
#
# STEP 6 DECISION (2026-08-21): no dedicated SEN55 power-gate transistor.
# Sensirion's own "Reduced Power Operation for SEN5x" doc recommends I2C
# mode-switching (Measurement ↔ RHT/Gas-Only) as the primary duty-cycle
# power-saving mechanism, not physically cutting power — and the existing
# inline power switch (battery+ path, Step 1) already covers true full-off
# for storage/transport. SEN55 stays hard-wired to the common ground rail.
#
# GPIO assignments (ESP32-project-pins.md has the full 38-pin table):
#   GPIO21  I2C SDA (SEN55 via Adafruit adapter) — blue
#   GPIO22  I2C SCL — yellow
#   GPIO27  Intent switch (pin 11, CARD-0218/Step 8) — INPUT_PULLUP, inverted
#   GPIO17  Debug UART2 TX (CARD-0205, 2026-08-24) — external CP2102 adapter,
#           transmit-only. ESP32's fixed UART2 TX pin (not remappable via
#           ESPHome's logger component — see logger: block below)
#   GPIO32  Dock detect (TP4056 IN+ or solar → divider, HIGH = docked/charging)
#   GPIO34  Battery voltage ADC (100kΩ/100kΩ divider, post-switch node — wiring.md)
#
# CARD-0377 Phase 2: no MQTT at all, so no topics to list here anymore. Data
# goes to the data-pipeline gateway's bulk-upload endpoint over plain HTTP
# POST (see secrets.yaml's data_pipeline_bulk_url); dashboard visibility is
# the gateway's own job (it relays onto MQTT itself via hike-izer-
# orchestrator's existing /webhook/pipeline-log, same mechanism other tables
# already use -- this device has no MQTT client to do that itself, same
# constraint data-pipeline-api's own app.py already documents for itself).
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

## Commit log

2026-05-16 Initial commit: JCTsh monorepo, salt-sensor as first component
    - Salt Sensor moved to components/salt-sensor/
    - ESP sketch: web server removed, MQTT logging added via publishLog()
    - MQTT topics renamed: saltlevel/* -> jctsh/sensors/salt-sensor/*
    - Node-RED flow split into core.flow.json (broker) + salt-sensor.flow.json (logic)
    - Test mode loop bug fixed in salt-sensor.flow.json
    - Python log server added to core/logging/, deployed to Pi at http://raspberrypi.local/
    - Pi config snapshots added to core/ (mqtt, node-red, homeassistant)
    - Root CLAUDE.md, README.md, and DEVLOG.md added
    [water_softener_salt_sensor_v3.ino]
2026-05-16 Fix MQTT auth in log server; move sketch into Arduino-required subfolder
    - Add MQTT_USER/MQTT_PASS to log_server.py so it can connect to the
    password-protected Mosquitto broker
    - Move water_softener_salt_sensor_v3.ino into matching subfolder
    (Arduino IDE requires sketch folder name to match .ino filename)
    [water_softener_salt_sensor_v3.ino]
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2026-05-23 Rename salt-sensor sketch, fix log JSON corruption
    Remove v3 version tag from sketch directory and filename — version is
    tracked by git. Fix publishLog("MQTT", "Published: " + payload) which
    embedded raw JSON inside a JSON string, causing the log server to
    silently drop the message on every reading.
    [salt-sensor.ino]
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2026-05-25 Reduce heartbeat noise: 30-min interval + dashboard collapsing
    - Change heartbeat interval from 5min to 30min on garage-radar and
    front-porch-temp-sensor (6x reduction in heartbeat log volume)
    - Update watchdog silence threshold from 10min to 35min to match
    (30-min interval + 5-min buffer)
    - Add heartbeat group collapsing to log dashboard: consecutive
    heartbeats with the same state collapse into a single row showing
    count, time range, and last-known values. Presence changes on
    garage-radar break the group; continuous temp values always collapse.
    - Add salt-sensor ESPHome migration to backlog (do before perfboard)
    [front-porch-temp-sensor.yaml]
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2026-05-26 Swap front-porch-temp-sensor from BMP280 to genuine GY-BME280
    Change platform bmp280_i2c → bme280_i2c and re-add humidity entity.
    Pending physical sensor swap and OTA reflash.
    [front-porch-temp-sensor.yaml]
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2026-06-04 hiking-sensor: steps 5-8 complete; build standards v1.3
    Steps 5-7 confirmed complete: sensors, display, LittleFS replay, and
    pressure trend all validated. Step 8 power-system.md created.
    Key fix: on_connect raw lambda publishes silently dropped by broker;
    replaced with native mqtt.publish actions + 500ms delay. Heartbeat
    converted to same native action pattern for consistency. Online message
    separator corrected (em dash -> hyphen). Pressure steady arrow -> =>.
    Build Standards v1.3: added ESPHome boilerplate (§2.8), sensor coding
    standards including NaN guards and internal sensors (§2.9), will_message
    pattern with retain:false requirement (§3.4), MQTT discovery rule (§3.5),
    heartbeat "H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
    [hiking-sensor.yaml]
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2026-06-04 hiking-sensor: steps 12-14 complete; fix SPIFFS duplicate replay
    - Step 12: all 9 end-to-end tests passed; results recorded in testing.md
    - Fix: SPIFFS remove() not persisting across power cuts caused duplicate
    replays on reconnect. Fix: hike_log_clear() now truncates to 0 bytes
    instead of calling remove(); hike_log_has_data() checks file size > 0;
    on_connect lambda clears log before replay loop (not after)
    - Step 13: parts inventory updated — ESP32, BME280, LTR-390, e-ink,
    LiPo, TP4056, button all logged as used for hiking-sensor
    - Step 14: perfboard-layout.md created for 5x7cm main board build
    [hiking-sensor.yaml]
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2026-06-05 hiking-sensor: replace button with dock detect, add power switch, document operations
    - GPIO32 repurposed from button to dock detect: TP4056 IN+ → 68kΩ+100kΩ
    voltage divider → GPIO32 INPUT; validated 0.28V (field) / 3.04V (docked)
    - Data publish and LittleFS write suppressed when docked; heartbeat unaffected
    - on_state log messages fire on dock/undock transitions
    - perfboard-layout.md: button harness removed; dock detect divider and slide
    switch on VOUT+ added
    - wiring.md: button section replaced with dock detect wiring
    - operations.md: new file documenting field/home/docked modes and hike workflow
    [hiking-sensor.yaml]
2026-06-06 front-porch-temp-sensor: fix I2C lockup, heartbeat interval, observability
    - Add on_connect delay 500ms so boot log messages reach the dashboard
    - Fix heartbeat interval from 30min to 5min (watchdog was never catching failures)
    - Add I2C frequency: 10khz to address I2C bus lockup after first read
    - Add restart button for remote reboot via MQTT/HA without OTA flash
    - Add BH1750 id (bh1750_lux) and sensor health checks: publishes Sensor
    category error to log dashboard every 5min when BME280 or BH1750 returns NaN
    - Codify sensor health detection as §4.6 in JCTsh-Build-Standards.md
    - Add §4.6 backlog item to hiking-sensor instructions (bme_temp, ltr_uv_index)
    - Update §4.1 note: front-porch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
    [front-porch-temp-sensor.yaml]
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2026-06-11 hiking-sensor: redesign power system for deep sleep + upload mode
    - Switch moved from VOUT+ power path to GPIO27 input (active-LOW, pull-up)
    - VOUT+ now runs direct to ESP32 VIN; deep sleep replaces hard power cut
    - Dock detect (GPIO32) repurposed as deep sleep wake source for USB auto-wake
    - Upload mode: plug in USB (switch off) → device wakes, replays hike data, sleeps
    - Solar false-positive on dock detect eliminated (switch state determines mode)
    - ESPHome YAML updated: deep_sleep ext0/ext1, slide_switch sensor, mode gating
    - perfboard-layout.md: 4-pin TP4056 header, pre-power checks section, wiring clarified
    - operations.md: workflow rewritten for new sleep/upload/hiking modes
    - testin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
    [hiking-sensor.yaml]
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2026-06-12 hiking-sensor: complete perfboard testing, deep sleep fixes, GPS pipeline update
    - All 11 tests passed (2026-06-12); tests 10-11 newly completed
    - Deep sleep working: removed captive_portal (was calling prevent_deep_sleep),
    added deep_sleep.allow before every enter, 500ms delay for MQTT flush
    - Upload mode fixed: on_connect path now checks dock_detect before sleeping;
    boot loop with USB connected resolved
    - Display: "Hiking monitor off" shown before sleep, 10s init screen, 1dp temp/humidity
    - Log categories: Upload mode, Entering deep sleep, replay messages → Sensor
    - hiking-hike-events.flow.json moved from core/node-red/ to components/hiking-sensor/
    - Node-RED password reset; settings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
    [hiking-sensor.yaml]
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2026-06-13 hiking-sensor step 21: add Pixel hotspot as second WiFi network
    - hiking-sensor.yaml: switch from single wifi ssid/password to networks list;
    hotspot_ssid / hotspot_password added as second entry
    - secrets.yaml.template: add hotspot_ssid and hotspot_password fields
    - wifi-config.md: documents two-network setup, hotspot configuration,
    broker reachability constraints, and sync workflow
    Note: hotspot sync to MQTT broker is constrained — raspberrypi.local and
    192.168.1.117 are unreachable from cellular; Tailscale IP only works from
    Tailscale clients. Broker reachability from field hotspot is an open item.
    [hiking-sensor.yaml]
2026-06-13 hiking-sensor: fix LittleFS → SPIFFS in comments and wifi-config.md
    We use SPIFFS via the custom hiking_logger.h component, not LittleFS.
    Corrected three yaml comment lines and one wifi-config.md reference.
    [hiking-sensor.yaml]
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2026-06-13 hiking-sensor: streaming SPIFFS replay — no RAM limit
    Replace hike_log_get_all() (loads entire log into a vector) with:
    - hike_log_count(): streaming line count, no heap allocation
    - hike_log_replay_stream(): streams one line at a time via callback
    Previously, replay of ~900+ readings (~30h of data) would exhaust
    the 320KB heap and crash. Now replay scales to the full 1.47MB SPIFFS
    partition (~7,000 readings, ~230h) with constant 512-byte stack usage.
    Also adds fprintf() return-value check so SPIFFS-full is logged
    rather than silently dropped.
    Clear is now after replay (not before) — a power cut mid-replay
    causes duplicate rows on next connect rather than data loss.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
    [hiking-sensor.yaml]
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2026-06-13 logging: standardize categories, reduce noise across all components
    - CLAUDE.md: add log category guide (System/MQTT/Sensor/Alert/Test) with
    rationale and System vs MQTT dividing line; README points to it
    - garage-radar: shorten verbose MQTT connected message
    - salt-sensor: remove redundant Distance log line and MQTT publish
    confirmation; fix sensor read failure System→Alert; fix Node-RED
    [ERROR] prefix System→Alert
    - front-porch-temp-sensor: BME280/BH1750 read failures Sensor→Alert
    - hiking-sensor: replay/sleep/upload-mode messages Sensor→System (7
    occurrences); operations.md adds Charging section with expected charge
    time, red-LED-stays-on quirk, battery voltage reference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
    [front-porch-temp-sensor.yaml, hiking-sensor.yaml, salt-sensor.ino]
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2026-06-13 Fix e-ink sleep message and display fade before deep sleep
    Change sleep screen from 'Hiking monitor off' to 'Hiking monitor asleep'.
    Add 2s delay after display update in all three sleep paths to allow the
    SSD1680 to complete its full refresh cycle before the ESP32 cuts power,
    preventing a faded/mid-refresh image on the display.
    Not yet deployed — catch for next OTA flash.
    [hiking-sensor.yaml]
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2026-06-15 Change heartbeat standard to 30 min, derived from 35-min watchdog timeout
    30 min is the correct interval because the watchdog fires at interval + 5-min
    buffer (35 min). The previous 5-min standard was inconsistent with the actual
    watchdog. Updates Build Standards v1.6→v1.7 and aligns front-porch-temp-sensor.
    [front-porch-temp-sensor.yaml]
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2026-07-04 Add hiking-monitor low-battery cutoff, JCTsh battery safety standards, enclosure CAD progress
    Original hiking-monitor LiPo failed in the field with no warning, prompting a
    firmware low-battery cutoff (hiking-sensor.yaml), new JCTsh-Build-Standards.md
    battery-powered-component standards (PCM-protected cells, fireproof charging,
    low-battery cutoff, boost-vs-LDO guidance) applied retroactively to
    bedside-clock, and corrected parts inventory counts. Also completes Part 2
    measurements and Part 3 OpenSCAD shell generation for the permanent 3D-printed
    enclosure (components/hiking-sensor/enclosure/), plus backlog cards for
    follow-up battery testing and sleep-current measurement.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
    [bottom-shell-raw.stl, bottom-shell.scad, easyprojectboxv24.scad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]
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2026-07-05 Complete bottom shell CAD for hiking-monitor enclosure
    Fixed a chamfer bug that left corner bosses structurally disconnected from
    the floor, corrected boss-height math (twice), resolved a standoff-height
    mismatch against available hardware, and enlarged/tuned the shell footprint
    after real boss-vs-perfboard clearance came up short. Switched corner
    fastening from M3 nuts to heat-set threaded inserts after the nut approach
    left boss walls too thin to print reliably.
    Established shared N/S/E/W compass terminology (ESP32 USB-C = South) to
    resolve real ambiguity in wall assignments, which corrected several wrong
    placements (LTR-390 aperture, BME280 vent, velcro straps). Completed all
    bottom shel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
    [bottom-shell-final.stl, bottom-shell-raw.stl, bottom-shell.scad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]
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2026-07-09 Complete top shell CAD for hiking-monitor enclosure
    Finishes the enclosure CAD phase — all three shells now final:
    - Carabiner bail (South wall): solid boss with a small perpendicular
    paracord hole, sized down from a direct carabiner-through-hole design
    after real-world clearance research showed that needed more room than
    the wall could fit; carabiner clips to a paracord loop instead.
    - Fixed missing corner boss pass-throughs: the template's screw holes
    were blind (correct for the bottom shell's heat-set inserts, wrong for
    the top shell, which needs a full pass-through) — punched all 4
    corners through.
    - Velcro strap slots (4x) added to the bottom shell floor, weighted
    towa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
    [bottom-shell-final.stl, top-shell-final.stl, top-shell-raw.stl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]
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2026-07-10 Add CARD-0045, close air-quality-monitor Phase 3, write Phase 4
    CARD-0045: found and documented a low-priority known issue on
    hiking-sensor — ESPHome's reboot_timeout doesn't apply when a
    wifi.ap: fallback is configured (esphome/issues#7222), and
    hiking-sensor has one. Noted directly in hiking-sensor.yaml.
    air-quality-monitor: closed Phase 3 (timeout policy matches
    hiking-sensor but explicitly avoids inheriting the CARD-0045 bug).
    Moved perfboard footprint measurement and LiPo polarity check from
    Phase 2 planning blockers to Phase 4 bench steps. Wrote the Phase 4
    Claude Code instructions — 10 bench steps covering mode-switching
    confirmation, wiring, SEN55 validation (ESPHome's native se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
    [hiking-sensor.yaml]
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2026-07-10 salt-sensor: migrate to ESPHome, verify end-to-end, move LEDs off strapping pins
    Completes CARD-0004's field verification (LED self-test, /data, /status,
    /log, /heartbeat all confirmed live) and closes most of CARD-0049: LEDs
    moved from breadboard wiring (GPIO2/15/4, two on strapping pins) to
    GPIO32/33/27 for the perfboard build, all three now on the same header row.
    Also removed the ESP32-side "Status: X -> Y" transition log — it added no
    value over Node-RED's own richer threshold logging, and dashboard history
    showed it once logged a stray "offline" value that never came from
    Node-RED (a fossil of the birth_message/status topic collision this
    component's mqtt: config already guards agai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
    [salt-sensor.ino]
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2026-07-11 Add persistent visual kanban board, rename backlog.md to kanban-board.md
    Closes CARD-0056: replaced ad hoc chat summaries of the backlog with a
    redeployable Artifact page (blueprint-styled board, search, type
    filters, collapsible columns) rebuilt from kanban-board.md on request.
    Renamed backlog.md to kanban-board.md and updated every live reference
    across README, CLAUDE.md, the Team Operating System doc, and the
    photo-server docs that pointed to it by name.
    [hiking-sensor.yaml]
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2026-07-13 Close CARD-0065: validate LTR-390 UVI in real sunlight, expand heartbeat log
    UVI confirmed sane (6.90-6.92) in direct sun after ruling out wiring/
    enclosure/connector causes. Expanded hiking-sensor's 5-min heartbeat
    log to include humidity, pressure, and UVI, not just temp/RSSI/batt,
    so future sensor issues are diagnosable remotely without reading the
    OLED in person.
    [hiking-sensor.yaml]
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2026-07-23 CARD-0006: move log directory to USB stick, add standard Immich import runbook
    Log server now writes to a dedicated USB stick (UUID-mounted at
    /mnt/jctsh-logs) instead of the Pi's SD card. Fixed a real boot-race
    gap along the way: jctsh-logging.service had no RequiresMountsFor, so
    a reboot could start the service before the mount was ready and
    silently recreate the log dir on the SD card underneath it. Verified
    clean via an actual reboot test. Also documents the new standard
    immich-go from-folder import procedure in operations.md, used to
    clear the USB stick's prior contents into Immich before reformatting.
    Also add equip-shelf fan bracket STL files.
    [Fan bracket.stl, fan_bracket_ACInfinity_S7.stl]
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2026-08-18 CARD-0009/0076: hiking-monitor enclosure build closed, secret rotation closed
    CARD-0009: display rotated to 270 and flashed live 2026-08-17; reflection
    items complete - new JCTsh-3D-Enclosure-Instructions-Template.md generalized
    from the hiking-monitor build, JCTsh-Build-Standards.md v1.18 (3D-printed
    enclosure pattern, sensor cable relocation pattern), README enclosure section.
    CARD-0076: real field-deployed device's OTA/MQTT passwords rotated and
    verified live 2026-08-17. Immich API key rotation declined and test-rig
    reflash deferred, both recorded as deliberate decisions.
    Also: Bag 35 genuine BS250 replacement stock logged in parts inventory.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
    [hiking-monitor.yaml]
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2026-08-20 CARD-0180/0186: remote reboot from HA, fix MQTT discovery unique_id collisions
    hiking-monitor gets an HA-triggered restart button via MQTT discovery
    (discovery_unique_id_generator: mac, since it's the device's only exposed
    entity). Live testing caught two real bugs along the way: platform: restart
    doesn't wait for on_press automations to finish before rebooting (switched
    to platform: template + explicit safe_reboot lambda), and the rename that
    triggered this collided with front-porch-temp-sensor's and salt-sensor's
    own "Restart" buttons under ESPHome's default legacy id generator.
    Fixed the same collision on those two devices by giving each restart
    button a device-specific name instead of t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
    [front-porch-temp-sensor.yaml, hiking-monitor.yaml]
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2026-08-20 CARD-0012: Step 4 firmware, solar/timeout redesign, enclosure planning; bag-to-bin inventory reorg
    air-quality-monitor: add Step 4 base-validation ESPHome config; supersede the
    Timeout/timer decision now that solar and field USB charging share dock-detect
    with the home dock (field logging now runs unconditionally, dock-detect only
    triggers a bounded-attempt-window WiFi retry against JCTnet1 + a new Pixel
    hotspot fallback); correct MQTT to TLS/8883 against jctsh.duckdns.org, matching
    hiking-monitor's actual deployed config; decide SEN55 mounts externally via 3M
    tape rather than needing enclosure venting, which also resolves the perfboard
    footprint and intake/exhaust open questions; move perfb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
    [air-quality-monitor.yaml]
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2026-08-21 CARD-0012: Step 4 SEN55 bench validation complete, real bug + hardware fault found
    Fixed a real firmware bug (sen5x: platform block was missing its own id:,
    which on_boot's component.update referenced) and flashed successfully. That
    surfaced a genuine hardware fault in the SEN55 power-gate transistor circuit:
    every individual check passed (base resistor, base voltage, VIN, transistor
    swap, relocation, Collector/Emitter continuity) yet the circuit still
    wouldn't reliably power the sensor, eventually traced toward an intermittent
    breadboard contact via the adapter's power LED, not fully resolved. Step 4
    closed on a bypass jumper instead, confirming the SEN55/adapter/I2C wiring
    itself is genuin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
    [air-quality-monitor.yaml]
2026-08-22 CARD-0012: Step 5 LED boot/blink-mode, Step 6 power-gate dropped, Step 7 brownout investigation in progress
    Step 5: boot self-test LED sequence (color-blink self-check, unbounded
    wait-for-first-reading loop, solid-green confirmation, permanent
    yellow/red threshold-color hold), blink-mode operational LEDs instead of
    continuous-on. All three threshold colors confirmed live.
    Step 6: dropped the SEN55 power-gate transistor entirely -- Sensirion's own
    guidance favors I2C mode-switching over physical power-cycling for duty-cycle
    savings, and the existing inline power switch already covers true full-off.
    SEN55 now hard-wired always-on. Physically confirmed removed from the
    breadboard; step closed.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
    [air-quality-monitor.yaml]
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2026-08-23 CARD-0198: fix blind boot-delay race in air-quality-monitor, add CARD-0197/0198
    air-quality-monitor.yaml: replace the fixed ~10s delay before SEN55 resumes
    Measurement mode with a bounded wait on actual MQTT-connected state (250ms
    poll, 30s cap) -- the fixed delay was an unverified guess that WiFi
    association would always finish in time, and real log data from the
    2026-08-21 bench session (repeated "power-on event" resets, some under 2
    minutes apart) shows that guess failing in practice. Config-validated via
    `esphome config`; not yet flashed to hardware.
    tos/kanban-board.md: CARD-0197 (instrument the suspected Node-RED/Apps
    Script GPS-correlation timing race to confirm it) and CARD-0198 (th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
    [air-quality-monitor.yaml]
2026-08-23 CARD-0195/CARD-0199/CARD-0200: hiking-monitor diagnostics, upload display, cutoff fix
    hiking-monitor.yaml:
    - Skip-reason logging at both silent-return points in the field-mode
    interval lambda, and reset-reason detection (debug: + text_sensor,
    checked in on_boot) -- CARD-0195, low risk, additive only.
    - Connected/Uploading/Upload-complete-with-duration e-ink display sequence
    during post-hike MQTT replay, cleared on switch-on or dock-removed --
    CARD-0199.
    - Low-battery cutoff regated on in_field_mode instead of dock_detect --
    solar shares the same dock-detect signal as USB (power-system.md), so
    the cutoff was silently disabled any time solar was connected mid-hike,
    regardless of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
    [hiking-monitor.yaml]
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2026-08-24 Persist upload_display_state/upload_duration_ms across deep sleep (CARD-0199)
    Plain RAM globals reset to 0 on every boot, including waking from
    deep_sleep.enter -- which happens between every hike ending and the
    device getting docked. That silently reset the post-hike "Done" upload
    screen before either documented reset trigger (switch-on, dock-removed)
    ever fired, confirmed live on the 2026-08-24 hike. restore_value: true
    backs both with flash-persisted NVS storage, which survives the sleep
    cycle. Flashed OTA and confirmed booting clean; full end-to-end
    verification (Done surviving a real sleep-wake-dock cycle) waits on the
    next hike producing buffered data to replay.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
    [hiking-monitor.yaml]
2026-08-24 Log field-mode display refreshes with real event time (CARD-0196)
    Adds hike_log_write("{event:display_refresh,ts:...}") alongside each
    throttled e-ink refresh, riding the same flash-buffer-then-replay path
    CARD-0195's skip/reset records use. Real NTP timestamp is included
    deliberately -- everything in the buffer lands on the dashboard within
    the same ~1s bulk-replay burst at hike-end, so receipt time alone
    can't show the ~20min throttle cadence.
    Extends the Node-RED "Route skip/reset events" function node to also
    divert display_refresh records to the component's /log topic instead
    of letting them fall into the GPS-lookup/Sheets pipeline as malformed
    readings. Flashed OTA and live-verified e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
    [hiking-monitor.yaml]
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2026-08-24 CARD-0198: bound PM2.5-wait loop, fix debug UART pin, document battery-boot investigation
    Base platform (no SEN55) now boots reliably on battery - verified across
    4 clean power cycles. Fixed a stale-build flashing gap (esphome upload was
    flashing 3-day-old cached firmware) and an unbounded PM2.5-wait loop that
    could hang boot_sequence_done forever with SEN55 disconnected/faulty.
    Corrected CARD-0205's debug UART design: ESPHome's logger component has
    no tx_pin option, so UART2 uses its fixed GPIO17 TX pin, not GPIO27 as
    originally planned - air-quality-monitor.yaml and wiring.md both updated.
    Also fixed a missing Battery Voltage Divider branch in wiring.md's LDO
    diagram, and corrected a neve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
    [air-quality-monitor.yaml]
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
